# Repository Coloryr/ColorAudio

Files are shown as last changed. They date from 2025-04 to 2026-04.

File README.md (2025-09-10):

# ColorAudio

通用耳放，目前支持：
- 音乐播放
  - MP3音频解码，信息显示
  - FLAC音频解码，信息显示
- 蓝牙音频播放
  - SBC编码
  - AAC编码
  - aptx编码(freeaptx解码库)
- USB音频播放
  - UAC1 (最大96K 32bit，只能设置一种采样大小)
  - UAV2 (最大192K 32bit，支持多种采样大小)

主控RK3506，DAC：cs43198x2，运放：opa1622

linux6.1 RK的SDK

pcb目录是硬件原理图和PCB  
linux目录是RK SDK修补包  
src目录是软件程序源码

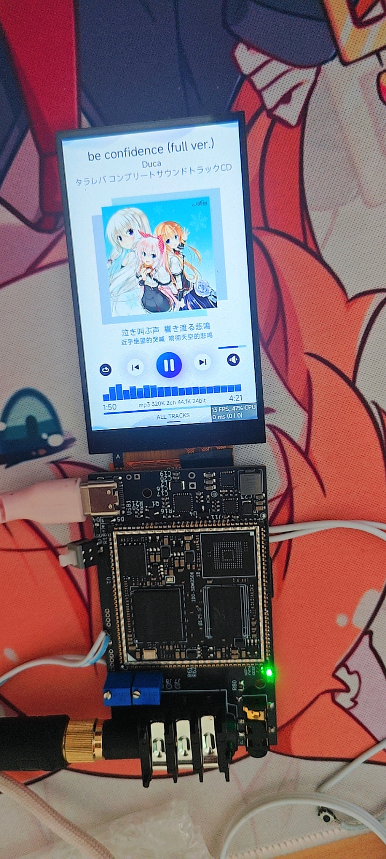
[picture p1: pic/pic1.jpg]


使用的其他开源代码库，直接使用代码编译  
| 名称  | 描述 | 链接 |
|---|---|---|
| Lvgl | 轻量界面框架 | [GitHub](https://github.com/lvgl/lvgl) |
| arduinoFFT | 快速傅里叶变换 | [GitHub](https://github.com/kosme/arduinoFFT) |
| nlohmann/json | json解析库 | [GitHub](https://github.com/nlohmann/json) |
| bluez-alsa | 蓝牙音频库 | [GitHub](https://github.com/arkq/bluez-alsa) |
| minimp4 | MP4文件解析 | [GitHub](https://github.com/lieff/minimp4) |
| ncmdump | ncm文件解析 | [GitHub](https://github.com/taurusxin/ncmdump) |

使用的开源库，使用链接方式  
| 名称  | 描述 | 链接 |
| libpng | png解码库 | [GitHub](https://github.com/pnggroup/libpng) |
| boost | C++库 | [boost](https://www.boost.org/) |
| flac | flac解码库 | [GitHub](https://github.com/xiph/flac) |
| libjpeg-turbo | jpeg解码库 | [GitHub](https://github.com/libjpeg-turbo/libjpeg-turbo) |
| libmad | MP3解码库 | [GitHub](https://github.com/markjeee/libmad) |
| openh264 | H264解码库 | [GitHub](https://github.com/cisco/openh264) |
| librime | 输入法 | [GitHub](https://github.com/rime/librime) |

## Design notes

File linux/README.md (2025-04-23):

sudo apt install flex bison bc libncurses-dev -y

# boot

export PATH=$PATH:~/Desktop/t113/arm-none-eabi/bin
git clone https://github.com/szemzoa/awboot
cd awboot
cd tools
gcc mksunxi.c -o mksunxi
cd ../
修改board.h的串口
make -j16

# linux
wget https://cdn.kernel.org/pub/linux/kernel/v6.x/linux-6.14.2.tar.xz
tar -xf linux-6.14.2.tar.xz
cd linux-6.14.2
export PATH=$PATH:~/Desktop/t113/arm-none-linux-gnueabihf/bin
make ARCH=arm CROSS_COMPILE=arm-none-linux-gnueabihf- sunxi_defconfig
make ARCH=arm CROSS_COMPILE=arm-none-linux-gnueabihf- menuconfig
make -j32 ARCH=arm CROSS_COMPILE=arm-none-linux-gnueabihf- zImage dtbs modules

# tina5
sudo apt install -y ack antlr3 asciidoc autoconf automake autopoint binutils bison build-essential \
bzip2 ccache cmake cpio curl device-tree-compiler fastjar flex gawk gettext gcc-multilib g++-multilib \
git gperf haveged help2man intltool libc6-dev-i386 libelf-dev libfuse-dev libglib2.0-dev libgmp3-dev \
libltdl-dev libmpc-dev libmpfr-dev libncurses5-dev libncursesw5-dev libpython3-dev libreadline-dev \
libssl-dev libtool lrzsz mkisofs msmtp ninja-build p7zip p7zip-full patch pkgconf python2.7 python3 \
python3-pyelftools python3-setuptools qemu-utils rsync scons squashfs-tools subversion swig texinfo \
uglifyjs upx-ucl unzip vim wget xmlto xxd zlib1g-dev

sudo -i
curl https://mirrors.bfsu.edu.cn/git/git-repo > /usr/bin/repo
chmod +x /usr/bin/repo
exit
echo export REPO_URL='https://mirrors.bfsu.edu.cn/git/git-repo' >> ~/.bashrc
source ~/.bashrc
git config --global credential.helper store 

mkdir tina-sdk
cd tina-sdk
repo init -u https://sdk.aw-ol.com/git_repo/D1_Tina_Open/manifest.git -b master -m tina-d1-h.xml
repo sync
repo start coloraudio --all
cd ../

git clone https://github.com/DongshanPI/100ASK_T113-PRO_TinaSDK5.git
cd 100ASK_T113-PRO_TinaSDK5
git submodule update --init 
cp ./* -rfvd ../tina-sdk
cd ../

git clone https://github.com/DongshanPI/100ASK_T113-Pro_TinaSDK.git
cd 100ASK_T113-Pro_TinaSDK 
git submodule update --init 
cp ./* -rfvd ../tina-sdk
cd ../

repo forall -vc "git status"
repo forall -vc "git reset --hard"

cd tina-sdk
source build/envsetup.sh
lunch

# buildroot
wget https://buildroot.org/downloads/buildroot-2025.02.tar.gz
tar -zxf buildroot-2025.02.tar.gz
cd buildroot-2025.02
make menuconfig

# xfel
https://github.com/xboot/xfel
xfel version
xfel spinand
xfel spinand erase 0 0x8000000
xfel spinand write 0 awboot-boot-spi.bin
xfel spinand write 0x40000 arch/arm/boot/dts/sun8i-t113s-coloraudio-t113-v1.dtb
xfel spinand write 0x80000 arch/arm/boot/zImage

xfel spinand erase 0x800000 0x7800000
xfel spinand write 0x800000 output/images/rootfs.ubi

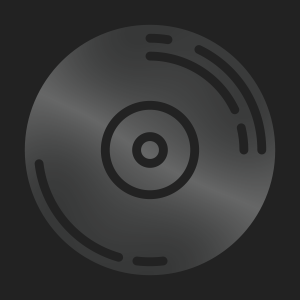
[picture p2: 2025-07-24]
ui/record.png

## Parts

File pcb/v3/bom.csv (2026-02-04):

Reference | Qty | Value | Footprint | 单价 | 总计
C1,C2,C3,C7,C8,C23,C25,C26,C27 | 9 | 22uF | Capacitor_SMD:C_0603_1608Metric_Pad1.08x0.95mm_HandSolder | 0.066 | 0.594
C4,C5,C10,C12,C13,C14,C18,C19,C20,C28,C42,C43,C51,C65,C74,C78 | 16 | 10uF | Capacitor_SMD:C_0402_1005Metric_Pad0.74x0.62mm_HandSolder | 0.0385 | 0.616
C6,C29,C32,C33,C34,C35,C37,C38,C41,C44,C45,C46,C50,C59,C60,C64,C80,C81 | 18 | 0.1uF | Capacitor_SMD:C_0402_1005Metric_Pad0.74x0.62mm_HandSolder | 0.0165 | 0.297
C9,C11,C15,C21,C22,C30,C31 | 7 | 1uF | Capacitor_SMD:C_0402_1005Metric_Pad0.74x0.62mm_HandSolder | 0.022 | 0.154
C16 | 1 | 47nF | Capacitor_SMD:C_0402_1005Metric_Pad0.74x0.62mm_HandSolder | 0.0165 | 0.0165
C17,C39 | 2 | 4.7uF | Capacitor_SMD:C_0402_1005Metric_Pad0.74x0.62mm_HandSolder | 0.033 | 0.066
C24 | 1 | 10nF | Capacitor_SMD:C_0402_1005Metric_Pad0.74x0.62mm_HandSolder | 0.0165 | 0.0165
C36,C79 | 2 | 10uF | Capacitor_SMD:C_0603_1608Metric_Pad1.08x0.95mm_HandSolder | 0.044 | 0.088
C40 | 1 | 100nF | Capacitor_SMD:C_0402_1005Metric_Pad0.74x0.62mm_HandSolder | 0.0165 | 0.0165
C47,C48,C49,C54,C55,C56,C57,C58,C61,C62,C63,C68,C69,C70,C71,C72 | 16 | 2.2uF | Capacitor_SMD:C_0402_1005Metric_Pad0.74x0.62mm_HandSolder | 0.0275 | 0.44
C52,C53,C66,C67 | 4 | 15uF | Capacitor_SMD:C_0402_1005Metric_Pad0.74x0.62mm_HandSolder | 0.2 | 0.8
C73,C77 | 2 | 1.0uF | Capacitor_SMD:C_0402_1005Metric_Pad0.74x0.62mm_HandSolder | 0.022 | 0.044
C75,C76 | 2 | 4.7nf | Capacitor_SMD:C_0805_2012Metric_Pad1.18x1.45mm_HandSolder | 0.055 | 0.11
CN1 | 1 | PJ-625G | coloryr:AUDIO-TH_PJ-625G | 3.02 | 3.02
D1,D4,D5,D16 | 4 | 1N5819 | Diode_SMD:D_SOD-323_HandSoldering | 0.033 | 0.132
D2,D3,D8,D9,D10,D11,D12,D13 | 8 | ESD9B5.0ST5G | Diode_SMD:D_SOD-523 | 0.044 | 0.352
D6,D7 | 2 | LED | Diode_SMD:D_0402_1005Metric_Pad0.77x0.64mm_HandSolder | 0.044 | 0.088
J1,J3,J5,J6,J7,J8,J11,J14,J15 | 9 | TestPoint | TestPoint:TestPoint_Pad_D1.0mm | 0 | 0
J2 | 1 | Conn_01x03 | Connector_PinHeader_1.27mm:PinHeader_1x03_P1.27mm_Vertical | 0 | 0
J4,J10 | 2 | Conn_01x02 | Connector_PinHeader_2.00mm:PinHeader_1x02_P2.00mm_Vertical | 0 | 0
J9 | 1 | Conn_01x02 | Connector_PinHeader_2.54mm:PinHeader_1x02_P2.54mm_Vertical | 0 | 0
J12 | 1 | Conn_01x04 | Connector_PinHeader_1.27mm:PinHeader_1x04_P1.27mm_Vertical | 0 | 0
J13 | 1 | Conn_01x05 | Connector_PinHeader_1.27mm:PinHeader_1x05_P1.27mm_Vertical | 0 | 0
L1,L2 | 2 | 2,2uH | Inductor_SMD:L_1008_2520Metric_Pad1.43x2.20mm_HandSolder | 0.3 | 0.6
L3 | 1 | 1.0uH | Inductor_SMD:L_Changjiang_FXL0530 | 0.39 | 0.39
L4 | 1 | 10uH | Inductor_SMD:L_TDK_NLV25_2.5x2.0mm | 0.3 | 0.3
P1 | 1 | LCD_MIPI | Connector_FFC-FPC:Hirose_FH12-24S-0.5SH_1x24-1MP_P0.50mm_Horizontal | 0.3 | 0.3
P2 | 1 | LCD_TOUCH | Connector_FFC-FPC:Hirose_FH12-6S-0.5SH_1x06-1MP_P0.50mm_Horizontal | 0.24 | 0.24
PJ1 | 1 | ~ | coloryr:AUDIO-IN-SMD_PJ-327A_C22355751 | 0.28 | 0.28
Q1 | 1 | NPN | coloryr:SOT-23 | 0.11 | 0.11
Q2 | 1 | PMOS | coloryr:SOT-23 | 1.21 | 1.21
Q3 | 1 | NMOS | coloryr:SOT-23 | 3.19 | 3.19
R1,R12,R59,R60,R63,R64,R81,R85,R90,R91 | 10 | 0 | Resistor_SMD:R_0402_1005Metric_Pad0.72x0.64mm_HandSolder | 0.0132 | 0.132
R2,R18,R19,R20,R22,R47,R75,R95 | 8 | 10K | Resistor_SMD:R_0402_1005Metric_Pad0.72x0.64mm_HandSolder | 0.0132 | 0.1056
R3,R4,R6,R51 | 4 | 100 | Resistor_SMD:R_0402_1005Metric_Pad0.72x0.64mm_HandSolder | 0.0132 | 0.0528
R5,R28,R29,R30,R31,R32,R33 | 7 | 4.7K | Resistor_SMD:R_0402_1005Metric_Pad0.72x0.64mm_HandSolder | 0.0132 | 0.0924
R7,R8 | 2 | 2.2R | Capacitor_SMD:C_0402_1005Metric_Pad0.74x0.62mm_HandSolder | 0.0132 | 0.0264
R9,R25 | 2 | 100K | Capacitor_SMD:C_0402_1005Metric_Pad0.74x0.62mm_HandSolder | 0.0132 | 0.0264
R10 | 1 | 750K | Capacitor_SMD:C_0402_1005Metric_Pad0.74x0.62mm_HandSolder | 0.0132 | 0.0132
R11 | 1 | 240K | Capacitor_SMD:C_0402_1005Metric_Pad0.74x0.62mm_HandSolder | 0.0132 | 0.0132
R13 | 1 | 220K | Capacitor_SMD:C_0402_1005Metric_Pad0.74x0.62mm_HandSolder | 0.0132 | 0.0132
R14 | 1 | 510K | Capacitor_SMD:C_0402_1005Metric_Pad0.74x0.62mm_HandSolder | 0.0132 | 0.0132
R15 | 1 | 260 | Capacitor_SMD:C_0402_1005Metric_Pad0.74x0.62mm_HandSolder | 0.0132 | 0.0132
R16,R17,R26,R27,R55,R57,R87 | 7 | 10K | Capacitor_SMD:C_0402_1005Metric_Pad0.74x0.62mm_HandSolder | 0.0132 | 0.0924
R21,R46 | 2 | 1K | Resistor_SMD:R_0402_1005Metric_Pad0.72x0.64mm_HandSolder | 0.0132 | 0.0264
R23 | 1 | 12K | Capacitor_SMD:C_0402_1005Metric_Pad0.74x0.62mm_HandSolder | 0.0132 | 0.0132
R24 | 1 | 390K | Capacitor_SMD:C_0402_1005Metric_Pad0.74x0.62mm_HandSolder | 0.0132 | 0.0132
R34,R35,R36,R37,R38,R39,R40,R41,R42,R43,R80,R88 | 12 | 4.7K | Capacitor_SMD:C_0402_1005Metric_Pad0.74x0.62mm_HandSolder | 0.0132 | 0.1584
R44,R93 | 2 | 330K | Resistor_SMD:R_0402_1005Metric_Pad0.72x0.64mm_HandSolder | 0.0132 | 0.0264
R45 | 1 | 10 | Resistor_SMD:R_0805_2012Metric | 0.0165 | 0.0165
R48 | 1 | 12K | Resistor_SMD:R_0402_1005Metric_Pad0.72x0.64mm_HandSolder | 0.0132 | 0.0132
R49 | 1 | 5.1K | Resistor_SMD:R_0402_1005Metric_Pad0.72x0.64mm_HandSolder | 0.0132 | 0.0132
R50 | 1 | 3K | Resistor_SMD:R_0402_1005Metric_Pad0.72x0.64mm_HandSolder | 0.0132 | 0.0132
R52 | 1 | 100K | Resistor_SMD:R_0402_1005Metric_Pad0.72x0.64mm_HandSolder | 0.0132 | 0.0132
R53 | 1 | 150K | Resistor_SMD:R_0402_1005Metric_Pad0.72x0.64mm_HandSolder | 0.0132 | 0.0132
R54,R56 | 2 | 3.3K | Capacitor_SMD:C_0402_1005Metric_Pad0.74x0.62mm_HandSolder | 0.0132 | 0.0264
R58 | 1 | 30K | Capacitor_SMD:C_0402_1005Metric_Pad0.74x0.62mm_HandSolder | 0.0132 | 0.0132
R61,R62,R65,R66 | 4 | 50 | Resistor_SMD:R_0805_2012Metric | 0.0165 | 0.066
R67,R69 | 2 | 510 | Resistor_SMD:R_0805_2012Metric | 0.0165 | 0.033
R68,R70 | 2 | 71.5 | Resistor_SMD:R_0805_2012Metric | 0.0165 | 0.033
R71,R72 | 2 | 82 | Resistor_SMD:R_0805_2012Metric | 0.0165 | 0.033
R73,R74,R76,R77,R78,R79 | 6 | 0 | Resistor_SMD:R_0805_2012Metric | 0.0165 | 0.099
R82,R83 | 2 | 5.1K | Capacitor_SMD:C_0402_1005Metric_Pad0.74x0.62mm_HandSolder | 0.0165 | 0.033
R84 | 1 | 22.6K | Capacitor_SMD:C_0402_1005Metric_Pad0.74x0.62mm_HandSolder | 0.0165 | 0.0165
R86 | 1 | 12.7K | Capacitor_SMD:C_0402_1005Metric_Pad0.74x0.62mm_HandSolder | 0.0165 | 0.0165
R89,R92,R94,R96,R97,R98 | 6 | 22 | Capacitor_SMD:C_0402_1005Metric_Pad0.74x0.62mm_HandSolder | 0.0165 | 0.099
RF1 | 1 | 6GHz | coloryr:IPEX-SMD_BWIPX-3-001E-1 | 0.38 | 0.38
RV1,RV2 | 2 | R_Potentiometer | Potentiometer_SMD:Potentiometer_Bourns_TC33X_Vertical | 1.9 | 3.8
TF1 | 1 | Micro_SD_Card_Det1 | coloryr:TF-SMD_TF-PUSH | 0.24 | 0.24
U1 | 1 | SOM3562_18 | coloryr:rk3506 | 65 | 65
U2 | 1 | TLV6213x | Package_DFN_QFN:VQFN-16-1EP_3x3mm_P0.5mm_EP1.68x1.68mm_ThermalVias | 1.81 | 1.81
U3 | 1 | RT9013 | Package_TO_SOT_SMD:SOT-23-5 | 0.48 | 0.48
U4 | 1 | BQ25895RTW | Package_DFN_QFN:Texas_RTW_WQFN-24-1EP_4x4mm_P0.5mm_EP2.7x2.7mm_ThermalVias | 4.7 | 4.7
U5 | 1 | LM27762 | Package_SON:WSON-12-1EP_3x2mm_P0.5mm_EP1x2.65_ThermalVias | 3.78 | 3.78
U6 | 1 | LP5907MFX-3.3 | Package_TO_SOT_SMD:SOT-23-5 | 0.42 | 0.42
U7 | 1 | TPS61230DRC | Package_SON:Texas_S-PVSON-N10_ThermalVias | 3 | 3
U8 | 1 | M8800DU6 | coloryr:BL_M8800DU6_40L | 15 | 15
U9 | 1 | SY6280 | Package_TO_SOT_SMD:SOT-23-5 | 0.31 | 0.31
U10 | 1 | STI9287 | Package_TO_SOT_SMD:SOT-23-6_Handsoldering | 0.24 | 0.24
U11 | 1 | TXS0102DCU | Package_SON:X2SON-8_1.4x1mm_P0.35mm | 0.69 | 0.69
U12 | 1 | SN74AVC4T245PW | Package_DFN_QFN:UQFN-16_1.8x2.6mm_P0.4mm | 0.99 | 0.99
U13 | 1 | TS3A227E | Package_DFN_QFN:Texas_RVA_VQFN-16-1EP_3.5x3.5mm_P0.5mm_EP2.14x2.14mm | 5.93 | 5.93
U14,U15 | 2 | CS43198 | Package_DFN_QFN:QFN-40-1EP_5x5mm_P0.4mm_EP3.6x3.6mm_ThermalVias | 19 | 38
U16 | 1 | OPA1622 | Package_SON:Texas_S-PVSON-N10 | 5.68 | 5.68
USB1 | 1 | USB_C_Plug_USB2.0 | Connector_USB:USB_C_Receptacle_GCT_USB4105-xx-A_16P_TopMnt_Horizontal | 0.17 | 0.17
Y1 | 1 | 24.576M | Oscillator:Oscillator_SMD_ECS_2520MV-xxx-xx-4Pin_2.5x2.0mm | 1.8 | 1.8
LCD1 | 1 | D310T9362V1 |  | 65 | 65
BAT | 1 | 8000mah |  | 20 | 20
 |  |  |  |  | 252.2732

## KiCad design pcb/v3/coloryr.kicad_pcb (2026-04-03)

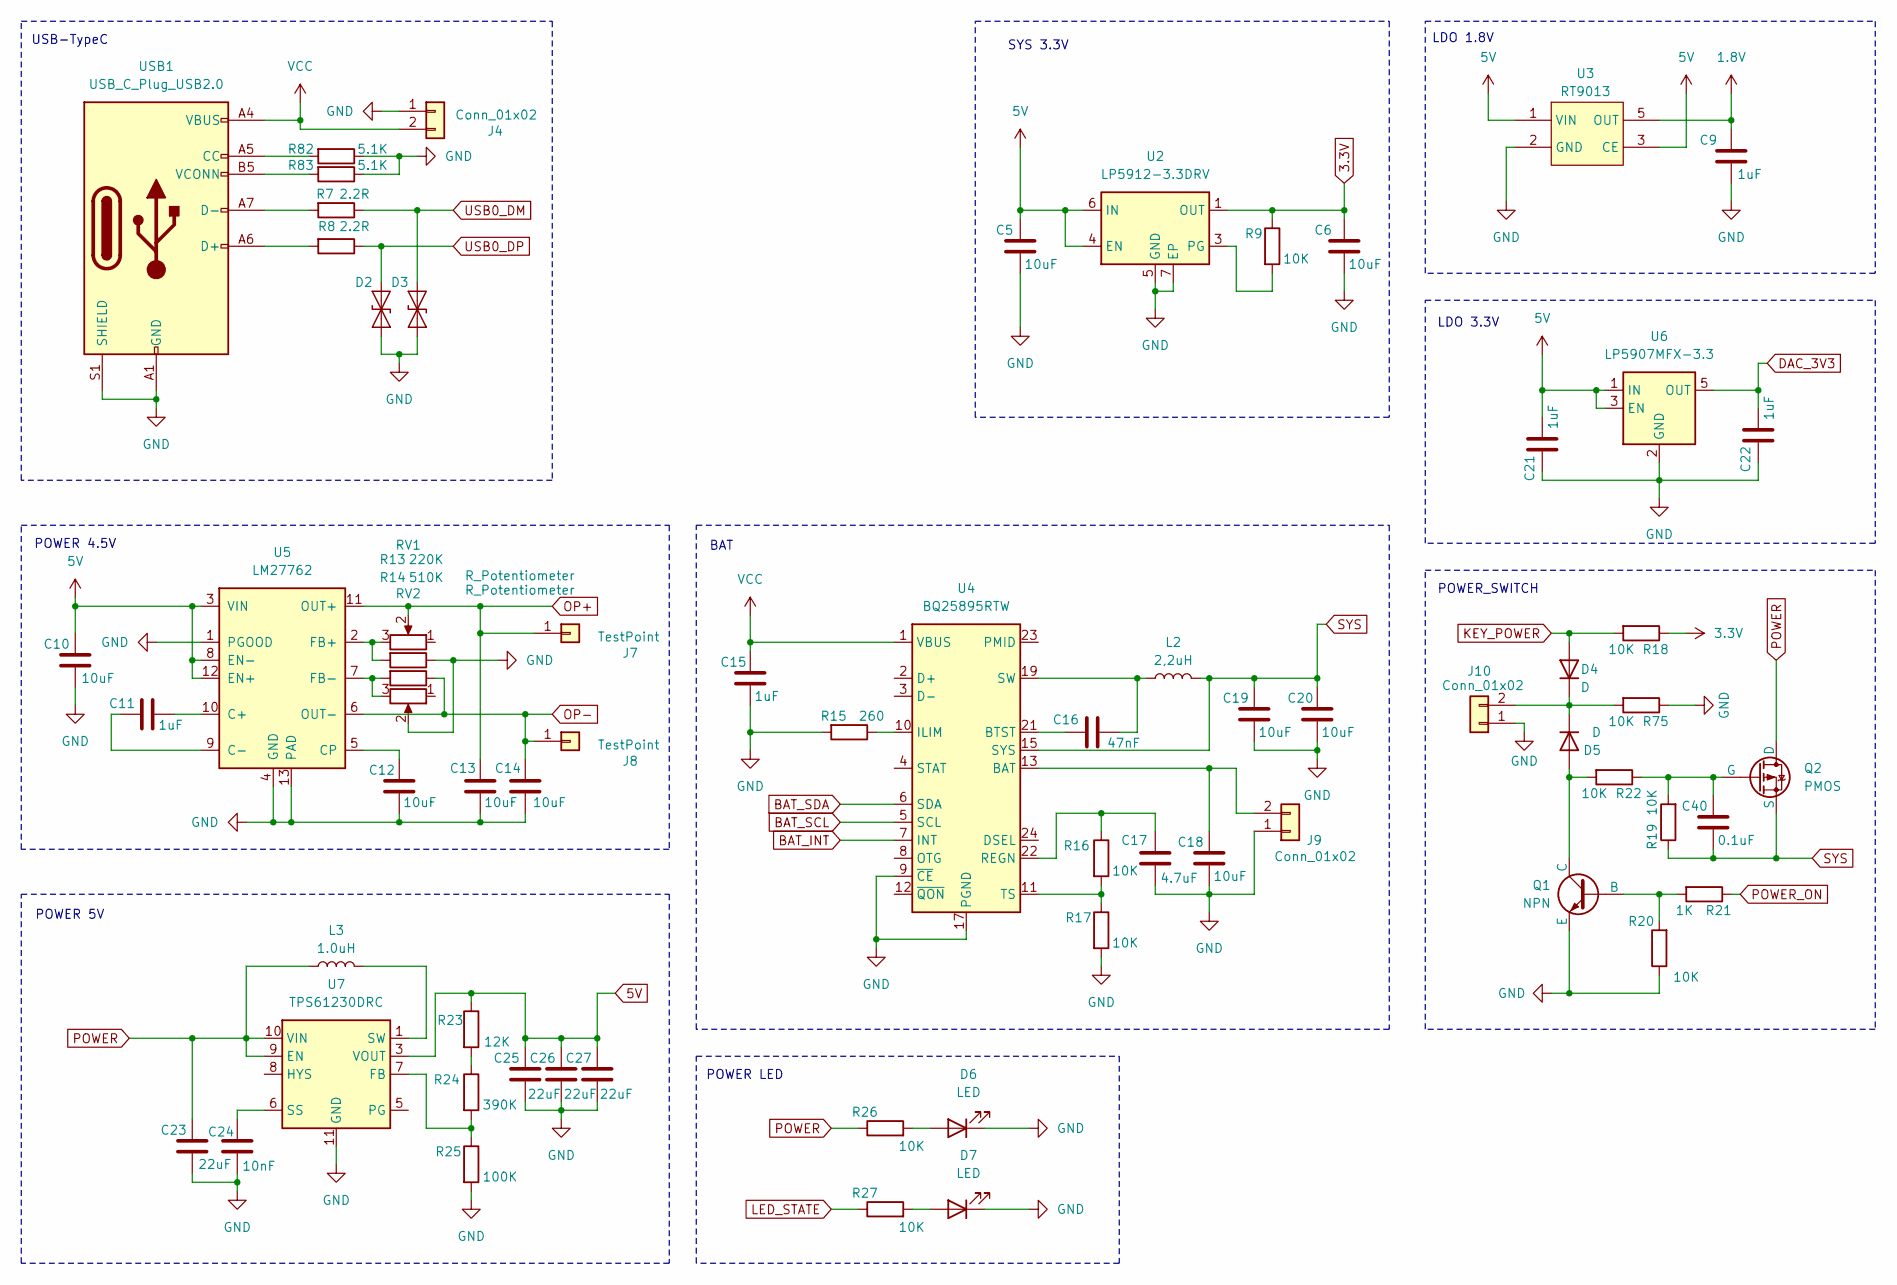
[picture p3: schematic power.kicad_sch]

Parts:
C5, C6, C10, C12, C13, C14, C18, C19, C20: 10uF; C_0402_1005Metric_Pad0.74x0.62mm_HandSolder
C9, C11, C15, C21, C22: 1uF; C_0402_1005Metric_Pad0.74x0.62mm_HandSolder
C16: 47nF; C_0402_1005Metric_Pad0.74x0.62mm_HandSolder
C17: 4.7uF; C_0402_1005Metric_Pad0.74x0.62mm_HandSolder
C23, C25, C26, C27: 22uF; C_0603_1608Metric_Pad1.08x0.95mm_HandSolder
C24: 10nF; C_0402_1005Metric_Pad0.74x0.62mm_HandSolder
C40: 0.1uF; C_0402_1005Metric_Pad0.74x0.62mm_HandSolder
D2, D3: ESD9B5.0ST5G; D_SOD-523
D4, D5: D; D_SOD-323_HandSoldering
D6, D7: LED; D_0402_1005Metric_Pad0.77x0.64mm_HandSolder
J4, J10: Conn_01x02; PinHeader_1x02_P2.00mm_Vertical
J7, J8: TestPoint; TestPoint_Pad_D1.0mm
J9: Conn_01x02; PinHeader_1x02_P2.54mm_Vertical
L2: 2,2uH; L_1008_2520Metric_Pad1.43x2.20mm_HandSolder
L3: 1.0uH; L_Changjiang_FXL0530
Q1: NPN; SOT-23
Q2: PMOS; SOT-23
R7, R8: 2.2R; C_0402_1005Metric_Pad0.74x0.62mm_HandSolder
R9, R16, R17, R26, R27: 10K; C_0402_1005Metric_Pad0.74x0.62mm_HandSolder
R13: 220K; C_0402_1005Metric_Pad0.74x0.62mm_HandSolder
R14: 510K; C_0402_1005Metric_Pad0.74x0.62mm_HandSolder
R15: 260; C_0402_1005Metric_Pad0.74x0.62mm_HandSolder
R18, R19, R20, R22, R75: 10K; R_0402_1005Metric_Pad0.72x0.64mm_HandSolder
R21: 1K; R_0402_1005Metric_Pad0.72x0.64mm_HandSolder
R23: 12K; C_0402_1005Metric_Pad0.74x0.62mm_HandSolder
R24: 390K; C_0402_1005Metric_Pad0.74x0.62mm_HandSolder
R25: 100K; C_0402_1005Metric_Pad0.74x0.62mm_HandSolder
R82, R83: 5.1K; C_0402_1005Metric_Pad0.74x0.62mm_HandSolder
RV1, RV2: R_Potentiometer; Potentiometer_Bourns_TC33X_Vertical
U2: LP5912-3.3DRV; WSON-6-1EP_2x2mm_P0.65mm_EP1x1.6mm_ThermalVias
U3: RT9013; SOT-23-5
U4: BQ25895RTW; Texas_RTW_WQFN-24-1EP_4x4mm_P0.5mm_EP2.7x2.7mm_ThermalVias
U5: LM27762; WSON-12-1EP_3x2mm_P0.5mm_EP1x2.65_ThermalVias
U6: LP5907MFX-3.3; SOT-23-5
U7: TPS61230DRC; Texas_S-PVSON-N10_ThermalVias
USB1: USB_C_Plug_USB2.0; USB_C_Receptacle_GCT_USB4105-xx-A_16P_TopMnt_Horizontal

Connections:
1.8V: C9.1, U3.5 (OUT); also elsewhere on the board
3.3V: C6.1, R9.1, R18.1, U2.1 (OUT); also elsewhere on the board
5V: C5.1, C10.1, C21.1, C25.1, C26.1, C27.1, R23.1, U2.4 (EN), U2.6 (IN), U3.1 (VIN), U3.3 (CE), U5.3 (VIN), U5.8 (EN-), U5.12 (EN+), U6.1 (IN), U6.3 (EN), U7.3 (VOUT), U7.4 (VOUT); also elsewhere on the board
BAT_INT: U4.7 (INT); also elsewhere on the board
BAT_SCL: U4.5 (SCL); also elsewhere on the board
BAT_SDA: U4.6 (SDA); also elsewhere on the board
DAC_3V3: C22.1, U6.5 (OUT); also elsewhere on the board
GND: C5.2, C6.2, C9.2, C10.2, C12.1, C13.1, C14.1, C15.2, C17.1, C18.2, C19.2, C20.2, C21.2, C22.2, C23.2, C24.1, C25.2, C26.2, C27.2, D2.1 (A1), D3.1 (A1), D6.1 (K), D7.1 (K), J4.1, J9.1, J10.1, Q1.3 (E), R13.1, R15.2, R17.2, R20.1, R25.2, R75.1, R82.1, R83.1, RV2.2, U2.5 (GND), U2.7 (EP), U3.2 (GND), U4.9 (~CE), U4.17 (PGND), U4.18 (PGND), U4.25 (PGND), U5.1 (PGOOD), U5.4 (GND), U5.13 (PAD), U6.2 (GND), U7.11 (GND), USB1.A1 (GND), USB1.A12 (GND), USB1.B1 (GND), USB1.B12 (GND), USB1.S1 (SHIELD); also elsewhere on the board
KEY_POWER: D4.2 (A), R18.2; also elsewhere on the board
LED_STATE: R27.1; also elsewhere on the board
unnamed: C16.2, L2.1, U4.19 (SW), U4.20 (SW)
unnamed: D4.1 (K), D5.1 (K), J10.2, R75.2
unnamed: D5.2 (A), Q1.1 (C), R22.2
unnamed: D6.2 (A), R26.2
unnamed: D7.2 (A), R27.2
unnamed: C18.1, J9.2, U4.13 (BAT), U4.14 (BAT)
unnamed: L3.2, U7.1 (SW), U7.2 (SW)
unnamed: Q1.2 (B), R20.2, R21.2
unnamed: C40.1, Q2.2 (G), R19.2, R22.1
unnamed: R7.2, USB1.A7 (D-), USB1.B7 (D-)
unnamed: R8.2, USB1.A6 (D+), USB1.B6 (D+)
unnamed: R23.2, R24.1
unnamed: R9.2, U2.3 (PG)
unnamed: C16.1, U4.21 (BTST)
unnamed: R15.1, U4.10 (ILIM)
unnamed: C17.2, R16.1, U4.22 (REGN)
unnamed: R16.2, R17.1, U4.11 (TS)
unnamed: C11.2, U5.10 (C+)
unnamed: C11.1, U5.9 (C-)
unnamed: C12.2, U5.5 (CP)
unnamed: R13.2, RV1.3, U5.2 (FB+)
unnamed: R14.2, RV2.3, U5.7 (FB-)
unnamed: R24.2, R25.1, U7.7 (FB)
unnamed: C24.2, U7.6 (SS)
unnamed: R82.2, USB1.A5 (CC)
unnamed: R83.2, USB1.B5 (VCONN)
OP+: C13.2, J7.1, RV1.2, U5.11 (OUT+); also elsewhere on the board
OP-: C14.2, J8.1, R14.1, U5.6 (OUT-); also elsewhere on the board
POWER: C23.1, L3.1, Q2.1 (D), R26.1, U7.9 (EN), U7.10 (VIN)
POWER_ON: R21.1; also elsewhere on the board
SYS: C19.1, C20.1, C40.2, L2.2, Q2.3 (S), R19.1, U4.15 (SYS), U4.16 (SYS)
USB0_DM: D3.2 (A2), R7.1; also elsewhere on the board
USB0_DP: D2.2 (A2), R8.1; also elsewhere on the board
VCC: C15.1, J4.2, U4.1 (VBUS), USB1.A4 (VBUS), USB1.A9 (VBUS), USB1.B4 (VBUS), USB1.B9 (VBUS); also elsewhere on the board

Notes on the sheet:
POWER LED
BAT
LDO 3.3V
POWER_SWITCH
LDO 1.8V
SYS 3.3V
POWER 4.5V
USB-TypeC
POWER 5V

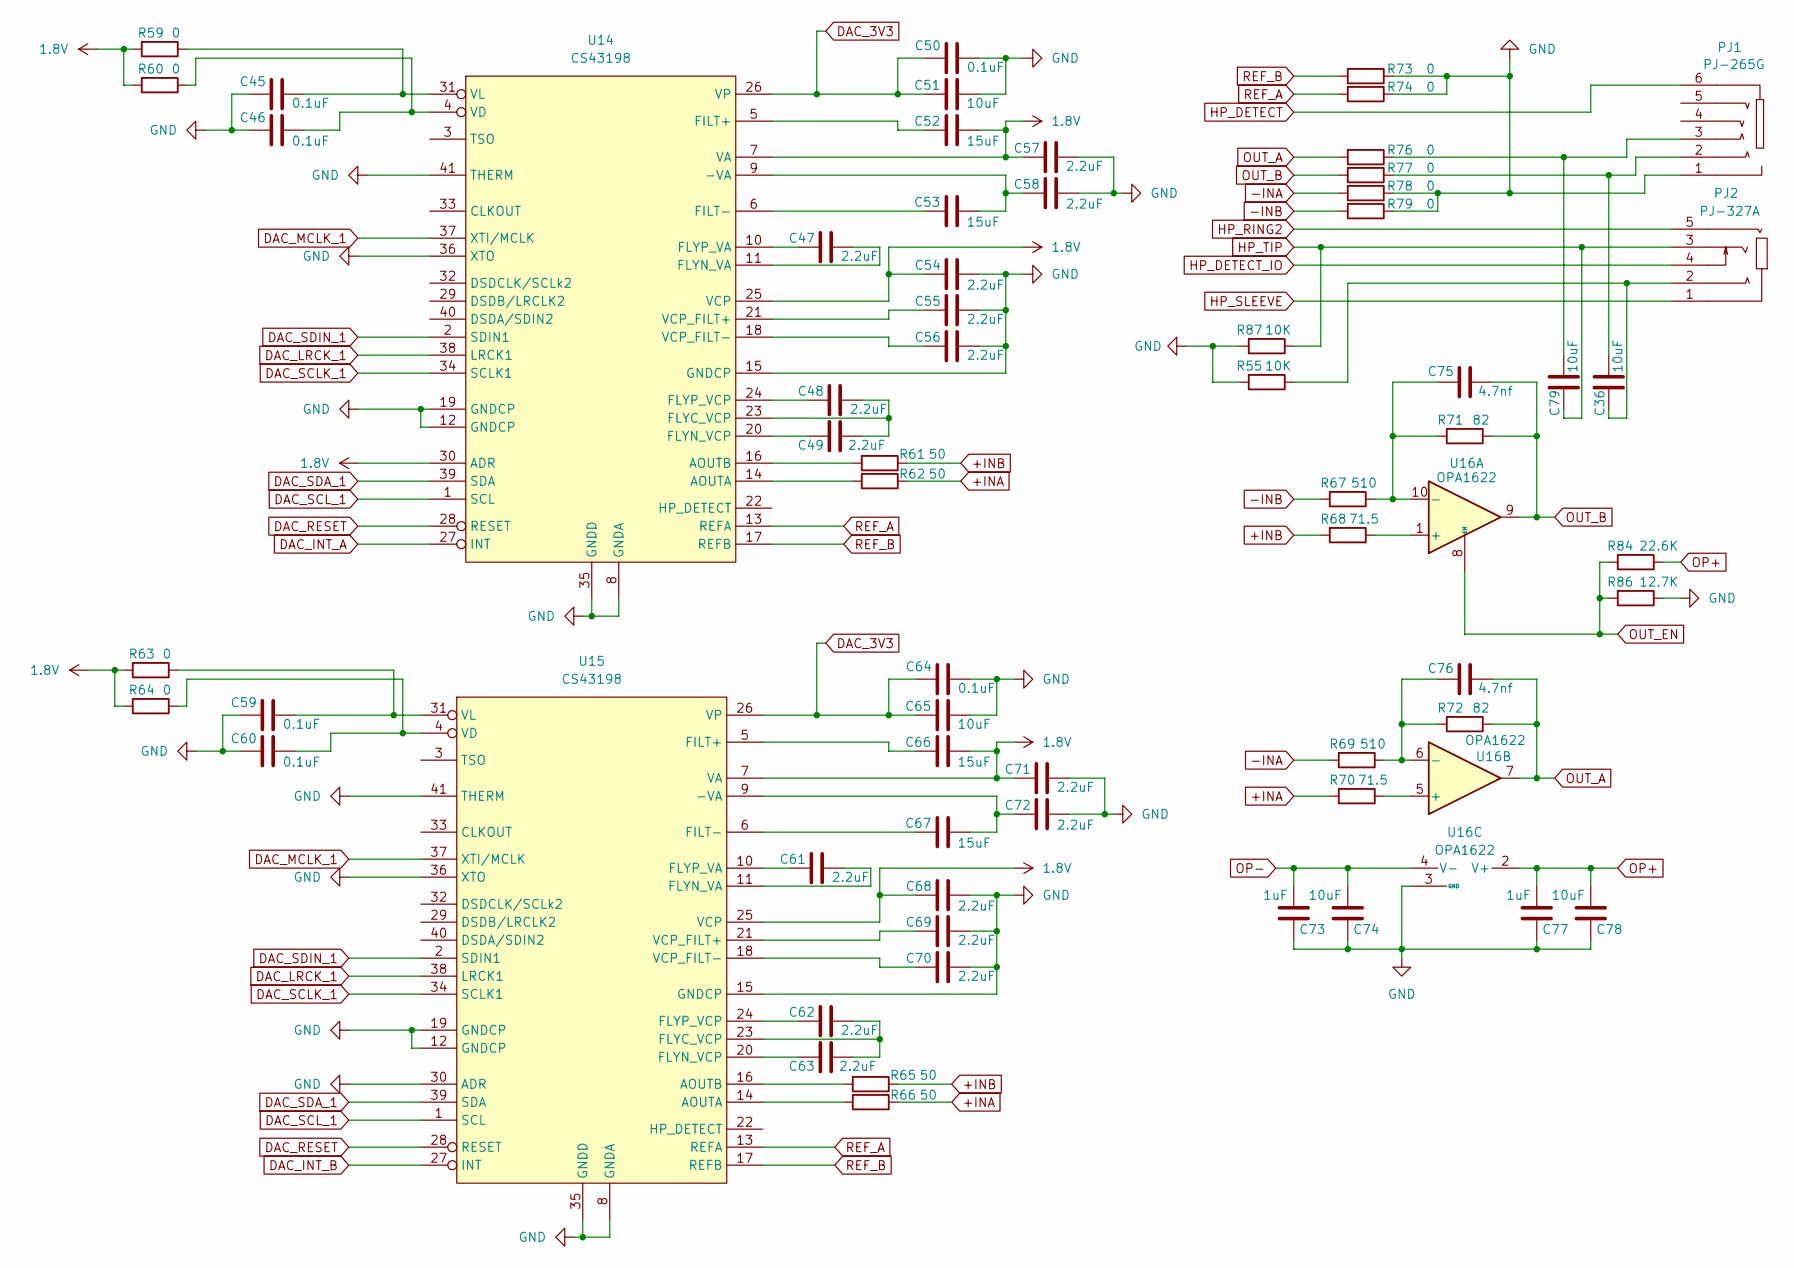
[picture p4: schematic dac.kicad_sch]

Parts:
C36, C79: 10uF; C_0603_1608Metric_Pad1.08x0.95mm_HandSolder
C45, C46, C50, C59, C60, C64: 0.1uF; C_0402_1005Metric_Pad0.74x0.62mm_HandSolder
C47, C48, C49, C54, C55, C56, C57, C58, C61, C62, C63, C68, C69, C70, C71, C72: 2.2uF; C_0402_1005Metric_Pad0.74x0.62mm_HandSolder
C51, C65, C74, C78: 10uF; C_0402_1005Metric_Pad0.74x0.62mm_HandSolder
C52, C53, C66, C67: 15uF; C_0402_1005Metric_Pad0.74x0.62mm_HandSolder
C73, C77: 1uF; C_0402_1005Metric_Pad0.74x0.62mm_HandSolder
C75, C76: 4.7nf; C_0805_2012Metric_Pad1.18x1.45mm_HandSolder
PJ1: PJ-265G; PinHeader_1x06_P2.54mm_Vertical
PJ2: PJ-327A; PinHeader_1x05_P2.54mm_Vertical; Manufacturer Part PJ-327A; LCSC Part Name 3.5mm耳机座
R55, R87: 10K; C_0402_1005Metric_Pad0.74x0.62mm_HandSolder
R59, R60, R63, R64: 0; R_0402_1005Metric_Pad0.72x0.64mm_HandSolder
R61, R62, R65, R66: 50; R_0805_2012Metric
R67, R69: 510; R_0805_2012Metric
R68, R70: 71.5; R_0805_2012Metric
R71, R72: 82; R_0805_2012Metric
R73, R74, R76, R77, R78, R79: 0; R_0805_2012Metric
R84: 22.6K; C_0402_1005Metric_Pad0.74x0.62mm_HandSolder
R86: 12.7K; C_0402_1005Metric_Pad0.74x0.62mm_HandSolder
U14, U15: CS43198; QFN-40-1EP_5x5mm_P0.4mm_EP3.6x3.6mm_ThermalVias
U16: OPA1622; Texas_S-PVSON-N10

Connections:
1.8V: C52.2, C54.2, C57.2, C66.2, C68.2, C71.2, R59.2, R60.2, R63.2, R64.2, U14.7 (VA), U14.25 (VCP), U14.30 (ADR), U15.7 (VA), U15.25 (VCP); also elsewhere on the board
+INA: R62.1, R66.1, R70.2
+INB: R61.1, R65.1, R68.2
-INA: R69.2, R78.2
-INB: R67.2, R79.2
DAC_3V3: C50.2, C51.1, C64.2, C65.1, U14.26 (VP), U15.26 (VP); also elsewhere on the board
DAC_INT_A: U14.27 (INT); also elsewhere on the board
DAC_INT_B: U15.27 (INT); also elsewhere on the board
DAC_LRCK_1: U14.38 (LRCK1), U15.38 (LRCK1); also elsewhere on the board
DAC_MCLK_1: U14.37 (XTI/MCLK), U15.37 (XTI/MCLK); also elsewhere on the board
DAC_RESET: U14.28 (RESET), U15.28 (RESET); also elsewhere on the board
DAC_SCLK_1: U14.34 (SCLK1), U15.34 (SCLK1); also elsewhere on the board
DAC_SCL_1: U14.1 (SCL), U15.1 (SCL); also elsewhere on the board
DAC_SDA_1: U14.39 (SDA), U15.39 (SDA); also elsewhere on the board
DAC_SDIN_1: U14.2 (SDIN1), U15.2 (SDIN1); also elsewhere on the board
GND: C45.2, C46.2, C50.1, C51.2, C54.1, C55.1, C56.1, C57.1, C58.1, C59.2, C60.2, C64.1, C65.2, C68.1, C69.1, C70.1, C71.1, C72.1, C73.1, C74.1, C77.1, C78.1, PJ1.1, R55.2, R73.1, R74.1, R78.1, R79.1, R86.1, R87.2, U14.8 (GNDA), U14.12 (GNDCP), U14.15 (GNDCP), U14.19 (GNDCP), U14.35 (GNDD), U14.36 (XTO), U14.41 (THERM), U15.8 (GNDA), U15.12 (GNDCP), U15.15 (GNDCP), U15.19 (GNDCP), U15.30 (ADR), U15.35 (GNDD), U15.36 (XTO), U15.41 (THERM), U16.3 (GND); also elsewhere on the board
HP_DETECT: PJ1.6; also elsewhere on the board
HP_DETECT_IO: PJ2.4; also elsewhere on the board
HP_RING2: PJ2.5; also elsewhere on the board
HP_SLEEVE: PJ2.1; also elsewhere on the board
HP_TIP: C79.1, PJ2.3, R87.1; also elsewhere on the board
unnamed: C36.1, PJ2.2, R55.1
unnamed: C36.2, PJ1.2, R77.1
unnamed: C79.2, PJ1.3, R76.1
unnamed: C53.2, C58.2, U14.9 (-VA)
unnamed: R62.2, U14.14 (AOUTA)
unnamed: R61.2, U14.16 (AOUTB)
unnamed: C52.1, U14.5 (FILT+)
unnamed: C53.1, U14.6 (FILT-)
unnamed: C48.1, C49.1, U14.23 (FLYC_VCP)
unnamed: C47.1, U14.11 (FLYN_VA)
unnamed: C49.2, U14.20 (FLYN_VCP)
unnamed: C47.2, U14.10 (FLYP_VA)
unnamed: C48.2, U14.24 (FLYP_VCP)
unnamed: C55.2, U14.21 (VCP_FILT+)
unnamed: C56.2, U14.18 (VCP_FILT-)
unnamed: C46.1, R60.1, U14.4 (VD)
unnamed: C45.1, R59.1, U14.31 (VL)
unnamed: C67.2, C72.2, U15.9 (-VA)
unnamed: R66.2, U15.14 (AOUTA)
unnamed: R65.2, U15.16 (AOUTB)
unnamed: C66.1, U15.5 (FILT+)
unnamed: C67.1, U15.6 (FILT-)
unnamed: C62.1, C63.1, U15.23 (FLYC_VCP)
unnamed: C61.1, U15.11 (FLYN_VA)
unnamed: C63.2, U15.20 (FLYN_VCP)
unnamed: C61.2, U15.10 (FLYP_VA)
unnamed: C62.2, U15.24 (FLYP_VCP)
unnamed: C69.2, U15.21 (VCP_FILT+)
unnamed: C70.2, U15.18 (VCP_FILT-)
unnamed: C60.1, R64.1, U15.4 (VD)
unnamed: C59.1, R63.1, U15.31 (VL)
unnamed: R68.1, U16.1 (+)
unnamed: C75.2, R67.1, R71.2, U16.10 (-)
unnamed: R70.1, U16.5 (+)
unnamed: C76.2, R69.1, R72.2, U16.6 (-)
OP+: C77.2, C78.2, R84.1, U16.2 (V+); also elsewhere on the board
OP-: C73.2, C74.2, U16.4 (V-), U16.11 (V-); also elsewhere on the board
OUT_A: C76.1, R72.1, R76.2, U16.7
OUT_B: C75.1, R71.1, R77.2, U16.9
OUT_EN: R84.2, R86.2, U16.8 (EN); also elsewhere on the board
REF_A: R74.2, U14.13 (REFA), U15.13 (REFA)
REF_B: R73.2, U14.17 (REFB), U15.17 (REFB)

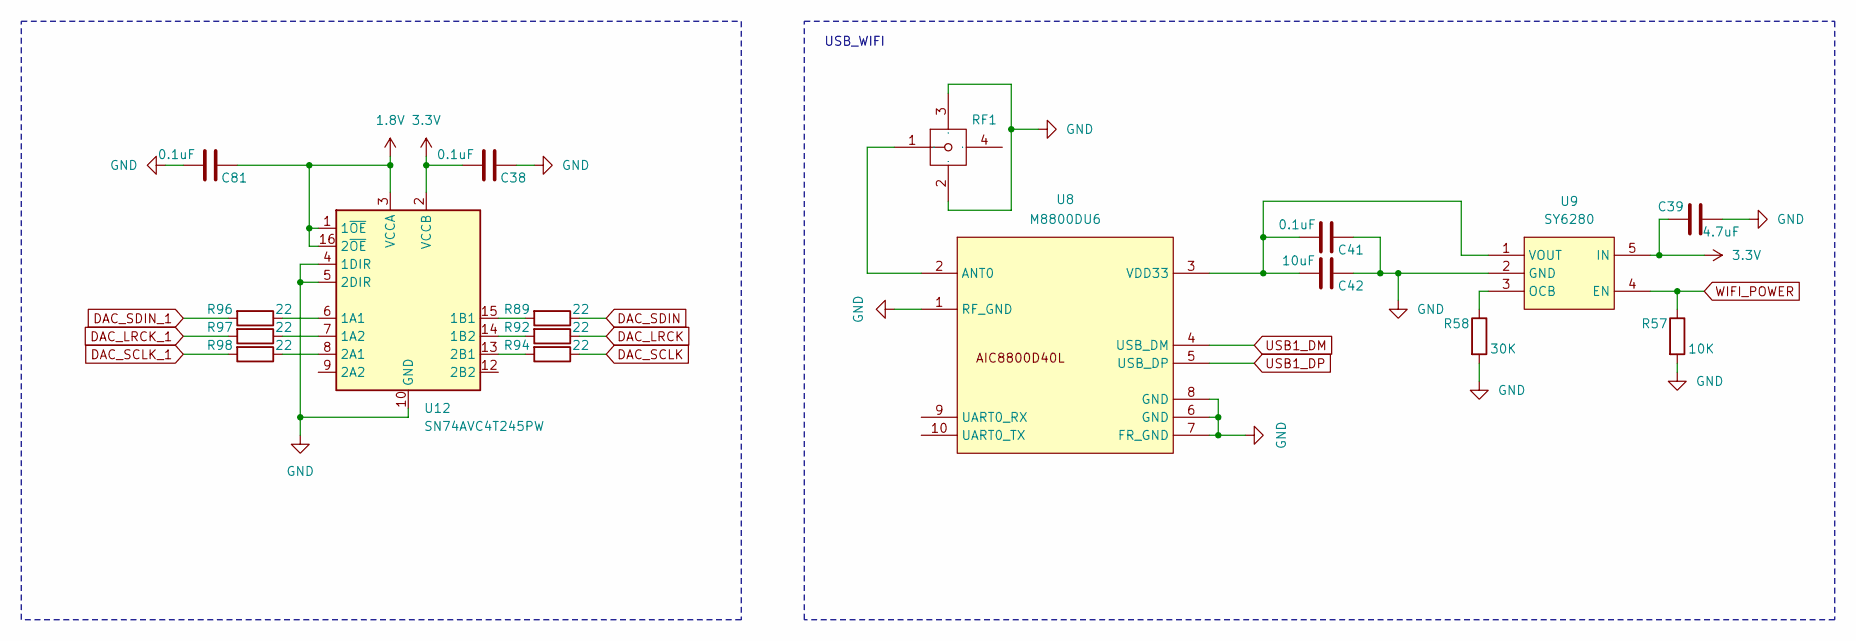
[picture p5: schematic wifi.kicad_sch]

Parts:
C38, C41, C81: 0.1uF; C_0402_1005Metric_Pad0.74x0.62mm_HandSolder
C39: 4.7uF; C_0402_1005Metric_Pad0.74x0.62mm_HandSolder
C42: 10uF; C_0402_1005Metric_Pad0.74x0.62mm_HandSolder
R57: 10K; C_0402_1005Metric_Pad0.74x0.62mm_HandSolder
R58: 30K; C_0402_1005Metric_Pad0.74x0.62mm_HandSolder
R89, R92, R94, R96, R97, R98: 22; C_0402_1005Metric_Pad0.74x0.62mm_HandSolder
RF1: 6GHz; IPEX-SMD_BWIPX-3-001E-1; Manufacturer Part BWIPX-3-001E; LCSC Part Name IPEX 内针
U8: M8800DU6; BL_M8800DU6_40L
U9: SY6280; SOT-23-5
U12: SN74AVC4T245PW; UQFN-16_1.8x2.6mm_P0.4mm

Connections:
1.8V: C81.2, U12.1 (1~OE), U12.3 (VCCA), U12.16 (2~OE); also elsewhere on the board
3.3V: C38.1, C39.1, U9.5 (IN), U12.2 (VCCB); also elsewhere on the board
DAC_LRCK: R92.1; also elsewhere on the board
DAC_LRCK_1: R97.2; also elsewhere on the board
DAC_SCLK: R94.1; also elsewhere on the board
DAC_SCLK_1: R98.2; also elsewhere on the board
DAC_SDIN: R89.1; also elsewhere on the board
DAC_SDIN_1: R96.2; also elsewhere on the board
GND: C38.2, C39.2, C41.1, C42.1, C81.1, R57.2, R58.2, RF1.2, RF1.3, U8.1 (RF_GND), U8.6 (GND), U8.7 (FR_GND), U8.8 (GND), U9.2 (GND), U12.4 (1DIR), U12.5 (2DIR), U12.10 (GND), U12.11 (GND); also elsewhere on the board
unnamed: RF1.1, U8.2 (ANT0)
unnamed: C41.2, C42.2, U8.3 (VDD33), U9.1 (VOUT)
unnamed: R58.1, U9.3 (OCB)
unnamed: R96.1, U12.6 (1A1)
unnamed: R97.1, U12.7 (1A2)
unnamed: R89.2, U12.15 (1B1)
unnamed: R92.2, U12.14 (1B2)
unnamed: R98.1, U12.8 (2A1)
unnamed: R94.2, U12.13 (2B1)
USB1_DM: U8.4 (USB_DM); also elsewhere on the board
USB1_DP: U8.5 (USB_DP); also elsewhere on the board
WIFI_POWER: R57.1, U9.4 (EN); also elsewhere on the board

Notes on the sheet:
USB_WIFI

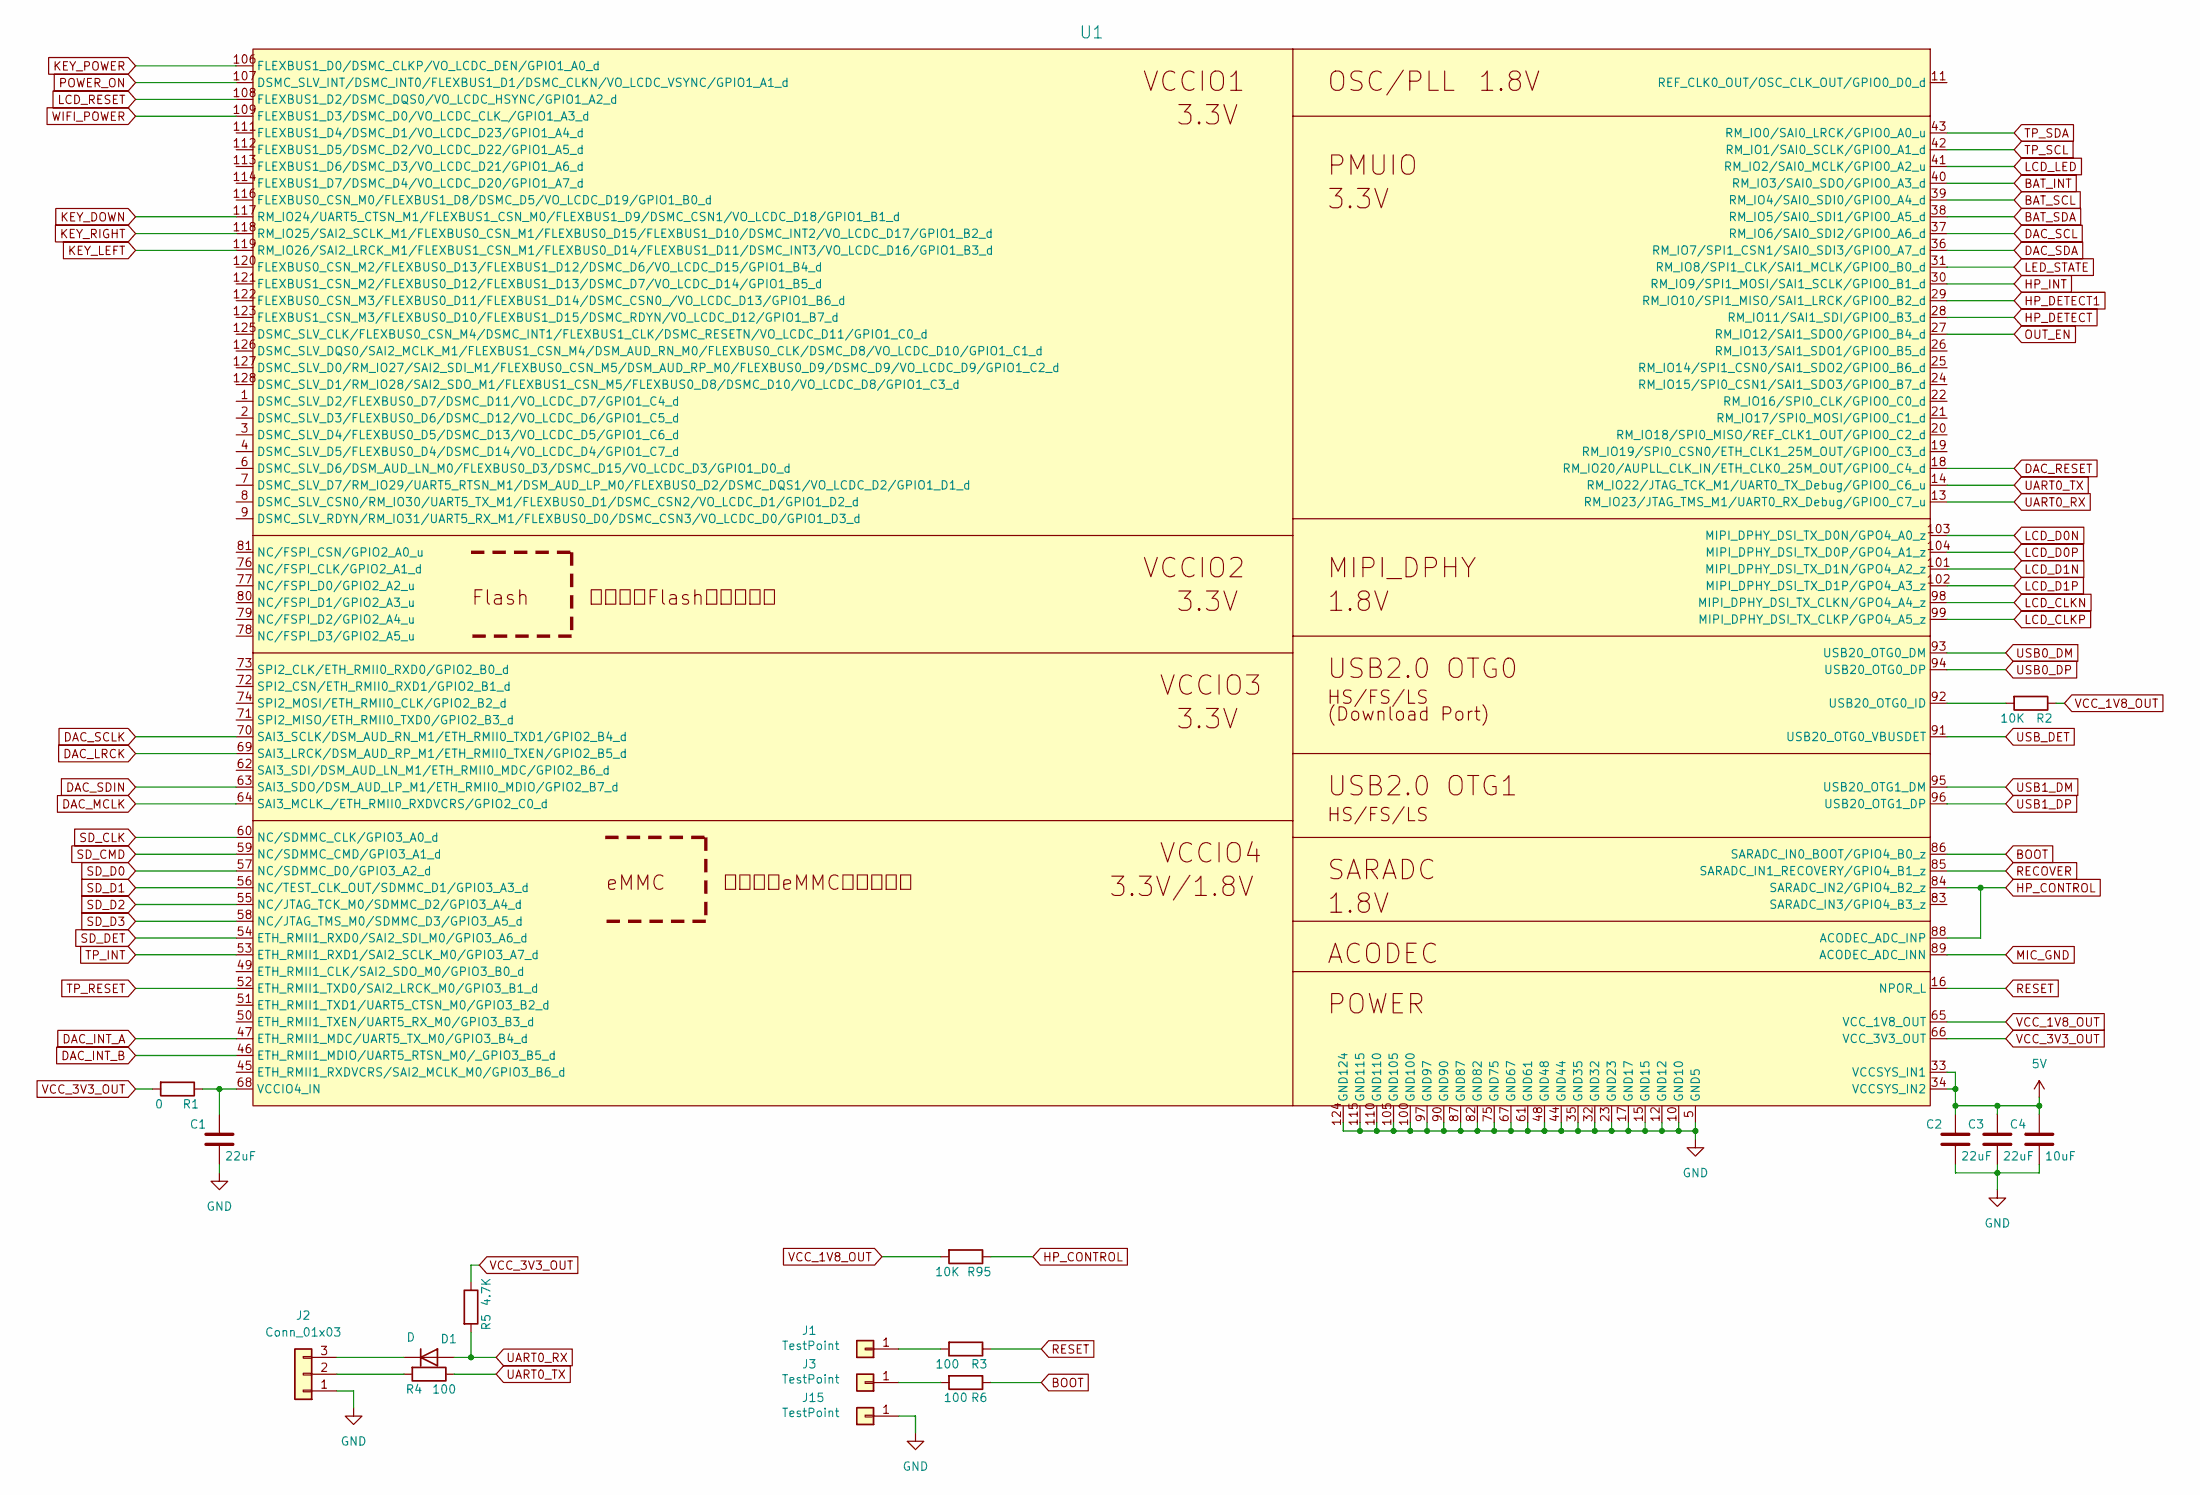
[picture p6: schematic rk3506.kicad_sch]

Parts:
C1, C2, C3: 22uF; C_0603_1608Metric_Pad1.08x0.95mm_HandSolder
C4: 10uF; C_0402_1005Metric_Pad0.74x0.62mm_HandSolder
D1: D; D_SOD-323_HandSoldering
J1, J3, J15: TestPoint; TestPoint_Pad_D1.0mm
J2: Conn_01x03; PinHeader_1x03_P1.27mm_Vertical
R1: 0; R_0402_1005Metric_Pad0.72x0.64mm_HandSolder
R2, R95: 10K; R_0402_1005Metric_Pad0.72x0.64mm_HandSolder
R3, R4, R6: 100; R_0402_1005Metric_Pad0.72x0.64mm_HandSolder
R5: 4.7K; R_0402_1005Metric_Pad0.72x0.64mm_HandSolder
U1: SOM3562_18; rk3506

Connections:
5V: C2.1, C3.1, C4.1, U1.33 (VCCSYS_IN1), U1.34 (VCCSYS_IN2); also elsewhere on the board
BAT_INT: U1.40 (RM_IO3/SAI0_SDO/GPIO0_A3_d); also elsewhere on the board
BAT_SCL: U1.39 (RM_IO4/SAI0_SDI0/GPIO0_A4_d); also elsewhere on the board
BAT_SDA: U1.38 (RM_IO5/SAI0_SDI1/GPIO0_A5_d); also elsewhere on the board
BOOT: R6.1, U1.86 (SARADC_IN0_BOOT/GPIO4_B0_z)
DAC_INT_A: U1.47 (ETH_RMII1_MDC/UART5_TX_M0/GPIO3_B4_d); also elsewhere on the board
DAC_INT_B: U1.46 (ETH_RMII1_MDIO/UART5_RTSN_M0/_GPIO3_B5_d); also elsewhere on the board
DAC_LRCK: U1.69 (SAI3_LRCK/DSM_AUD_RP_M1/ETH_RMII0_TXEN/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); also elsewhere on the board
DAC_MCLK: U1.64 (SAI3_MCLK_/ETH_RMII0_RXDVCRS/GPIO2_C0_d); also elsewhere on the board
DAC_RESET: U1.18 (RM_IO20/AUPLL_CLK_IN/ETH_CLK0_25M_OUT/G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); also elsewhere on the board
DAC_SCL: U1.37 (RM_IO6/SAI0_SDI2/GPIO0_A6_d); also elsewhere on the board
DAC_SCLK: U1.70 (SAI3_SCLK/DSM_AUD_RN_M1/ETH_RMII0_TXD1/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); also elsewhere on the board
DAC_SDA: U1.36 (RM_IO7/SPI1_CSN1/SAI0_SDI3/GPIO0_A7_d); also elsewhere on the board
DAC_SDIN: U1.63 (SAI3_SDO/DSM_AUD_LP_M1/ETH_RMII0_MDIO/G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); also elsewhere on the board
GND: C1.2, C2.2, C3.2, C4.2, J2.1, J15.1, U1.5 (GND5), U1.10 (GND10), U1.12 (GND12), U1.15 (GND15), U1.17 (GND17), U1.23 (GND23), U1.32 (GND32), U1.35 (GND35), U1.44 (GND44), U1.48 (GND48), U1.61 (GND61), U1.67 (GND67), U1.75 (GND75), U1.82 (GND82), U1.87 (GND87), U1.90 (GND90), U1.97 (GND97), U1.100 (GND100), U1.105 (GND105), U1.110 (GND110), U1.115 (GND115), U1.124 (GND124); also elsewhere on the board
HP_CONTROL: R95.1, U1.84 (SARADC_IN2/GPIO4_B2_z), U1.88 (ACODEC_ADC_INP); also elsewhere on the board
HP_DETECT: U1.28 (RM_IO11/SAI1_SDI/GPIO0_B3_d); also elsewhere on the board
HP_DETECT1: U1.29 (RM_IO10/SPI1_MISO/SAI1_LRCK/GPIO0_B2_d); also elsewhere on the board
HP_INT: U1.30 (RM_IO9/SPI1_MOSI/SAI1_SCLK/GPIO0_B1_d); also elsewhere on the board
KEY_DOWN: U1.117 (RM_IO24/UART5_CTSN_M1/FLEXBUS1_CSN_M0/F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); also elsewhere on the board
KEY_LEFT: U1.119 (RM_IO26/SAI2_LRCK_M1/FLEXBUS1_CSN_M1/FL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); also elsewhere on the board
KEY_POWER: U1.106 (FLEXBUS1_D0/DSMC_CLKP/VO_LCDC_DEN/GPIO1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); also elsewhere on the board
KEY_RIGHT: U1.118 (RM_IO25/SAI2_SCLK_M1/FLEXBUS0_CSN_M1/FL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); also elsewhere on the board
LCD_CLKN: U1.98 (MIPI_DPHY_DSI_TX_CLKN/GPO4_A4_z); also elsewhere on the board
LCD_CLKP: U1.99 (MIPI_DPHY_DSI_TX_CLKP/GPO4_A5_z); also elsewhere on the board
LCD_D0N: U1.103 (MIPI_DPHY_DSI_TX_D0N/GPO4_A0_z); also elsewhere on the board
LCD_D0P: U1.104 (MIPI_DPHY_DSI_TX_D0P/GPO4_A1_z); also elsewhere on the board
LCD_D1N: U1.101 (MIPI_DPHY_DSI_TX_D1N/GPO4_A2_z); also elsewhere on the board
LCD_D1P: U1.102 (MIPI_DPHY_DSI_TX_D1P/GPO4_A3_z); also elsewhere on the board
LCD_LED: U1.41 (RM_IO2/SAI0_MCLK/GPIO0_A2_u); also elsewhere on the board
LCD_RESET: U1.108 (FLEXBUS1_D2/DSMC_DQS0/VO_LCDC_HSYNC/GPI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); also elsewhere on the board
LED_STATE: U1.31 (RM_IO8/SPI1_CLK/SAI1_MCLK/GPIO0_B0_d); also elsewhere on the board
MIC_GND: U1.89 (ACODEC_ADC_INN); also elsewhere on the board
unnamed: D1.1 (K), J2.3
unnamed: J1.1, R3.2
unnamed: J2.2, R4.2
unnamed: J3.1, R6.2
unnamed: R2.2, U1.92 (USB20_OTG0_ID)
unnamed: C1.1, R1.1, U1.68 (VCCIO4_IN)
OUT_EN: U1.27 (RM_IO12/SAI1_SDO0/GPIO0_B4_d); also elsewhere on the board
POWER_ON: U1.107 (DSMC_SLV_INT/DSMC_INT0/FLEXBUS1_D1/DSMC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); also elsewhere on the board
RECOVER: U1.85 (SARADC_IN1_RECOVERY/GPIO4_B1_z); also elsewhere on the board
RESET: R3.1, U1.16 (NPOR_L)
SD_CLK: U1.60 (NC/SDMMC_CLK/GPIO3_A0_d); also elsewhere on the board
SD_CMD: U1.59 (NC/SDMMC_CMD/GPIO3_A1_d); also elsewhere on the board
SD_D0: U1.57 (NC/SDMMC_D0/GPIO3_A2_d); also elsewhere on the board
SD_D1: U1.56 (NC/TEST_CLK_OUT/SDMMC_D1/GPIO3_A3_d); also elsewhere on the board
SD_D2: U1.55 (NC/JTAG_TCK_M0/SDMMC_D2/GPIO3_A4_d); also elsewhere on the board
SD_D3: U1.58 (NC/JTAG_TMS_M0/SDMMC_D3/GPIO3_A5_d); also elsewhere on the board
SD_DET: U1.54 (ETH_RMII1_RXD0/SAI2_SDI_M0/GPIO3_A6_d); also elsewhere on the board
TP_INT: U1.53 (ETH_RMII1_RXD1/SAI2_SCLK_M0/GPIO3_A7_d); also elsewhere on the board
TP_RESET: U1.52 (ETH_RMII1_TXD0/SAI2_LRCK_M0/GPIO3_B1_d); also elsewhere on the board
TP_SCL: U1.42 (RM_IO1/SAI0_SCLK/GPIO0_A1_d); also elsewhere on the board
TP_SDA: U1.43 (RM_IO0/SAI0_LRCK/GPIO0_A0_u); also elsewhere on the board
UART0_RX: D1.2 (A), R5.2, U1.13 (RM_IO23/JTAG_TMS_M1/UART0_RX_Debug/GPIO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)
UART0_TX: R4.1, U1.14 (RM_IO22/JTAG_TCK_M1/UART0_TX_Debug/GPIO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)
USB0_DM: U1.93 (USB20_OTG0_DM); also elsewhere on the board
USB0_DP: U1.94 (USB20_OTG0_DP); also elsewhere on the board
USB1_DM: U1.95 (USB20_OTG1_DM); also elsewhere on the board
USB1_DP: U1.96 (USB20_OTG1_DP); also elsewhere on the board
USB_DET: U1.91 (USB20_OTG0_VBUSDET); also elsewhere on the board
VCC_1V8_OUT: R2.1, R95.2, U1.65 (VCC_1V8_OUT); also elsewhere on the board
VCC_3V3_OUT: R1.2, R5.1, U1.66 (VCC_3V3_OUT)
WIFI_POWER: U1.109 (FLEXBUS1_D3/DSMC_D0/VO_LCDC_CLK_/GPIO1_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); also elsewhere on the board

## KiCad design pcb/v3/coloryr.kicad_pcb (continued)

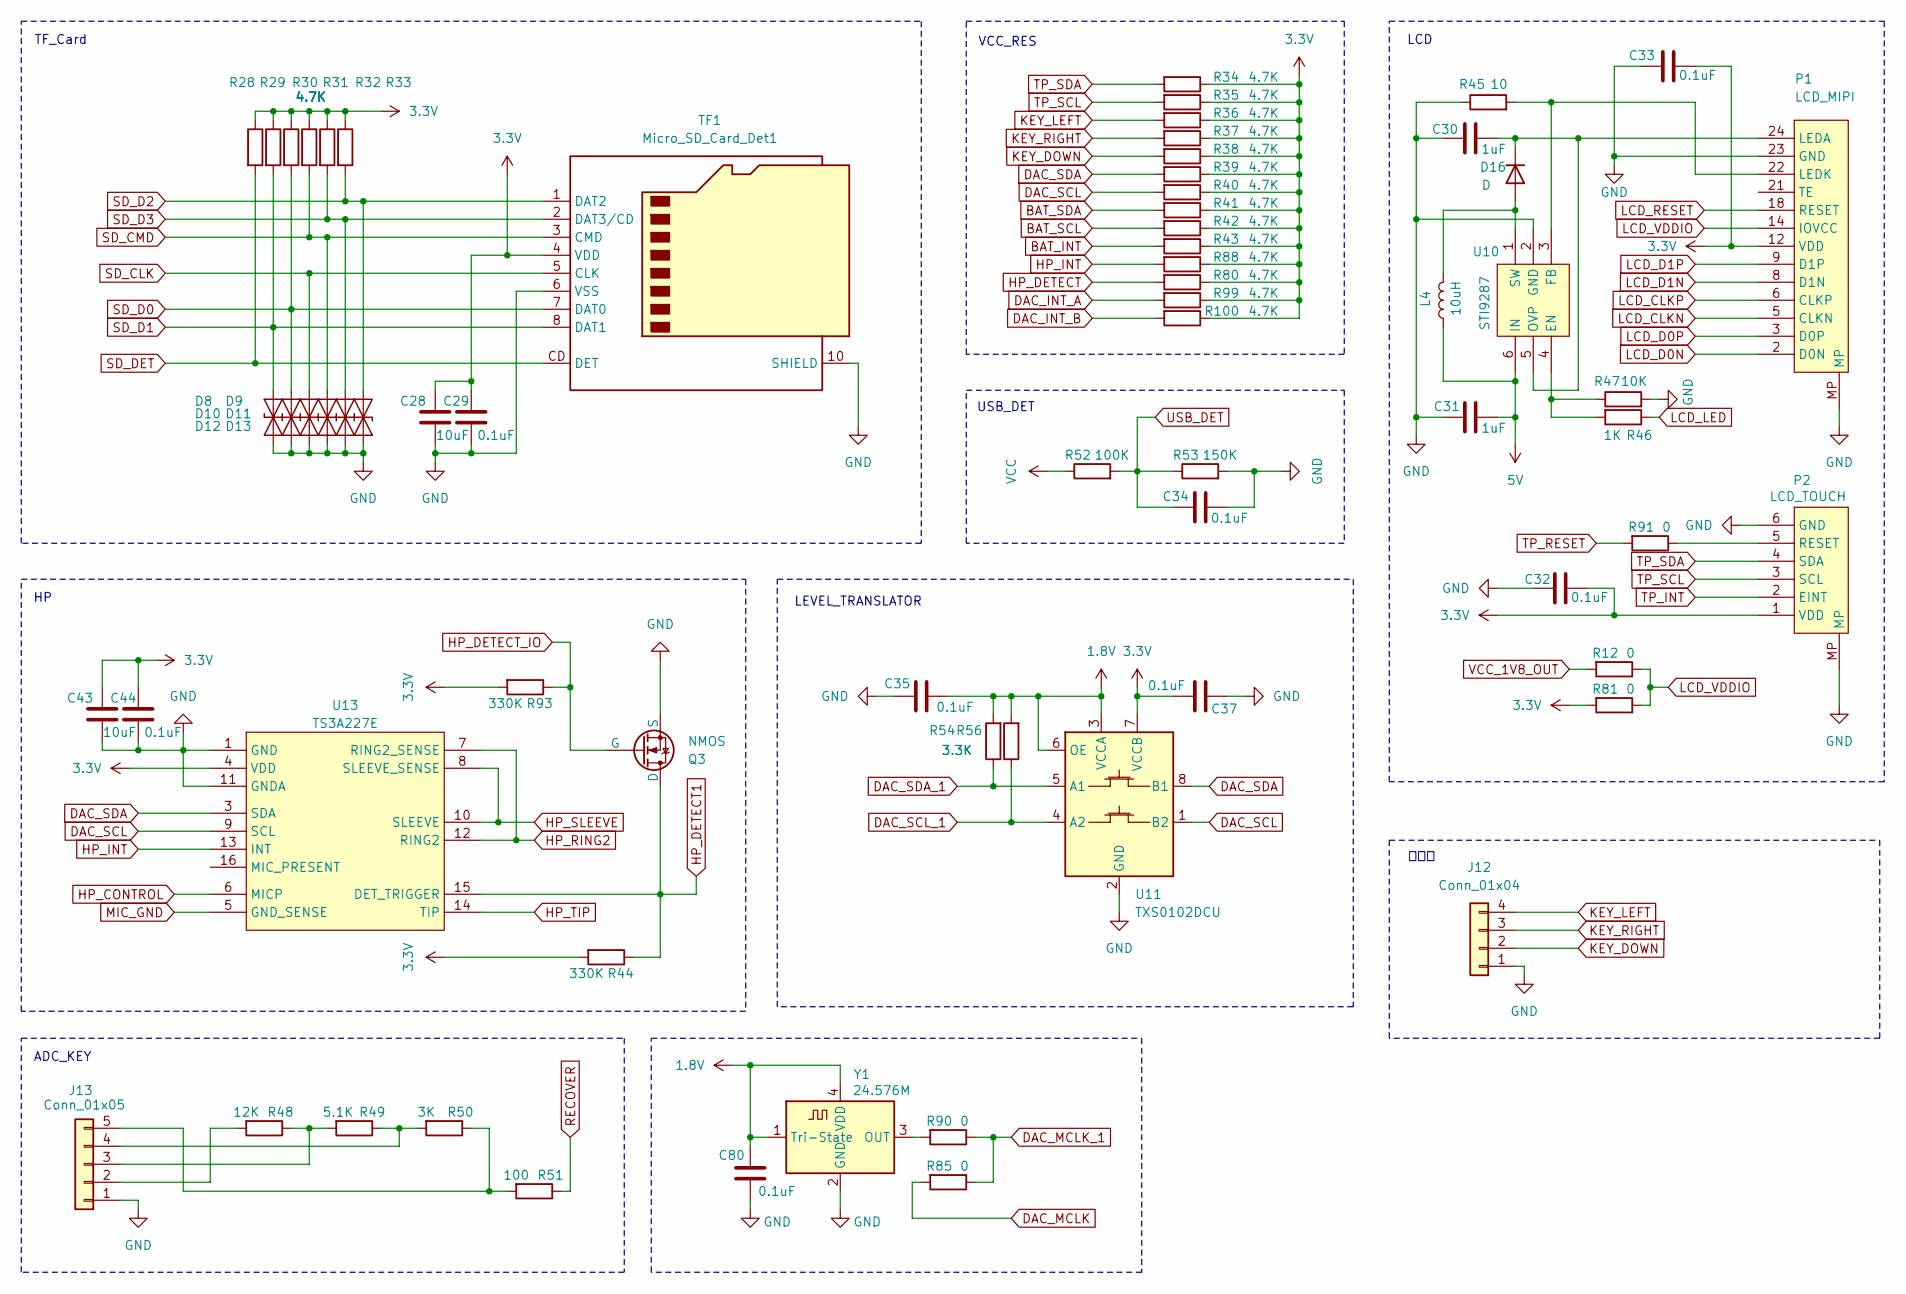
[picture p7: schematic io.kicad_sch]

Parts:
C28, C43: 10uF; C_0402_1005Metric_Pad0.74x0.62mm_HandSolder
C29, C32, C33, C34, C35, C37, C44, C80: 0.1uF; C_0402_1005Metric_Pad0.74x0.62mm_HandSolder
C30, C31: 1uF; C_0402_1005Metric_Pad0.74x0.62mm_HandSolder
D8, D9, D10, D11, D12, D13: ESD9B5.0ST5G; D_SOD-523
D16: D; D_SOD-323_HandSoldering
J12: Conn_01x04; PinHeader_1x04_P1.27mm_Vertical
J13: Conn_01x05; PinHeader_1x05_P1.27mm_Vertical
L4: 10uH; L_TDK_NLV25_2.5x2.0mm
P1: LCD_MIPI; Hirose_FH12-24S-0.5SH_1x24-1MP_P0.50mm_Horizontal
P2: LCD_TOUCH; Hirose_FH12-6S-0.5SH_1x06-1MP_P0.50mm_Horizontal
Q3: NMOS; SOT-23
R12, R81, R85, R90, R91: 0; R_0402_1005Metric_Pad0.72x0.64mm_HandSolder
R28, R29, R30, R31, R32, R33: 4.7K; R_0402_1005Metric_Pad0.72x0.64mm_HandSolder
R34, R35, R36, R37, R38, R39, R40, R41, R42, R43, R80, R88, R99, R100: 4.7K; C_0402_1005Metric_Pad0.74x0.62mm_HandSolder
R44, R93: 330K; R_0402_1005Metric_Pad0.72x0.64mm_HandSolder
R45: 10; R_0805_2012Metric
R46: 1K; R_0402_1005Metric_Pad0.72x0.64mm_HandSolder
R47: 10K; R_0402_1005Metric_Pad0.72x0.64mm_HandSolder
R48: 12K; R_0402_1005Metric_Pad0.72x0.64mm_HandSolder
R49: 5.1K; R_0402_1005Metric_Pad0.72x0.64mm_HandSolder
R50: 3K; R_0402_1005Metric_Pad0.72x0.64mm_HandSolder
R51: 100; R_0402_1005Metric_Pad0.72x0.64mm_HandSolder
R52: 100K; R_0402_1005Metric_Pad0.72x0.64mm_HandSolder
R53: 150K; R_0402_1005Metric_Pad0.72x0.64mm_HandSolder
R54, R56: 3.3K; C_0402_1005Metric_Pad0.74x0.62mm_HandSolder
TF1: Micro_SD_Card_Det1; TF-SMD_TF-PUSH
U10: STI9287; SOT-23-6_Handsoldering
U11: TXS0102DCU; VSSOP-8_2.3x2mm_P0.5mm
U13: TS3A227E; Texas_RVA_VQFN-16-1EP_3.5x3.5mm_P0.5mm_EP2.14x2.14mm
Y1: 24.576M; Oscillator_SMD_ECS_2520MV-xxx-xx-4Pin_2.5x2.0mm

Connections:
1.8V: C35.1, C80.1, R54.2, R56.2, U11.3 (VCCA), U11.6 (OE), Y1.1 (Tri-State), Y1.4 (VDD); also elsewhere on the board
3.3V: C28.1, C29.1, C32.2, C33.2, C37.1, C43.1, C44.1, P1.11 (VDD), P1.12 (VDD), P2.1 (VDD), R28.1, R29.1, R30.1, R31.1, R32.1, R33.1, R34.1, R35.1, R36.1, R37.1, R38.1, R39.1, R40.1, R41.1, R42.1, R43.1, R44.2, R80.1, R81.2, R88.1, R93.2, R99.1, R100.1, TF1.4 (VDD), U11.7 (VCCB), U13.4 (VDD); also elsewhere on the board
5V: C31.2, L4.1, U10.6 (IN); also elsewhere on the board
BAT_INT: R43.2; also elsewhere on the board
BAT_SCL: R42.2; also elsewhere on the board
BAT_SDA: R41.2; also elsewhere on the board
DAC_INT_A: R99.2; also elsewhere on the board
DAC_INT_B: R100.2; also elsewhere on the board
DAC_MCLK: R85.2; also elsewhere on the board
DAC_MCLK_1: R85.1, R90.1; also elsewhere on the board
DAC_SCL: R40.2, U11.1 (B2), U13.9 (SCL); also elsewhere on the board
DAC_SCL_1: R56.1, U11.4 (A2); also elsewhere on the board
DAC_SDA: R39.2, U11.8 (B1), U13.3 (SDA); also elsewhere on the board
DAC_SDA_1: R54.1, U11.5 (A1); also elsewhere on the board
GND: C28.2, C29.2, C30.2, C31.1, C32.1, C33.1, C34.2, C35.2, C37.2, C43.2, C44.2, C80.2, D8.1 (A1), D9.1 (A1), D10.1 (A1), D11.1 (A1), D12.1 (A1), D13.1 (A1), J12.1, J13.1, P1.1 (GND), P1.4 (GND), P1.7 (GND), P1.10 (GND), P1.13 (GND), P1.15 (GND), P1.17 (GND), P1.19 (GND), P1.23 (GND), P1.MP, P2.6 (GND), P2.MP, Q3.3 (S), R45.1, R47.2, R53.2, TF1.6 (VSS), TF1.10 (SHIELD), TF1.11 (SHIELD), TF1.12 (SHIELD), TF1.13 (SHIELD), U10.2 (GND), U11.2 (GND), U13.1 (GND), U13.2 (GND), U13.11 (GNDA), U13.17 (GND), Y1.2 (GND); also elsewhere on the board
HP_CONTROL: U13.6 (MICP); also elsewhere on the board
HP_DETECT: R80.2; also elsewhere on the board
HP_DETECT1: Q3.1 (D), R44.1, U13.15 (DET_TRIGGER); also elsewhere on the board
HP_DETECT_IO: Q3.2 (G), R93.1; also elsewhere on the board
HP_INT: R88.2, U13.13 (INT); also elsewhere on the board
HP_RING2: U13.7 (RING2_SENSE), U13.12 (RING2); also elsewhere on the board
HP_SLEEVE: U13.8 (SLEEVE_SENSE), U13.10 (SLEEVE); also elsewhere on the board
HP_TIP: U13.14 (TIP); also elsewhere on the board
KEY_DOWN: J12.2, R38.2; also elsewhere on the board
KEY_LEFT: J12.4, R36.2; also elsewhere on the board
KEY_RIGHT: J12.3, R37.2; also elsewhere on the board
LCD_CLKN: P1.5 (CLKN); also elsewhere on the board
LCD_CLKP: P1.6 (CLKP); also elsewhere on the board
LCD_D0N: P1.2 (D0N); also elsewhere on the board
LCD_D0P: P1.3 (D0P); also elsewhere on the board
LCD_D1N: P1.8 (D1N); also elsewhere on the board
LCD_D1P: P1.9 (D1P); also elsewhere on the board
LCD_LED: R46.1; also elsewhere on the board
LCD_RESET: P1.18 (RESET); also elsewhere on the board
LCD_VDDIO: P1.14 (IOVCC), R12.1, R81.1
MIC_GND: U13.5 (GND_SENSE); also elsewhere on the board
unnamed: D16.2 (A), L4.2, U10.1 (SW)
unnamed: C30.1, D16.1 (K), P1.24 (LEDA), U10.5 (OVP)
unnamed: J13.2, R48.2
unnamed: J13.3, R48.1, R49.2
unnamed: J13.4, R49.1, R50.2
unnamed: J13.5, R50.1, R51.2
unnamed: P1.22 (LEDK), R45.2, U10.3 (FB)
unnamed: P2.5 (RESET), R91.1
unnamed: R46.2, R47.1, U10.4 (EN)
unnamed: R90.2, Y1.3 (OUT)
RECOVER: R51.1; also elsewhere on the board
SD_CLK: D10.2 (A2), TF1.5 (CLK); also elsewhere on the board
SD_CMD: D11.2 (A2), R31.2, TF1.3 (CMD); also elsewhere on the board
SD_D0: D9.2 (A2), R30.2, TF1.7 (DAT0); also elsewhere on the board
SD_D1: D8.2 (A2), R29.2, TF1.8 (DAT1); also elsewhere on the board
SD_D2: D13.2 (A2), R33.2, TF1.1 (DAT2); also elsewhere on the board
SD_D3: D12.2 (A2), R32.2, TF1.2 (DAT3/CD); also elsewhere on the board
SD_DET: R28.2, TF1.CD (DET); also elsewhere on the board
TP_INT: P2.2 (EINT); also elsewhere on the board
TP_RESET: R91.2; also elsewhere on the board
TP_SCL: P2.3 (SCL), R35.2; also elsewhere on the board
TP_SDA: P2.4 (SDA), R34.2; also elsewhere on the board
USB_DET: C34.1, R52.2, R53.1; also elsewhere on the board
VCC: R52.1; also elsewhere on the board
VCC_1V8_OUT: R12.2; also elsewhere on the board

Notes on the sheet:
ADC_KEY
编码轮
VCC_RES
USB_DET
LCD
LEVEL_TRANSLATOR
TF_Card

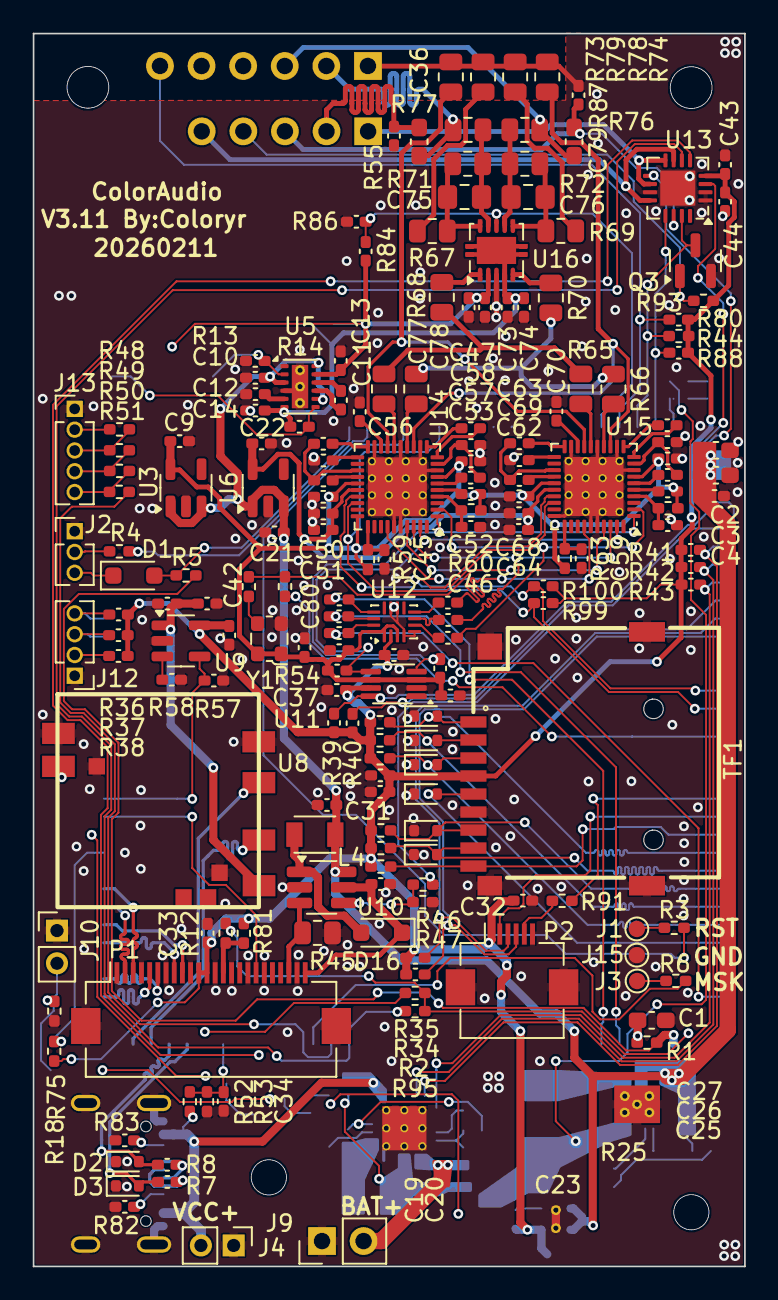
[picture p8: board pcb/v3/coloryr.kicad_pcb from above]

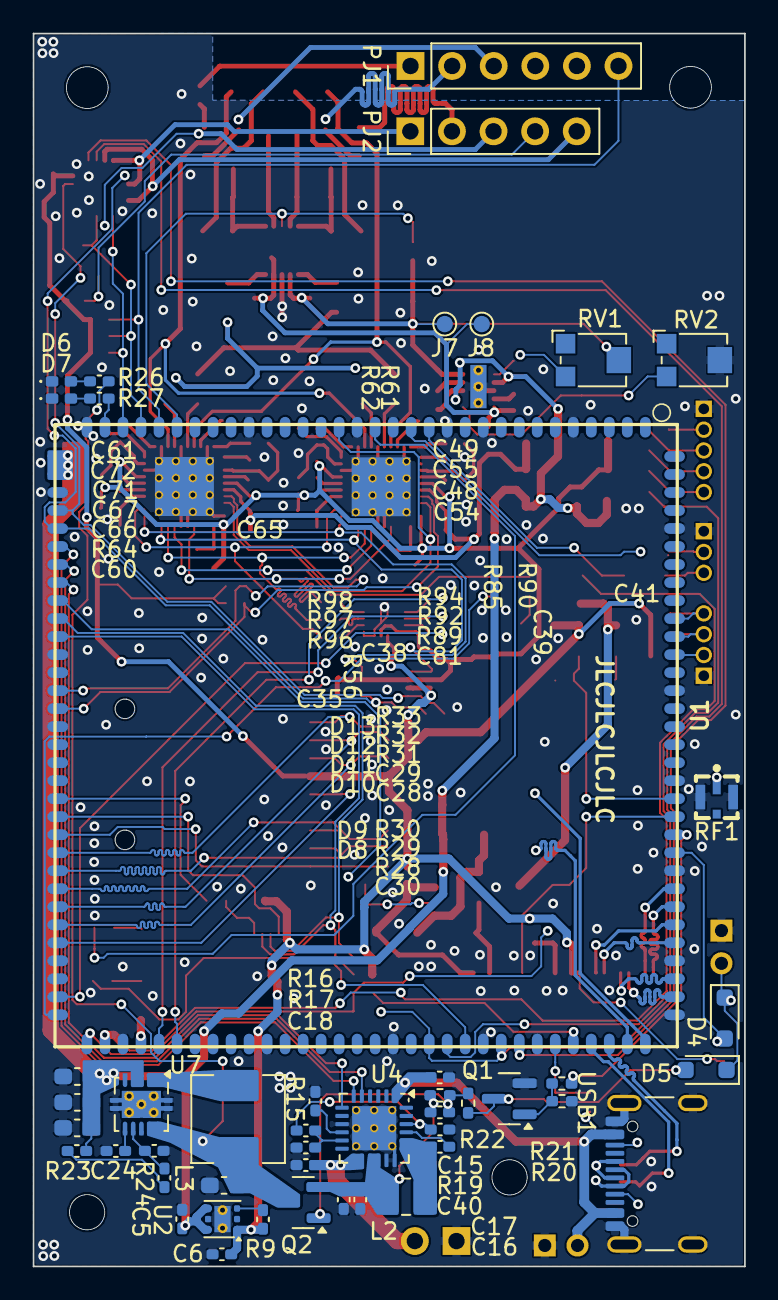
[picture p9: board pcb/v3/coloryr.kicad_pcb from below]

Board: 2 copper layers, 43.4 x 75.3 mm, 234 parts (47 on the bottom side), 171 nets.

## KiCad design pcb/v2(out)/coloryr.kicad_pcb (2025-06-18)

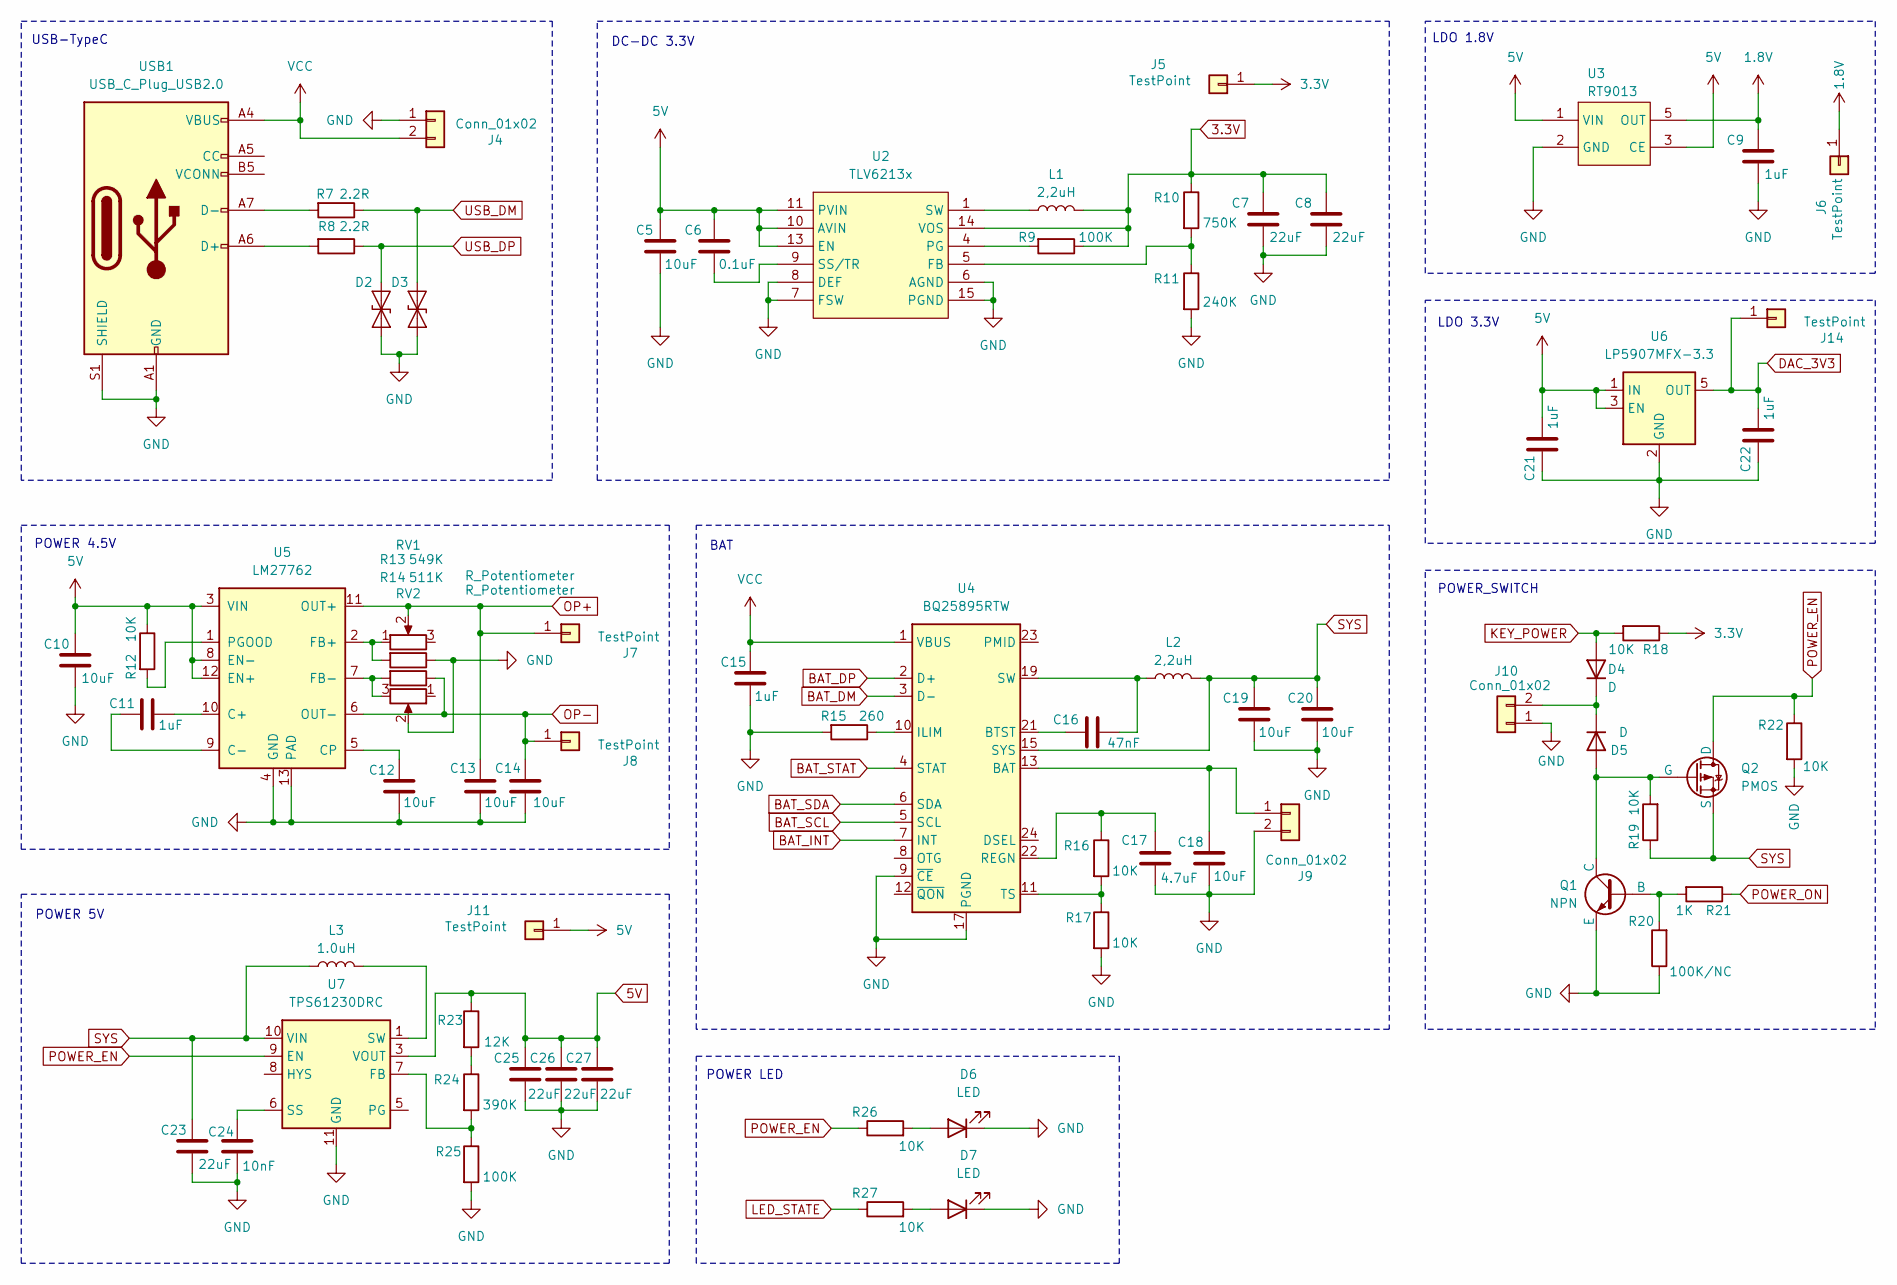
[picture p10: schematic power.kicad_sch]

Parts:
C5, C10, C12, C13, C14, C18, C19, C20: 10uF; C_0402_1005Metric_Pad0.74x0.62mm_HandSolder
C6: 0.1uF; C_0402_1005Metric_Pad0.74x0.62mm_HandSolder
C7, C8, C25, C26, C27: 22uF; C_0603_1608Metric_Pad1.08x0.95mm_HandSolder
C9, C11, C15, C21, C22: 1uF; C_0402_1005Metric_Pad0.74x0.62mm_HandSolder
C16: 47nF; C_0402_1005Metric_Pad0.74x0.62mm_HandSolder
C17: 4.7uF; C_0402_1005Metric_Pad0.74x0.62mm_HandSolder
C23: 22uF; C_0402_1005Metric_Pad0.74x0.62mm_HandSolder
C24: 10nF; C_0402_1005Metric_Pad0.74x0.62mm_HandSolder
D2, D3: ESD9B5.0ST5G; D_SOD-523
D4, D5: D; D_SOD-323_HandSoldering
D6, D7: LED; D_0402_1005Metric_Pad0.77x0.64mm_HandSolder
J4, J9: Conn_01x02; PinHeader_1x02_P2.54mm_Vertical
J5, J6, J7, J8, J11, J14: TestPoint; TestPoint_Pad_D2.0mm
J10: Conn_01x02; PinHeader_1x02_P2.00mm_Vertical
L1, L2: 2,2uH; L_1008_2520Metric_Pad1.43x2.20mm_HandSolder
L3: 1.0uH; L_Changjiang_FXL0530
Q1: NPN; SOT-23
Q2: PMOS; SOT-23
R7, R8: 2.2R; C_0402_1005Metric_Pad0.74x0.62mm_HandSolder
R9, R25: 100K; C_0402_1005Metric_Pad0.74x0.62mm_HandSolder
R10: 750K; C_0402_1005Metric_Pad0.74x0.62mm_HandSolder
R11: 240K; C_0402_1005Metric_Pad0.74x0.62mm_HandSolder
R12, R16, R17, R26, R27: 10K; C_0402_1005Metric_Pad0.74x0.62mm_HandSolder
R13: 549K; C_0402_1005Metric_Pad0.74x0.62mm_HandSolder
R14: 511K; C_0402_1005Metric_Pad0.74x0.62mm_HandSolder
R15: 260; C_0402_1005Metric_Pad0.74x0.62mm_HandSolder
R18, R19, R22: 10K; R_0402_1005Metric_Pad0.72x0.64mm_HandSolder
R20: 100K/NC; R_0402_1005Metric_Pad0.72x0.64mm_HandSolder
R21: 1K; R_0402_1005Metric_Pad0.72x0.64mm_HandSolder
R23: 12K; C_0402_1005Metric_Pad0.74x0.62mm_HandSolder
R24: 390K; C_0402_1005Metric_Pad0.74x0.62mm_HandSolder
RV1, RV2: R_Potentiometer; Potentiometer_Bourns_3296W_Vertical
U2: TLV6213x; VQFN-16-1EP_3x3mm_P0.5mm_EP1.68x1.68mm_ThermalVias
U3: SOT-23-5_HandSoldering
U4: BQ25895RTW; Texas_RTW_WQFN-24-1EP_4x4mm_P0.5mm_EP2.7x2.7mm_ThermalVias
U5: LM27762; WSON-12-1EP_3x2mm_P0.5mm_EP1x2.65_ThermalVias
U6: LP5907MFX-3.3; SOT-23-5
U7: TPS61230DRC; Texas_S-PVSON-N10_ThermalVias
USB1: USB_C_Plug_USB2.0; USB_C_Receptacle_GCT_USB4085

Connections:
1.8V: C9.1, J6.1, U3.5 (OUT); also elsewhere on the board
3.3V: C7.1, C8.1, J5.1, L1.2, R9.1, R10.1, R18.1, U2.14 (VOS); also elsewhere on the board
5V: C5.1, C6.1, C10.1, C21.1, C25.1, C26.1, C27.1, J11.1, R12.1, R23.1, U2.10 (AVIN), U2.11 (PVIN), U2.12 (PVIN), U2.13 (EN), U3.1 (VIN), U3.3 (CE), U5.3 (VIN), U5.8 (EN-), U5.12 (EN+), U6.1 (IN), U6.3 (EN), U7.3 (VOUT), U7.4 (VOUT); also elsewhere on the board
BAT_DM: U4.3 (D-); also elsewhere on the board
BAT_DP: U4.2 (D+); also elsewhere on the board
BAT_INT: U4.7 (INT); also elsewhere on the board
BAT_SCL: U4.5 (SCL); also elsewhere on the board
BAT_SDA: U4.6 (SDA); also elsewhere on the board
BAT_STAT: U4.4 (STAT); also elsewhere on the board
DAC_3V3: C22.1, J14.1, U6.5 (OUT); also elsewhere on the board
GND: C5.2, C7.2, C8.2, C9.2, C10.2, C12.1, C13.1, C14.1, C15.2, C17.1, C18.2, C19.2, C20.2, C21.2, C22.2, C23.2, C24.1, C25.2, C26.2, C27.2, D2.1 (A1), D3.1 (A1), D6.1 (K), D7.1 (K), J4.1, J9.2, J10.1, Q1.3 (E), R11.2, R13.1, R15.2, R17.2, R20.1, R22.2, R25.2, RV2.2, U2.6 (AGND), U2.7 (FSW), U2.8 (DEF), U2.15 (PGND), U2.16 (PGND), U2.17 (TAP), U3.2 (GND), U4.9 (~CE), U4.17 (PGND), U4.18 (PGND), U4.25 (PGND), U5.4 (GND), U5.13 (PAD), U6.2 (GND), U7.11 (GND), USB1.A1 (GND), USB1.A12 (GND), USB1.B1 (GND), USB1.B12 (GND), USB1.S1 (SHIELD); also elsewhere on the board
KEY_POWER: D4.2 (A), R18.2; also elsewhere on the board
LED_STATE: R27.1; also elsewhere on the board
unnamed: C16.2, L2.1, U4.19 (SW), U4.20 (SW)
unnamed: D4.1 (K), D5.1 (K), J10.2
unnamed: D5.2 (A), Q1.1 (C), Q2.2 (G), R19.2
unnamed: D6.2 (A), R26.2
unnamed: D7.2 (A), R27.2
unnamed: C18.1, J9.1, U4.13 (BAT), U4.14 (BAT)
unnamed: L1.1, U2.1 (SW), U2.2 (SW), U2.3 (SW)
unnamed: L3.2, U7.1 (SW), U7.2 (SW)
unnamed: Q1.2 (B), R20.2, R21.2
unnamed: R7.2, USB1.A7 (D-), USB1.B7 (D-)
unnamed: R8.2, USB1.A6 (D+), USB1.B6 (D+)
unnamed: R23.2, R24.1
unnamed: R10.2, R11.1, U2.5 (FB)
unnamed: R9.2, U2.4 (PG)
unnamed: C6.2, U2.9 (SS/TR)
unnamed: C16.1, U4.21 (BTST)
unnamed: R15.1, U4.10 (ILIM)
unnamed: C17.2, R16.1, U4.22 (REGN)
unnamed: R16.2, R17.1, U4.11 (TS)
unnamed: C11.2, U5.10 (C+)
unnamed: C11.1, U5.9 (C-)
unnamed: C12.2, U5.5 (CP)
unnamed: R13.2, RV1.1, U5.2 (FB+)
unnamed: R14.2, RV2.3, U5.7 (FB-)
unnamed: R12.2, U5.1 (PGOOD)
unnamed: R24.2, R25.1, U7.7 (FB)
unnamed: C24.2, U7.6 (SS)
OP+: C13.2, J7.1, RV1.2, U5.11 (OUT+); also elsewhere on the board
OP-: C14.2, J8.1, R14.1, U5.6 (OUT-); also elsewhere on the board
POWER_EN: Q2.1 (D), R22.1, R26.1, U7.9 (EN)
POWER_ON: R21.1; also elsewhere on the board
SYS: C19.1, C20.1, C23.1, L2.2, L3.1, Q2.3 (S), R19.1, U4.15 (SYS), U4.16 (SYS), U7.10 (VIN)
USB_DM: D3.2 (A2), R7.1; also elsewhere on the board
USB_DP: D2.2 (A2), R8.1; also elsewhere on the board
VCC: C15.1, J4.2, U4.1 (VBUS), USB1.A4 (VBUS), USB1.A9 (VBUS), USB1.B4 (VBUS), USB1.B9 (VBUS); also elsewhere on the board

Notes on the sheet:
POWER LED
BAT
LDO 3.3V
POWER_SWITCH
LDO 1.8V
DC-DC 3.3V
POWER 4.5V
USB-TypeC
POWER 5V

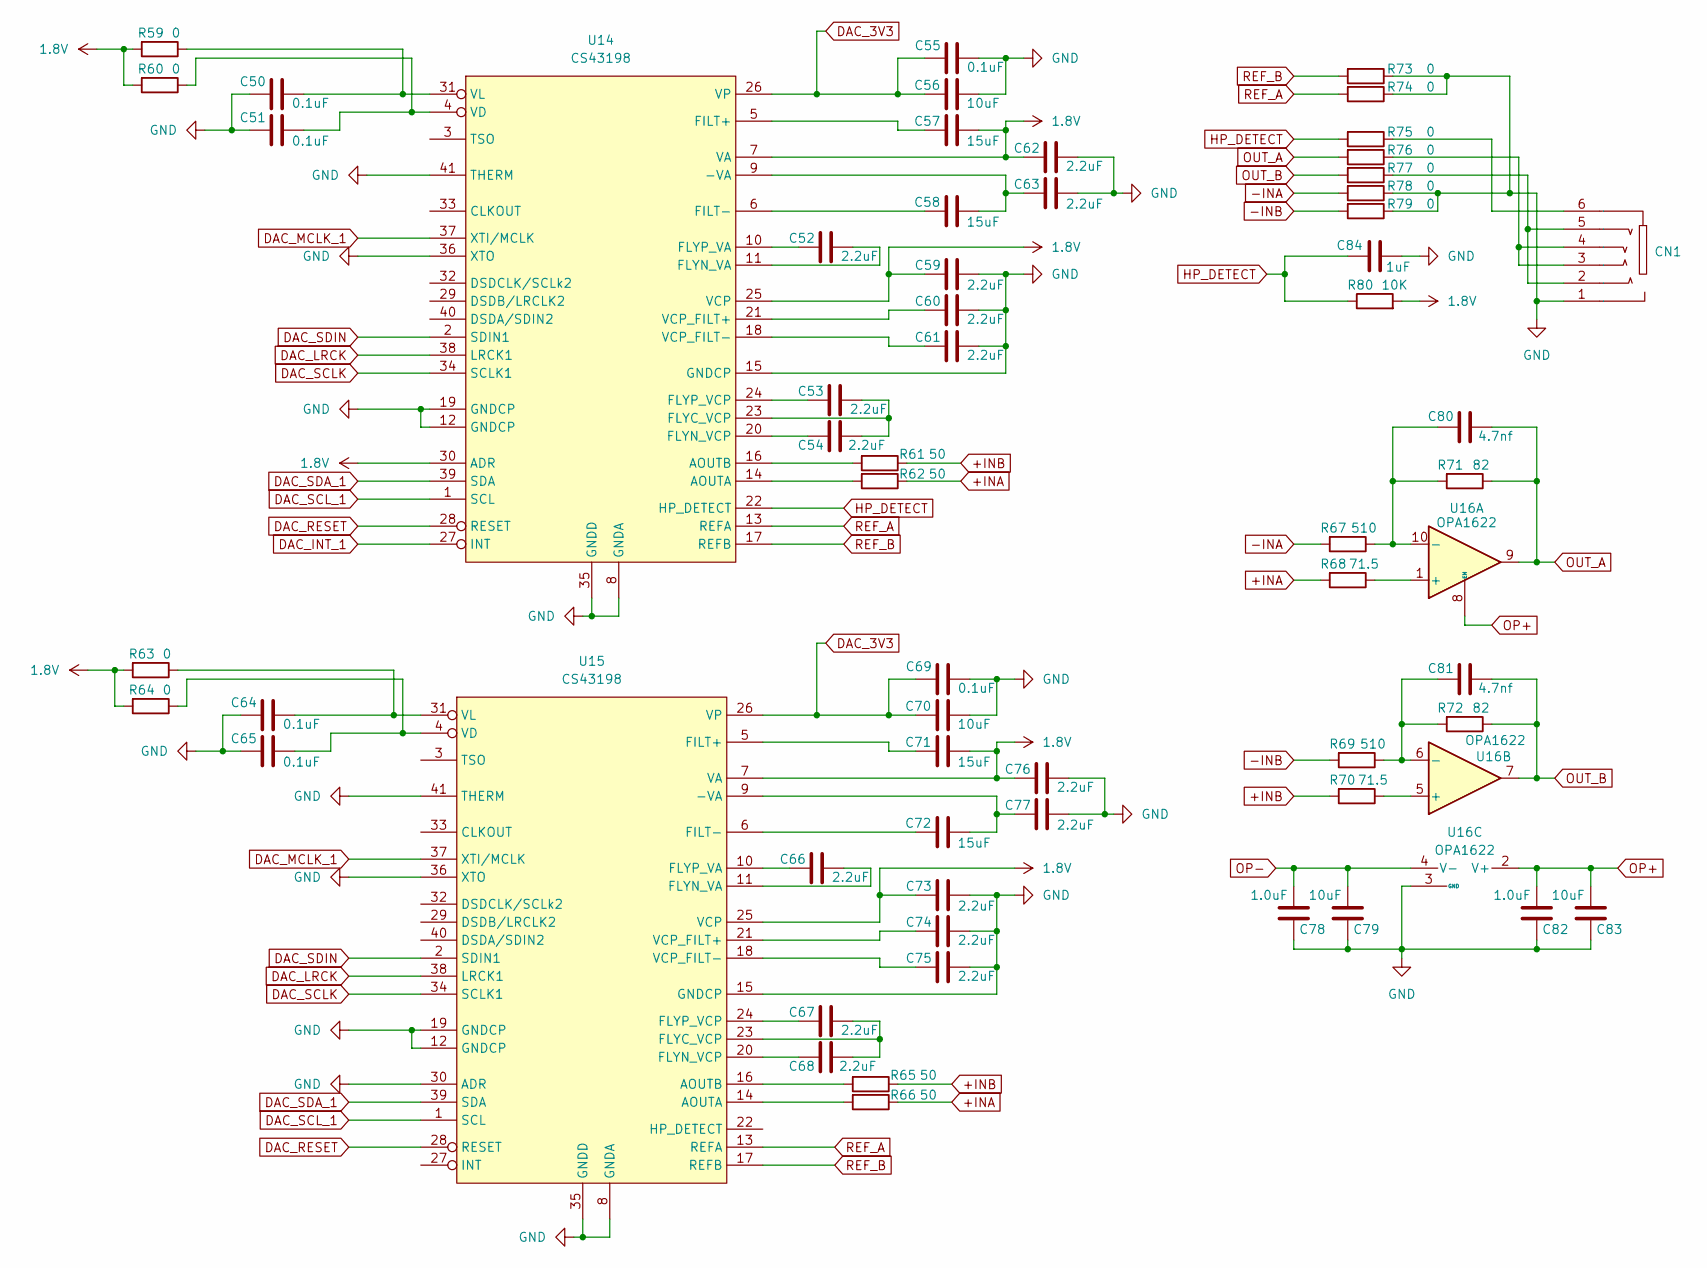
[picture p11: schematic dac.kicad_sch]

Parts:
C50, C51, C55, C64, C65, C69: 0.1uF; C_0402_1005Metric_Pad0.74x0.62mm_HandSolder
C52, C53, C54, C59, C60, C61, C62, C63, C66, C67, C68, C73, C74, C75, C76, C77: 2.2uF; C_0402_1005Metric_Pad0.74x0.62mm_HandSolder
C56, C70, C79, C83: 10uF; C_0402_1005Metric_Pad0.74x0.62mm_HandSolder
C57, C58, C71, C72: 15uF; C_0402_1005Metric_Pad0.74x0.62mm_HandSolder
C78, C82: 1.0uF; C_0402_1005Metric_Pad0.74x0.62mm_HandSolder
C80, C81: 4.7nf; C_0805_2012Metric_Pad1.18x1.45mm_HandSolder
C84: 1uF; C_0402_1005Metric_Pad0.74x0.62mm_HandSolder
CN1: AUDIO-TH_PJ-625G
R59, R60, R63, R64: 0; R_0402_1005Metric_Pad0.72x0.64mm_HandSolder
R61, R62, R65, R66: 50; R_0805_2012Metric_Pad1.20x1.40mm_HandSolder
R67, R69: 510; R_0805_2012Metric_Pad1.20x1.40mm_HandSolder
R68, R70: 71.5; R_0805_2012Metric_Pad1.20x1.40mm_HandSolder
R71, R72: 82; R_0805_2012Metric_Pad1.20x1.40mm_HandSolder
R73, R74, R75, R76, R77, R78, R79: 0; R_1206_3216Metric_Pad1.30x1.75mm_HandSolder
R80: 10K; R_0402_1005Metric_Pad0.72x0.64mm_HandSolder
U14, U15: CS43198; QFN-40-1EP_5x5mm_P0.4mm_EP3.6x3.6mm_ThermalVias
U16: OPA1622; Texas_S-PVSON-N10

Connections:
1.8V: C57.2, C59.2, C62.2, C71.2, C73.2, C76.2, R59.2, R60.2, R63.2, R64.2, R80.2, U14.7 (VA), U14.25 (VCP), U14.30 (ADR), U15.7 (VA), U15.25 (VCP); also elsewhere on the board
+INA: R62.1, R66.1, R68.2
+INB: R61.1, R65.1, R70.2
-INA: R67.2, R78.2
-INB: R69.2, R79.2
DAC_3V3: C55.2, C56.1, C69.2, C70.1, U14.26 (VP), U15.26 (VP); also elsewhere on the board
DAC_INT_1: U14.27 (INT); also elsewhere on the board
DAC_LRCK: U14.38 (LRCK1), U15.38 (LRCK1); also elsewhere on the board
DAC_MCLK_1: U14.37 (XTI/MCLK), U15.37 (XTI/MCLK); also elsewhere on the board
DAC_RESET: U14.28 (RESET), U15.28 (RESET); also elsewhere on the board
DAC_SCLK: U14.34 (SCLK1), U15.34 (SCLK1); also elsewhere on the board
DAC_SCL_1: U14.1 (SCL), U15.1 (SCL); also elsewhere on the board
DAC_SDA_1: U14.39 (SDA), U15.39 (SDA); also elsewhere on the board
DAC_SDIN: U14.2 (SDIN1), U15.2 (SDIN1); also elsewhere on the board
GND: C50.2, C51.2, C55.1, C56.2, C59.1, C60.1, C61.1, C62.1, C63.1, C64.2, C65.2, C69.1, C70.2, C73.1, C74.1, C75.1, C76.1, C77.1, C78.1, C79.1, C82.1, C83.1, C84.2, CN1.1, R73.1, R74.1, R78.1, R79.1, U14.8 (GNDA), U14.12 (GNDCP), U14.15 (GNDCP), U14.19 (GNDCP), U14.35 (GNDD), U14.36 (XTO), U14.41 (THERM), U15.8 (GNDA), U15.12 (GNDCP), U15.15 (GNDCP), U15.19 (GNDCP), U15.30 (ADR), U15.35 (GNDD), U15.36 (XTO), U15.41 (THERM), U16.3 (GND); also elsewhere on the board
HP_DETECT: C84.1, R75.2, R80.1, U14.22 (HP_DETECT)
unnamed: CN1.3, CN1.4 (3), R76.1
unnamed: CN1.2, CN1.5, R77.1
unnamed: CN1.6, R75.1
unnamed: C58.2, C63.2, U14.9 (-VA)
unnamed: R62.2, U14.14 (AOUTA)
unnamed: R61.2, U14.16 (AOUTB)
unnamed: C57.1, U14.5 (FILT+)
unnamed: C58.1, U14.6 (FILT-)
unnamed: C53.1, C54.1, U14.23 (FLYC_VCP)
unnamed: C52.1, U14.11 (FLYN_VA)
unnamed: C54.2, U14.20 (FLYN_VCP)
unnamed: C52.2, U14.10 (FLYP_VA)
unnamed: C53.2, U14.24 (FLYP_VCP)
unnamed: C60.2, U14.21 (VCP_FILT+)
unnamed: C61.2, U14.18 (VCP_FILT-)
unnamed: C51.1, R60.1, U14.4 (VD)
unnamed: C50.1, R59.1, U14.31 (VL)
unnamed: C72.2, C77.2, U15.9 (-VA)
unnamed: R66.2, U15.14 (AOUTA)
unnamed: R65.2, U15.16 (AOUTB)
unnamed: C71.1, U15.5 (FILT+)
unnamed: C72.1, U15.6 (FILT-)
unnamed: C67.1, C68.1, U15.23 (FLYC_VCP)
unnamed: C66.1, U15.11 (FLYN_VA)
unnamed: C68.2, U15.20 (FLYN_VCP)
unnamed: C66.2, U15.10 (FLYP_VA)
unnamed: C67.2, U15.24 (FLYP_VCP)
unnamed: C74.2, U15.21 (VCP_FILT+)
unnamed: C75.2, U15.18 (VCP_FILT-)
unnamed: C65.1, R64.1, U15.4 (VD)
unnamed: C64.1, R63.1, U15.31 (VL)
unnamed: R68.1, U16.1 (+)
unnamed: C80.2, R67.1, R71.2, U16.10 (-)
unnamed: R70.1, U16.5 (+)
unnamed: C81.2, R69.1, R72.2, U16.6 (-)
OP+: C82.2, C83.2, U16.2 (V+), U16.8 (EN); also elsewhere on the board
OP-: C78.2, C79.2, U16.4 (V-), U16.11 (V-); also elsewhere on the board
OUT_A: C80.1, R71.1, R76.2, U16.9
OUT_B: C81.1, R72.1, R77.2, U16.7
REF_A: R74.2, U14.13 (REFA), U15.13 (REFA)
REF_B: R73.2, U14.17 (REFB), U15.17 (REFB)

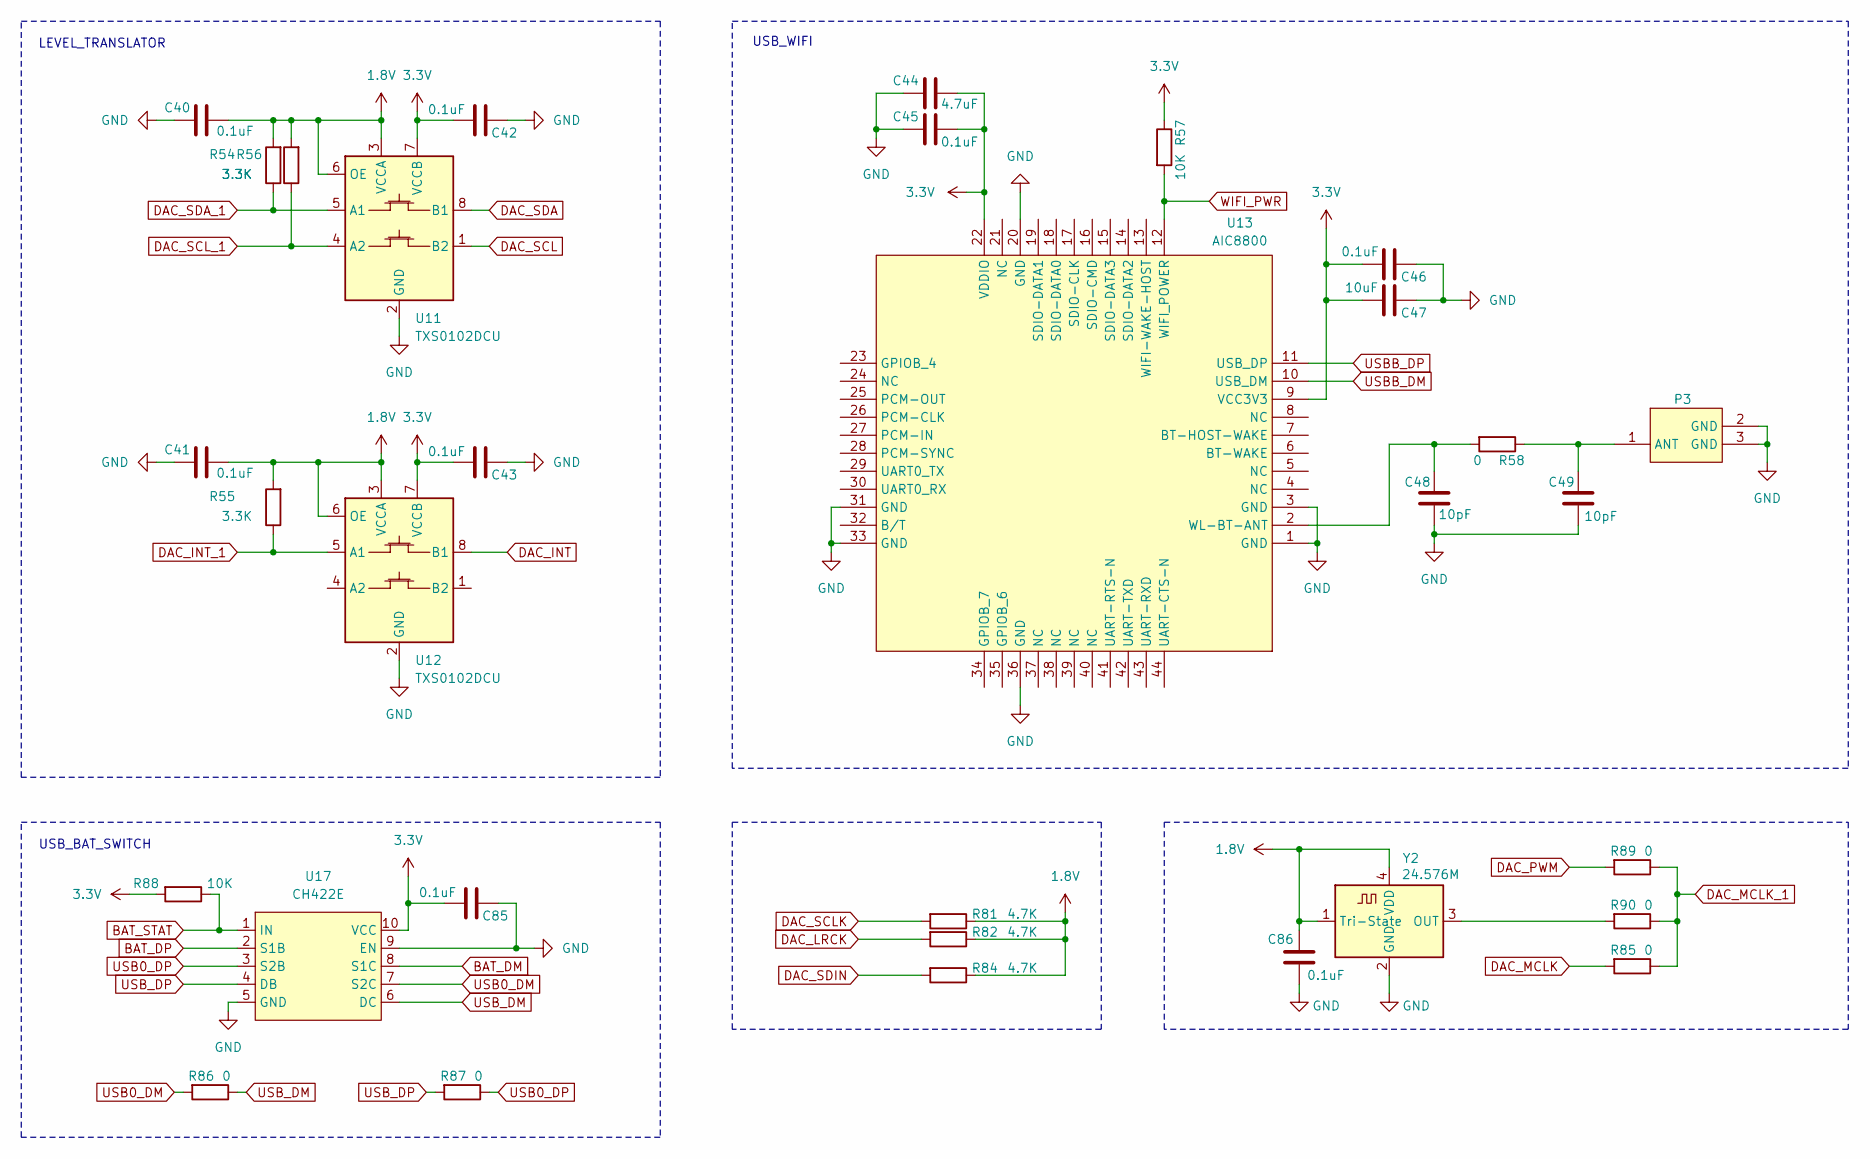
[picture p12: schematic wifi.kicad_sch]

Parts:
C40, C41, C42, C43, C45, C46, C85, C86: 0.1uF; C_0402_1005Metric_Pad0.74x0.62mm_HandSolder
C44: 4.7uF; C_0402_1005Metric_Pad0.74x0.62mm_HandSolder
C47: 10uF; C_0402_1005Metric_Pad0.74x0.62mm_HandSolder
C48, C49: 10pF; C_0402_1005Metric_Pad0.74x0.62mm_HandSolder
P3: IPEX-SMD_BWIPX-1-001E
R54, R55, R56: 3.3K; C_0402_1005Metric_Pad0.74x0.62mm_HandSolder
R57: 10K; R_0402_1005Metric_Pad0.72x0.64mm_HandSolder
R58, R85, R86, R87, R89, R90: 0; R_0402_1005Metric_Pad0.72x0.64mm_HandSolder
R81, R82, R84: 4.7K; C_0402_1005Metric_Pad0.74x0.62mm_HandSolder
R88: 10K; C_0402_1005Metric_Pad0.74x0.62mm_HandSolder
U11, U12: TXS0102DCU; VSSOP-8_2.3x2mm_P0.5mm
U13: AIC8800; AIC8800模组
U17: CH422E; MSOP-10_3x3mm_P0.5mm
Y2: 24.576M; Oscillator_SMD_ECS_2520MV-xxx-xx-4Pin_2.5x2.0mm

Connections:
1.8V: C40.1, C41.1, C86.1, R54.2, R55.2, R56.2, R81.1, R82.1, R84.1, U11.3 (VCCA), U11.6 (OE), U12.3 (VCCA), U12.6 (OE), Y2.1 (Tri-State), Y2.4 (VDD); also elsewhere on the board
3.3V: C42.1, C43.1, C44.2, C45.2, C46.2, C47.2, C85.1, R57.1, R88.2, U11.7 (VCCB), U12.7 (VCCB), U13.9 (VCC3V3), U13.22 (VDDIO), U17.10 (VCC); also elsewhere on the board
BAT_DM: U17.8 (S1C); also elsewhere on the board
BAT_DP: U17.2 (S1B); also elsewhere on the board
BAT_STAT: R88.1, U17.1 (IN); also elsewhere on the board
DAC_INT: U12.8 (B1); also elsewhere on the board
DAC_INT_1: R55.1, U12.5 (A1); also elsewhere on the board
DAC_LRCK: R82.2; also elsewhere on the board
DAC_MCLK: R85.2; also elsewhere on the board
DAC_MCLK_1: R85.1, R89.1, R90.1; also elsewhere on the board
DAC_PWM: R89.2; also elsewhere on the board
DAC_SCL: U11.1 (B2); also elsewhere on the board
DAC_SCLK: R81.2; also elsewhere on the board
DAC_SCL_1: R56.1, U11.4 (A2); also elsewhere on the board
DAC_SDA: U11.8 (B1); also elsewhere on the board
DAC_SDA_1: R54.1, U11.5 (A1); also elsewhere on the board
DAC_SDIN: R84.2; also elsewhere on the board
GND: C40.2, C41.2, C42.2, C43.2, C44.1, C45.1, C46.1, C47.1, C48.2, C49.2, C85.2, C86.2, P3.2 (GND), P3.3 (GND), U11.2 (GND), U12.2 (GND), U13.1 (GND), U13.3 (GND), U13.20 (GND), U13.31 (GND), U13.33 (GND), U13.36 (GND), U17.5 (GND), U17.9 (EN), Y2.2 (GND); also elsewhere on the board
unnamed: C49.1, P3.1 (ANT), R58.1
unnamed: C48.1, R58.2, U13.2 (WL-BT-ANT)
unnamed: R90.2, Y2.3 (OUT)
USB0_DM: R86.2, U17.7 (S2C); also elsewhere on the board
USB0_DP: R87.1, U17.3 (S2B); also elsewhere on the board
USBB_DM: U13.10 (USB_DM); also elsewhere on the board
USBB_DP: U13.11 (USB_DP); also elsewhere on the board
USB_DM: R86.1, U17.6 (DC); also elsewhere on the board
USB_DP: R87.2, U17.4 (DB); also elsewhere on the board
WIFI_PWR: R57.2, U13.12 (WIFI_POWER); also elsewhere on the board

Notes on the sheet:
LEVEL_TRANSLATOR
USB_BAT_SWITCH
USB_WIFI

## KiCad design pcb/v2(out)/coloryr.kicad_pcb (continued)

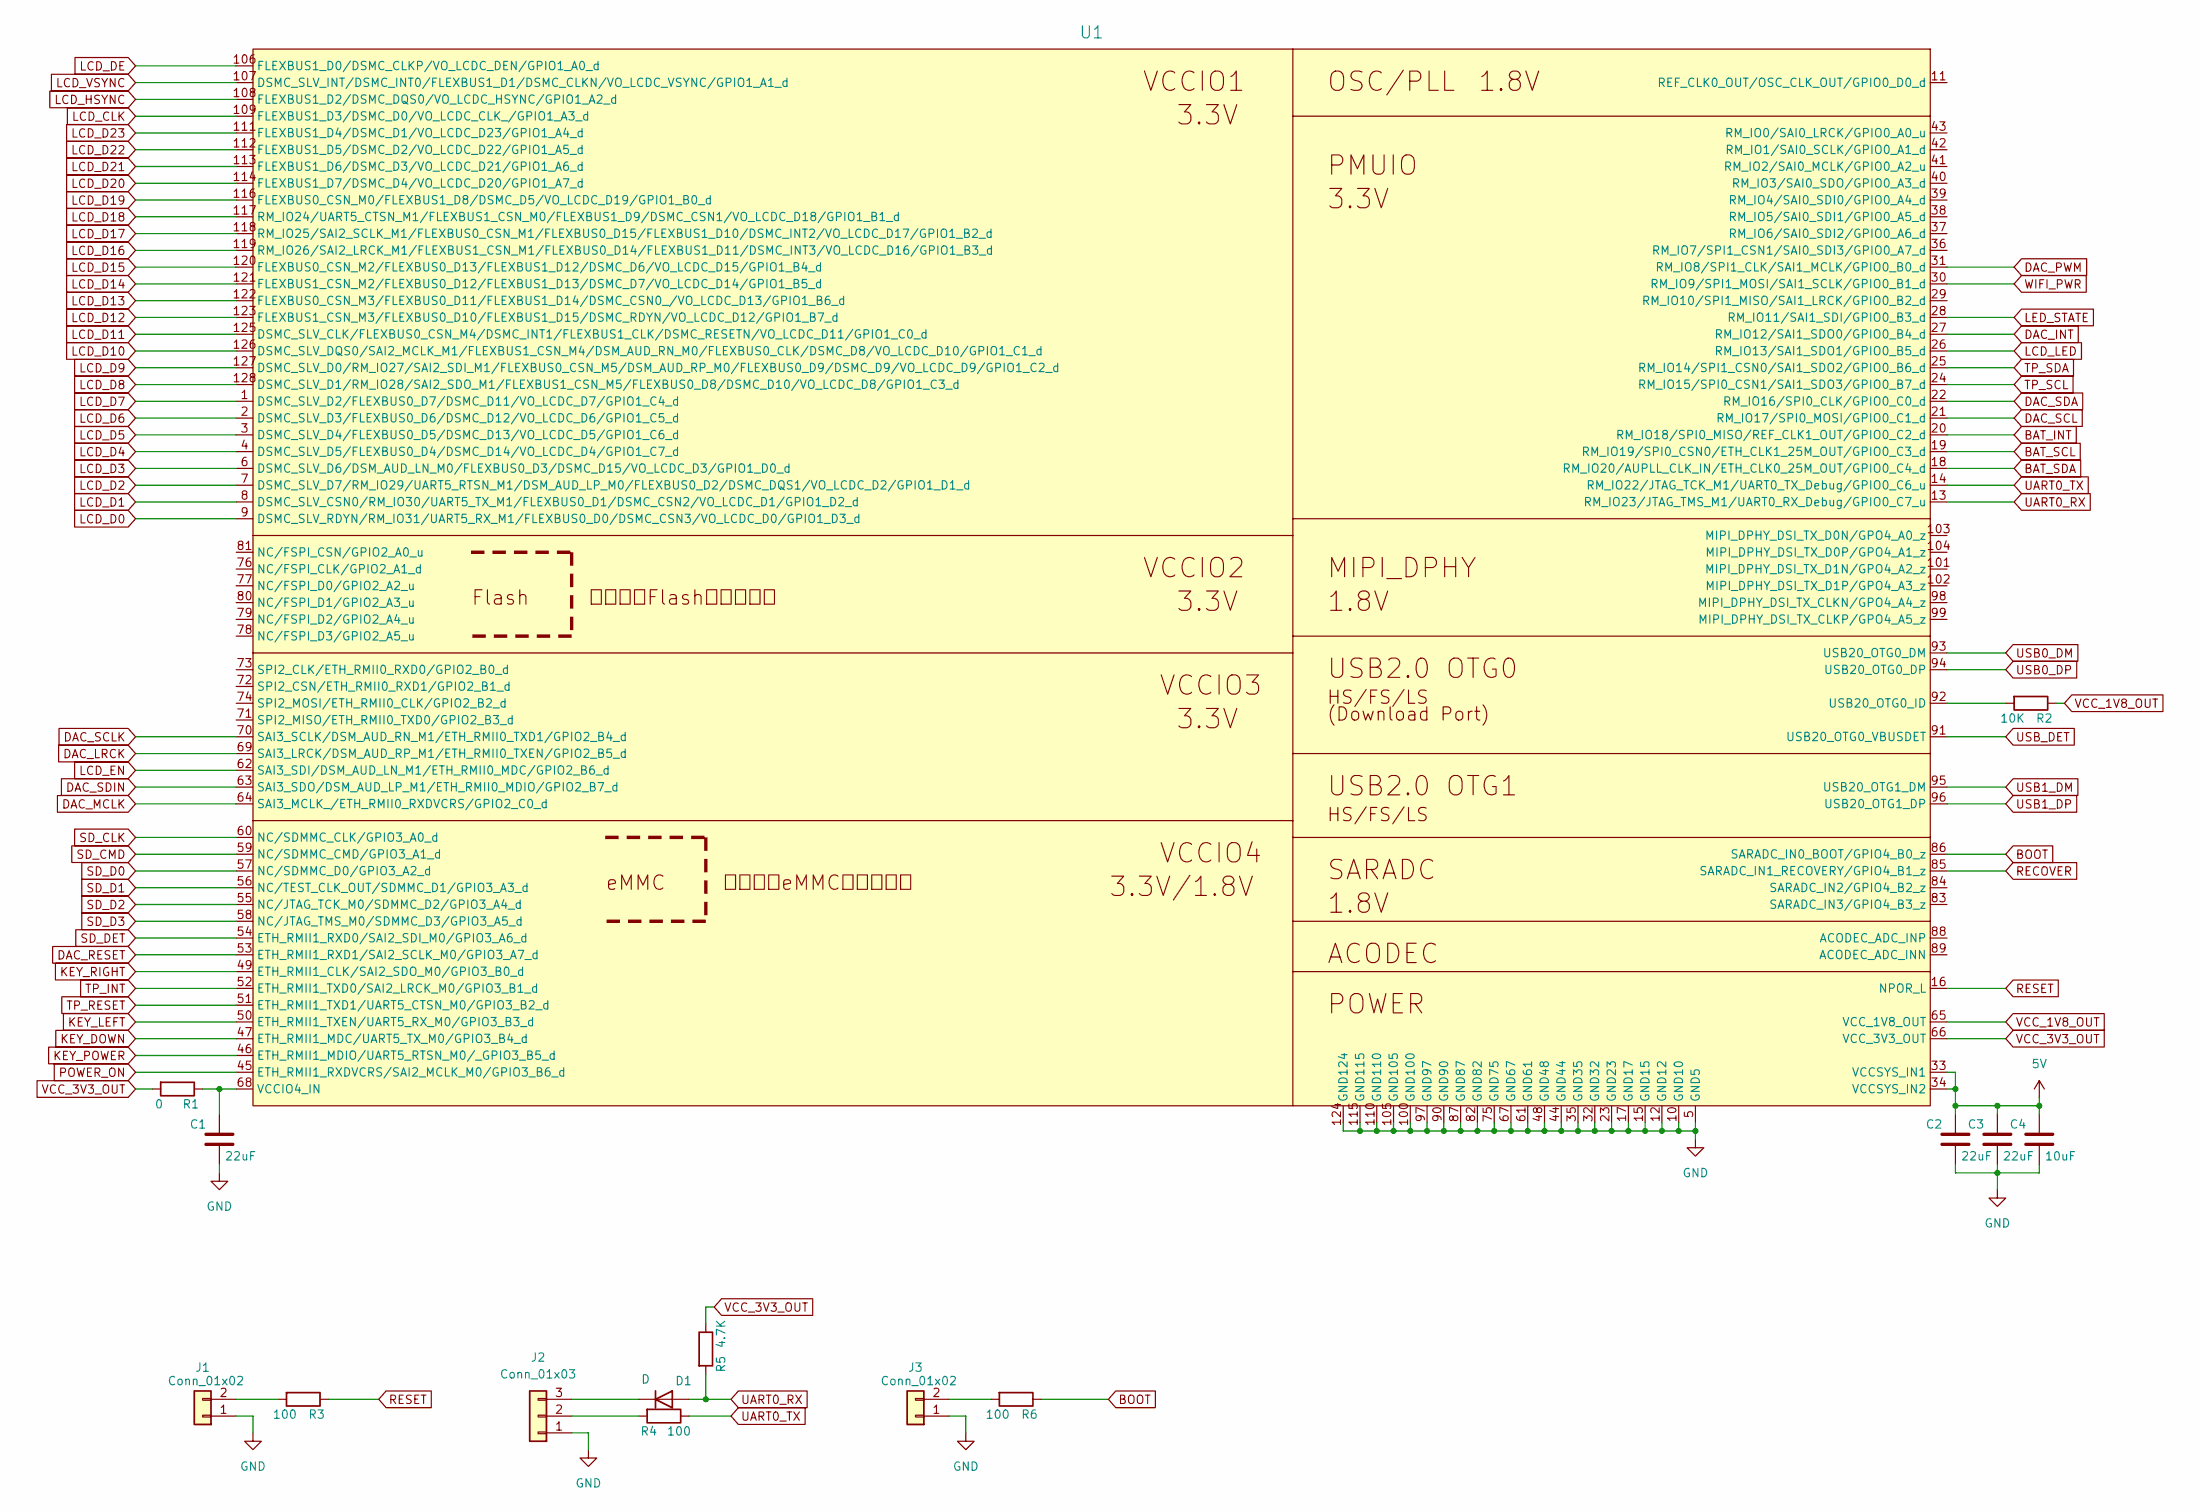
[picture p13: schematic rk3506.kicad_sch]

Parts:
C1, C2, C3: 22uF; C_0603_1608Metric_Pad1.08x0.95mm_HandSolder
C4: 10uF; C_0402_1005Metric_Pad0.74x0.62mm_HandSolder
D1: D; D_SOD-323_HandSoldering
J1, J3: Conn_01x02; PinHeader_1x02_P2.00mm_Vertical
J2: Conn_01x03; PinHeader_1x03_P2.00mm_Vertical
R1: 0; R_0402_1005Metric_Pad0.72x0.64mm_HandSolder
R2: 10K; R_0402_1005Metric_Pad0.72x0.64mm_HandSolder
R3, R4, R6: 100; R_0402_1005Metric_Pad0.72x0.64mm_HandSolder
R5: 4.7K; R_0402_1005Metric_Pad0.72x0.64mm_HandSolder
U1: SOM3562_18; rk3506

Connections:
5V: C2.1, C3.1, C4.1, U1.33 (VCCSYS_IN1), U1.34 (VCCSYS_IN2); also elsewhere on the board
BAT_INT: U1.20 (RM_IO18/SPI0_MISO/REF_CLK1_OUT/GPIO0_C2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); also elsewhere on the board
BAT_SCL: U1.19 (RM_IO19/SPI0_CSN0/ETH_CLK1_25M_OUT/GPIO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); also elsewhere on the board
BAT_SDA: U1.18 (RM_IO20/AUPLL_CLK_IN/ETH_CLK0_25M_OUT/G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); also elsewhere on the board
BOOT: R6.1, U1.86 (SARADC_IN0_BOOT/GPIO4_B0_z)
DAC_INT: U1.27 (RM_IO12/SAI1_SDO0/GPIO0_B4_d); also elsewhere on the board
DAC_LRCK: U1.69 (SAI3_LRCK/DSM_AUD_RP_M1/ETH_RMII0_TXEN/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); also elsewhere on the board
DAC_MCLK: U1.64 (SAI3_MCLK_/ETH_RMII0_RXDVCRS/GPIO2_C0_d); also elsewhere on the board
DAC_PWM: U1.31 (RM_IO8/SPI1_CLK/SAI1_MCLK/GPIO0_B0_d); also elsewhere on the board
DAC_RESET: U1.53 (ETH_RMII1_RXD1/SAI2_SCLK_M0/GPIO3_A7_d); also elsewhere on the board
DAC_SCL: U1.21 (RM_IO17/SPI0_MOSI/GPIO0_C1_d); also elsewhere on the board
DAC_SCLK: U1.70 (SAI3_SCLK/DSM_AUD_RN_M1/ETH_RMII0_TXD1/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); also elsewhere on the board
DAC_SDA: U1.22 (RM_IO16/SPI0_CLK/GPIO0_C0_d); also elsewhere on the board
DAC_SDIN: U1.63 (SAI3_SDO/DSM_AUD_LP_M1/ETH_RMII0_MDIO/G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); also elsewhere on the board
GND: C1.2, C2.2, C3.2, C4.2, J1.1, J2.1, J3.1, U1.5 (GND5), U1.10 (GND10), U1.12 (GND12), U1.15 (GND15), U1.17 (GND17), U1.23 (GND23), U1.32 (GND32), U1.35 (GND35), U1.44 (GND44), U1.48 (GND48), U1.61 (GND61), U1.67 (GND67), U1.75 (GND75), U1.82 (GND82), U1.87 (GND87), U1.90 (GND90), U1.97 (GND97), U1.100 (GND100), U1.105 (GND105), U1.110 (GND110), U1.115 (GND115), U1.124 (GND124); also elsewhere on the board
KEY_DOWN: U1.47 (ETH_RMII1_MDC/UART5_TX_M0/GPIO3_B4_d); also elsewhere on the board
KEY_LEFT: U1.50 (ETH_RMII1_TXEN/UART5_RX_M0/GPIO3_B3_d); also elsewhere on the board
KEY_POWER: U1.46 (ETH_RMII1_MDIO/UART5_RTSN_M0/_GPIO3_B5_d); also elsewhere on the board
KEY_RIGHT: U1.49 (ETH_RMII1_CLK/SAI2_SDO_M0/GPIO3_B0_d); also elsewhere on the board
LCD_CLK: U1.109 (FLEXBUS1_D3/DSMC_D0/VO_LCDC_CLK_/GPIO1_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); also elsewhere on the board
LCD_D0: U1.9 (DSMC_SLV_RDYN/RM_IO31/UART5_RX_M1/FLEXB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); also elsewhere on the board
LCD_D1: U1.8 (DSMC_SLV_CSN0/RM_IO30/UART5_TX_M1/FLEXB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); also elsewhere on the board
LCD_D2: U1.7 (DSMC_SLV_D7/RM_IO29/UART5_RTSN_M1/DSM_A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); also elsewhere on the board
LCD_D3: U1.6 (DSMC_SLV_D6/DSM_AUD_LN_M0/FLEXBUS0_D3/D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); also elsewhere on the board
LCD_D4: U1.4 (DSMC_SLV_D5/FLEXBUS0_D4/DSMC_D14/VO_LCD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); also elsewhere on the board
LCD_D5: U1.3 (DSMC_SLV_D4/FLEXBUS0_D5/DSMC_D13/VO_LCD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); also elsewhere on the board
LCD_D6: U1.2 (DSMC_SLV_D3/FLEXBUS0_D6/DSMC_D12/VO_LCD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); also elsewhere on the board
LCD_D7: U1.1 (DSMC_SLV_D2/FLEXBUS0_D7/DSMC_D11/VO_LCD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); also elsewhere on the board
LCD_D8: U1.128 (DSMC_SLV_D1/RM_IO28/SAI2_SDO_M1/FLEXBUS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); also elsewhere on the board
LCD_D9: U1.127 (DSMC_SLV_D0/RM_IO27/SAI2_SDI_M1/FLEXBUS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); also elsewhere on the board
LCD_D10: U1.126 (DSMC_SLV_DQS0/SAI2_MCLK_M1/FLEXBUS1_CSN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); also elsewhere on the board
LCD_D11: U1.125 (DSMC_SLV_CLK/FLEXBUS0_CSN_M4/DSMC_INT1/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); also elsewhere on the board
LCD_D12: U1.123 (FLEXBUS1_CSN_M3/FLEXBUS0_D10/FLEXBUS1_D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); also elsewhere on the board
LCD_D13: U1.122 (FLEXBUS0_CSN_M3/FLEXBUS0_D11/FLEXBUS1_D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); also elsewhere on the board
LCD_D14: U1.121 (FLEXBUS1_CSN_M2/FLEXBUS0_D12/FLEXBUS1_D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); also elsewhere on the board
LCD_D15: U1.120 (FLEXBUS0_CSN_M2/FLEXBUS0_D13/FLEXBUS1_D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); also elsewhere on the board
LCD_D16: U1.119 (RM_IO26/SAI2_LRCK_M1/FLEXBUS1_CSN_M1/FL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); also elsewhere on the board
LCD_D17: U1.118 (RM_IO25/SAI2_SCLK_M1/FLEXBUS0_CSN_M1/FL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); also elsewhere on the board
LCD_D18: U1.117 (RM_IO24/UART5_CTSN_M1/FLEXBUS1_CSN_M0/F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); also elsewhere on the board
LCD_D19: U1.116 (FLEXBUS0_CSN_M0/FLEXBUS1_D8/DSMC_D5/VO_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); also elsewhere on the board
LCD_D20: U1.114 (FLEXBUS1_D7/DSMC_D4/VO_LCDC_D20/GPIO1_A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); also elsewhere on the board
LCD_D21: U1.113 (FLEXBUS1_D6/DSMC_D3/VO_LCDC_D21/GPIO1_A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); also elsewhere on the board
LCD_D22: U1.112 (FLEXBUS1_D5/DSMC_D2/VO_LCDC_D22/GPIO1_A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); also elsewhere on the board
LCD_D23: U1.111 (FLEXBUS1_D4/DSMC_D1/VO_LCDC_D23/GPIO1_A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); also elsewhere on the board
LCD_DE: U1.106 (FLEXBUS1_D0/DSMC_CLKP/VO_LCDC_DEN/GPIO1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); also elsewhere on the board
LCD_EN: U1.62 (SAI3_SDI/DSM_AUD_LN_M1/ETH_RMII0_MDC/GP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); also elsewhere on the board
LCD_HSYNC: U1.108 (FLEXBUS1_D2/DSMC_DQS0/VO_LCDC_HSYNC/GPI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); also elsewhere on the board
LCD_LED: U1.26 (RM_IO13/SAI1_SDO1/GPIO0_B5_d); also elsewhere on the board
LCD_VSYNC: U1.107 (DSMC_SLV_INT/DSMC_INT0/FLEXBUS1_D1/DSMC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); also elsewhere on the board
LED_STATE: U1.28 (RM_IO11/SAI1_SDI/GPIO0_B3_d); also elsewhere on the board
unnamed: D1.1 (K), J2.3
unnamed: J1.2, R3.2
unnamed: J2.2, R4.2
unnamed: J3.2, R6.2
unnamed: R2.2, U1.92 (USB20_OTG0_ID)
unnamed: C1.1, R1.1, U1.68 (VCCIO4_IN)
POWER_ON: U1.45 (ETH_RMII1_RXDVCRS/SAI2_MCLK_M0/GPIO3_B6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); also elsewhere on the board
RECOVER: U1.85 (SARADC_IN1_RECOVERY/GPIO4_B1_z); also elsewhere on the board
RESET: R3.1, U1.16 (NPOR_L)
SD_CLK: U1.60 (NC/SDMMC_CLK/GPIO3_A0_d); also elsewhere on the board
SD_CMD: U1.59 (NC/SDMMC_CMD/GPIO3_A1_d); also elsewhere on the board
SD_D0: U1.57 (NC/SDMMC_D0/GPIO3_A2_d); also elsewhere on the board
SD_D1: U1.56 (NC/TEST_CLK_OUT/SDMMC_D1/GPIO3_A3_d); also elsewhere on the board
SD_D2: U1.55 (NC/JTAG_TCK_M0/SDMMC_D2/GPIO3_A4_d); also elsewhere on the board
SD_D3: U1.58 (NC/JTAG_TMS_M0/SDMMC_D3/GPIO3_A5_d); also elsewhere on the board
SD_DET: U1.54 (ETH_RMII1_RXD0/SAI2_SDI_M0/GPIO3_A6_d); also elsewhere on the board
TP_INT: U1.52 (ETH_RMII1_TXD0/SAI2_LRCK_M0/GPIO3_B1_d); also elsewhere on the board
TP_RESET: U1.51 (ETH_RMII1_TXD1/UART5_CTSN_M0/GPIO3_B2_d); also elsewhere on the board
TP_SCL: U1.24 (RM_IO15/SPI0_CSN1/SAI1_SDO3/GPIO0_B7_d); also elsewhere on the board
TP_SDA: U1.25 (RM_IO14/SPI1_CSN0/SAI1_SDO2/GPIO0_B6_d); also elsewhere on the board
UART0_RX: D1.2 (A), R5.2, U1.13 (RM_IO23/JTAG_TMS_M1/UART0_RX_Debug/GPIO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)
UART0_TX: R4.1, U1.14 (RM_IO22/JTAG_TCK_M1/UART0_TX_Debug/GPIO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)
USB0_DM: U1.93 (USB20_OTG0_DM); also elsewhere on the board
USB0_DP: U1.94 (USB20_OTG0_DP); also elsewhere on the board
USB1_DM: U1.95 (USB20_OTG1_DM); also elsewhere on the board
USB1_DP: U1.96 (USB20_OTG1_DP); also elsewhere on the board
USB_DET: U1.91 (USB20_OTG0_VBUSDET); also elsewhere on the board
VCC_1V8_OUT: R2.1, U1.65 (VCC_1V8_OUT)
VCC_3V3_OUT: R1.2, R5.1, U1.66 (VCC_3V3_OUT)
WIFI_PWR: U1.30 (RM_IO9/SPI1_MOSI/SAI1_SCLK/GPIO0_B1_d); also elsewhere on the board

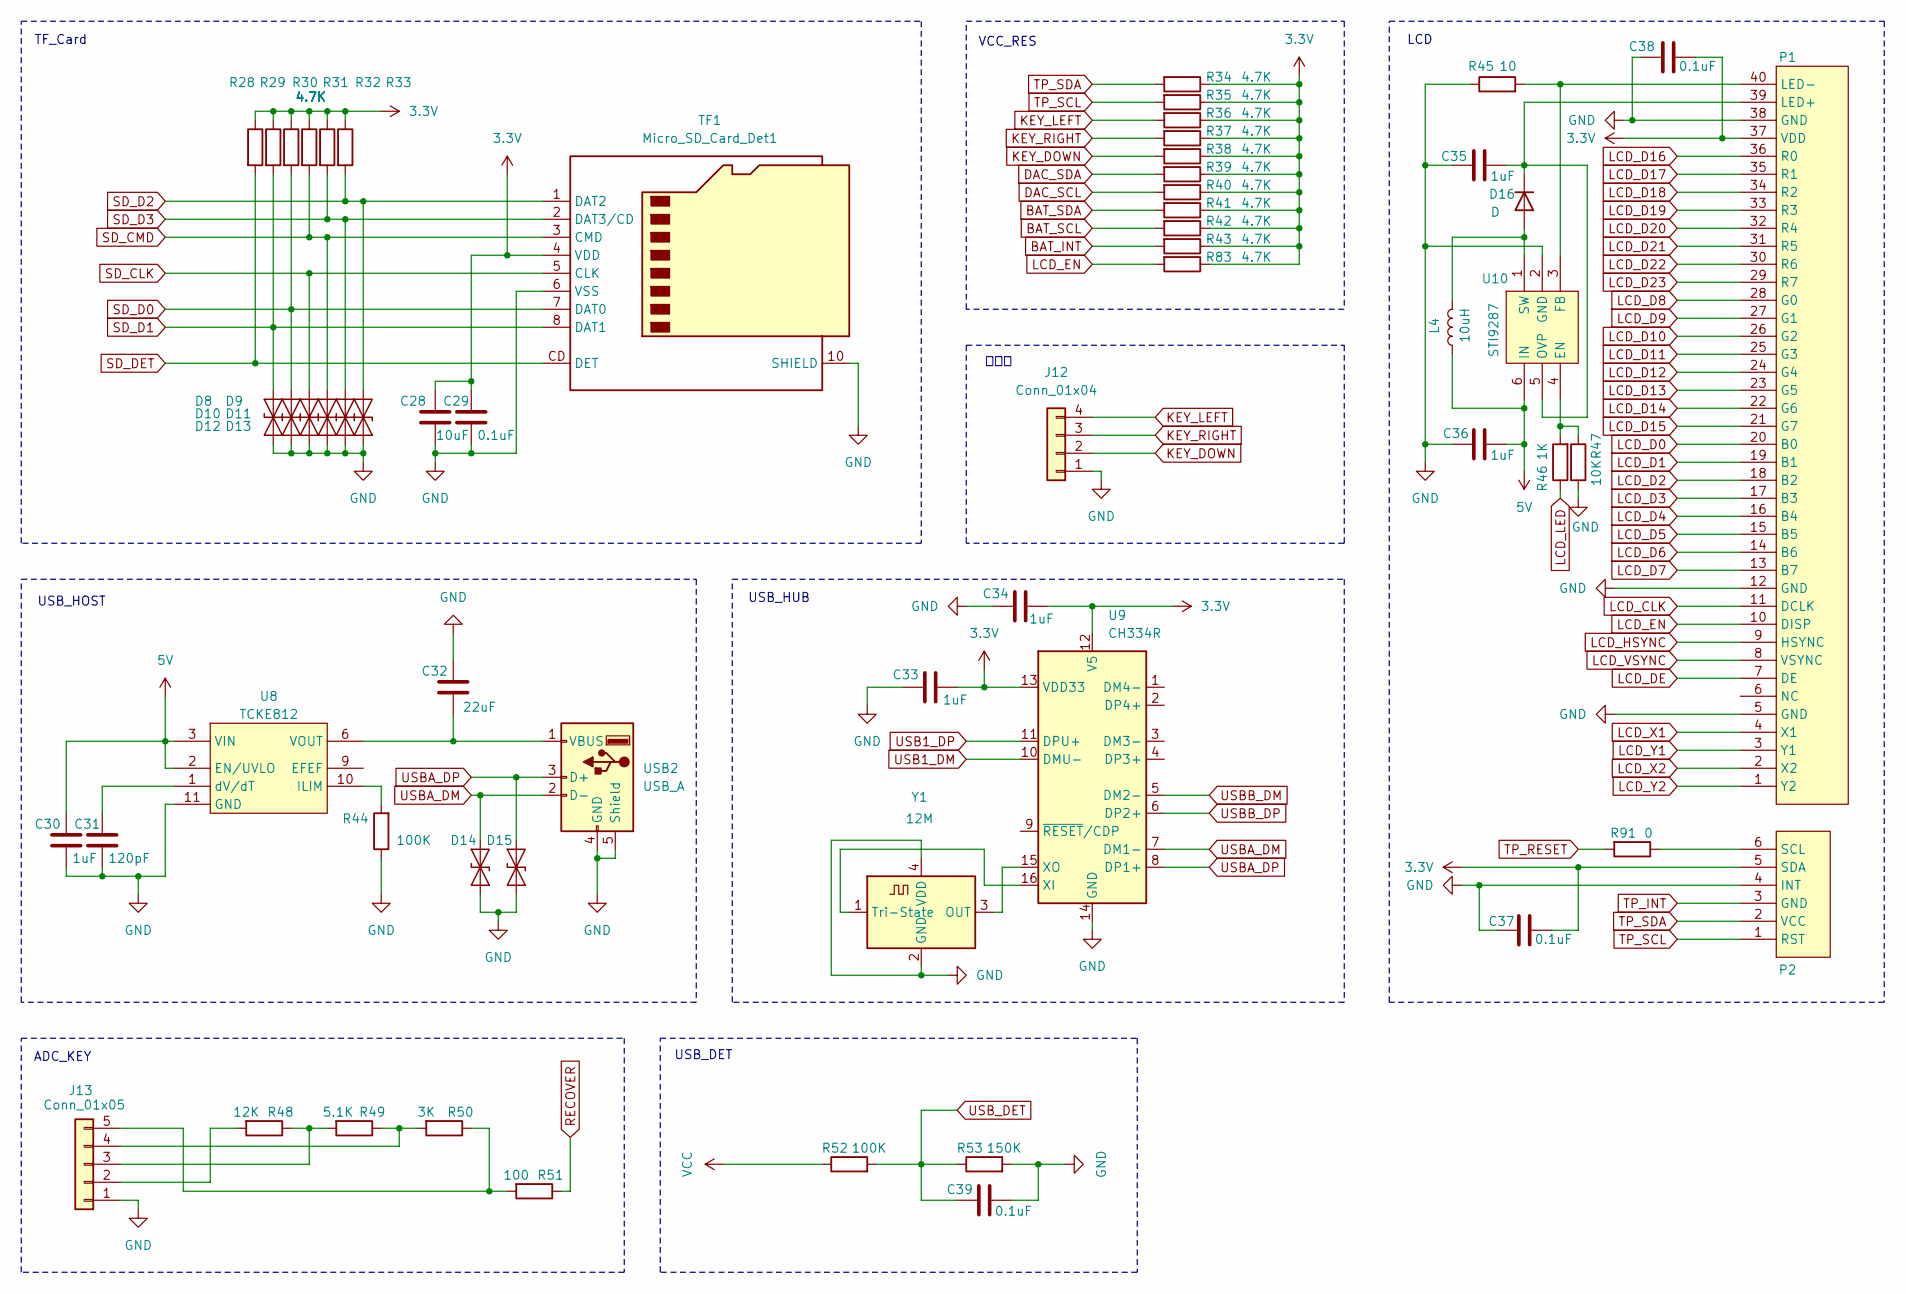
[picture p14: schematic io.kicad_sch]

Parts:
C28: 10uF; C_0402_1005Metric_Pad0.74x0.62mm_HandSolder
C29, C37, C38, C39: 0.1uF; C_0402_1005Metric_Pad0.74x0.62mm_HandSolder
C30, C33, C34, C35, C36: 1uF; C_0402_1005Metric_Pad0.74x0.62mm_HandSolder
C31: 120pF; C_0402_1005Metric_Pad0.74x0.62mm_HandSolder
C32: 22uF; C_0603_1608Metric_Pad1.08x0.95mm_HandSolder
D8, D9, D10, D11, D12, D13, D14, D15: ESD9B5.0ST5G; D_SOD-523
D16: D; D_SOD-323_HandSoldering
J12: Conn_01x04; PinHeader_1x04_P2.00mm_Vertical
J13: Conn_01x05; PinHeader_1x05_P2.00mm_Vertical
L4: 10uH; L_TDK_NLV25_2.5x2.0mm
P1: Hirose_FH12-40S-0.5SH_1x40-1MP_P0.50mm_Horizontal
P2: Hirose_FH12-6S-0.5SH_1x06-1MP_P0.50mm_Horizontal
R28, R29, R30, R31, R32, R33: 4.7K; R_0402_1005Metric_Pad0.72x0.64mm_HandSolder
R34, R35, R36, R37, R38, R39, R40, R41, R42, R43, R83: 4.7K; C_0402_1005Metric_Pad0.74x0.62mm_HandSolder
R44: 100K; C_0402_1005Metric_Pad0.74x0.62mm_HandSolder
R45: 10; R_2512_6332Metric_Pad1.40x3.35mm_HandSolder
R46: 1K; R_0402_1005Metric_Pad0.72x0.64mm_HandSolder
R47: 10K; R_0402_1005Metric_Pad0.72x0.64mm_HandSolder
R48: 12K; R_0402_1005Metric_Pad0.72x0.64mm_HandSolder
R49: 5.1K; R_0402_1005Metric_Pad0.72x0.64mm_HandSolder
R50: 3K; R_0402_1005Metric_Pad0.72x0.64mm_HandSolder
R51: 100; R_0402_1005Metric_Pad0.72x0.64mm_HandSolder
R52: 100K; R_0402_1005Metric_Pad0.72x0.64mm_HandSolder
R53: 150K; R_0402_1005Metric_Pad0.72x0.64mm_HandSolder
R91: 0; R_0402_1005Metric_Pad0.72x0.64mm_HandSolder
TF1: Micro_SD_Card_Det1; TF-SMD_TF-PUSH
U8: TCKE812
U9: CH334R; QSOP-16_3.9x4.9mm_P0.635mm
U10: STI9287; SOT-23-6_Handsoldering
USB2: USB_A; USB-A-TH_AF-ZJWG
Y1: 12M; Oscillator_SMD_ECS_2520MV-xxx-xx-4Pin_2.5x2.0mm

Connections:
3.3V: C28.1, C29.1, C33.2, C34.2, C37.2, C38.2, P1.37 (VDD), P2.5 (SDA), R28.1, R29.1, R30.1, R31.1, R32.1, R33.1, R34.1, R35.1, R36.1, R37.1, R38.1, R39.1, R40.1, R41.1, R42.1, R43.1, R83.1, TF1.4 (VDD), U9.12 (V5), U9.13 (VDD33); also elsewhere on the board
5V: C30.1, C36.2, L4.1, U8.2 (EN/UVLO), U8.3 (VIN), U8.4 (VIN), U8.5 (VIN), U10.6 (IN); also elsewhere on the board
BAT_INT: R43.2; also elsewhere on the board
BAT_SCL: R42.2; also elsewhere on the board
BAT_SDA: R41.2; also elsewhere on the board
DAC_SCL: R40.2; also elsewhere on the board
DAC_SDA: R39.2; also elsewhere on the board
GND: C28.2, C29.2, C30.2, C31.2, C32.1, C33.1, C34.1, C35.2, C36.1, C37.1, C38.1, C39.2, D8.1 (A1), D9.1 (A1), D10.1 (A1), D11.1 (A1), D12.1 (A1), D13.1 (A1), D14.1 (A1), D15.1 (A1), J12.1, J13.1, P1.5 (GND), P1.12 (GND), P1.38 (GND), P2.4 (INT), R44.1, R45.1, R47.2, R53.2, TF1.6 (VSS), TF1.10 (SHIELD), TF1.11 (SHIELD), TF1.12 (SHIELD), TF1.13 (SHIELD), U8.11 (GND), U9.14 (GND), U10.2 (GND), USB2.4 (GND), USB2.5 (Shield), Y1.2 (GND), Y1.4 (VDD); also elsewhere on the board
KEY_DOWN: J12.2, R38.2; also elsewhere on the board
KEY_LEFT: J12.4, R36.2; also elsewhere on the board
KEY_RIGHT: J12.3, R37.2; also elsewhere on the board
LCD_CLK: P1.11 (DCLK); also elsewhere on the board
LCD_D0: P1.20 (B0); also elsewhere on the board
LCD_D1: P1.19 (B1); also elsewhere on the board
LCD_D2: P1.18 (B2); also elsewhere on the board
LCD_D3: P1.17 (B3); also elsewhere on the board
LCD_D4: P1.16 (B4); also elsewhere on the board
LCD_D5: P1.15 (B5); also elsewhere on the board
LCD_D6: P1.14 (B6); also elsewhere on the board
LCD_D7: P1.13 (B7); also elsewhere on the board
LCD_D8: P1.28 (G0); also elsewhere on the board
LCD_D9: P1.27 (G1); also elsewhere on the board
LCD_D10: P1.26 (G2); also elsewhere on the board
LCD_D11: P1.25 (G3); also elsewhere on the board
LCD_D12: P1.24 (G4); also elsewhere on the board
LCD_D13: P1.23 (G5); also elsewhere on the board
LCD_D14: P1.22 (G6); also elsewhere on the board
LCD_D15: P1.21 (G7); also elsewhere on the board
LCD_D16: P1.36 (R0); also elsewhere on the board
LCD_D17: P1.35 (R1); also elsewhere on the board
LCD_D18: P1.34 (R2); also elsewhere on the board
LCD_D19: P1.33 (R3); also elsewhere on the board
LCD_D20: P1.32 (R4); also elsewhere on the board
LCD_D21: P1.31 (R5); also elsewhere on the board
LCD_D22: P1.30 (R6); also elsewhere on the board
LCD_D23: P1.29 (R7); also elsewhere on the board
LCD_DE: P1.7 (DE); also elsewhere on the board
LCD_EN: P1.10 (DISP), R83.2; also elsewhere on the board
LCD_HSYNC: P1.9 (HSYNC); also elsewhere on the board
LCD_LED: R46.1; also elsewhere on the board
LCD_VSYNC: P1.8 (VSYNC); also elsewhere on the board
LCD_X1: P1.4 (X1)
LCD_X2: P1.2 (X2)
LCD_Y1: P1.3 (Y1)
LCD_Y2: P1.1 (Y2)
unnamed: D16.2 (A), L4.2, U10.1 (SW)
unnamed: C35.1, D16.1 (K), P1.39 (LED+), U10.5 (OVP)
unnamed: J13.2, R48.2
unnamed: J13.3, R48.1, R49.2
unnamed: J13.4, R49.1, R50.2
unnamed: J13.5, R50.1, R51.2
unnamed: P1.40 (LED-), R45.2, U10.3 (FB)
unnamed: P2.6 (SCL), R91.1
unnamed: R44.2, U8.10 (ILIM)
unnamed: C31.1, U8.1 (dV/dT)
unnamed: U9.16 (XI), Y1.1 (Tri-State)
unnamed: U9.15 (XO), Y1.3 (OUT)
unnamed: R46.2, R47.1, U10.4 (EN)
unnamed: C32.2, U8.6 (VOUT), U8.7 (VOUT), U8.8 (VOUT), USB2.1 (VBUS)
RECOVER: R51.1; also elsewhere on the board
SD_CLK: D10.2 (A2), TF1.5 (CLK); also elsewhere on the board
SD_CMD: D11.2 (A2), R31.2, TF1.3 (CMD); also elsewhere on the board
SD_D0: D9.2 (A2), R30.2, TF1.7 (DAT0); also elsewhere on the board
SD_D1: D8.2 (A2), R29.2, TF1.8 (DAT1); also elsewhere on the board
SD_D2: D13.2 (A2), R33.2, TF1.1 (DAT2); also elsewhere on the board
SD_D3: D12.2 (A2), R32.2, TF1.2 (DAT3/CD); also elsewhere on the board
SD_DET: R28.2, TF1.CD (DET); also elsewhere on the board
TP_INT: P2.3 (GND); also elsewhere on the board
TP_RESET: R91.2; also elsewhere on the board
TP_SCL: P2.1 (RST), R35.2; also elsewhere on the board
TP_SDA: P2.2 (VCC), R34.2; also elsewhere on the board
USB1_DM: U9.10 (DMU-); also elsewhere on the board
USB1_DP: U9.11 (DPU+); also elsewhere on the board
USBA_DM: D14.2 (A2), U9.7 (DM1-), USB2.2 (D-)
USBA_DP: D15.2 (A2), U9.8 (DP1+), USB2.3 (D+)
USBB_DM: U9.5 (DM2-); also elsewhere on the board
USBB_DP: U9.6 (DP2+); also elsewhere on the board
USB_DET: C39.1, R52.2, R53.1; also elsewhere on the board
VCC: R52.1; also elsewhere on the board

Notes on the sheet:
ADC_KEY
VCC_RES
USB_HOST
编码轮
USB_DET
USB_HUB
LCD
TF_Card


Board: 2 copper layers, 118.0 x 67.0 mm, 241 parts (0 on the bottom side), 189 nets.

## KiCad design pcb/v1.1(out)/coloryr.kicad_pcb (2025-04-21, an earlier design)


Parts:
C4, C6, C7, C8: 10uF; C_0402_1005Metric_Pad0.74x0.62mm_HandSolder
C5, C14, C15, C17: 1uF; C_0402_1005Metric_Pad0.74x0.62mm_HandSolder
C9, C10, C11, C12, C13: 22uF; C_0603_1608Metric_Pad1.08x0.95mm_HandSolder
C16: 100uF; CP_EIA-3528-21_Kemet-B_Pad1.50x2.35mm_HandSolder
D1, D2: ESD9B5.0ST5G; D_SOD-523
J6, J7, J9: Conn_01x02; PinHeader_1x02_P2.54mm_Vertical
J8: Conn_01x03; PinHeader_1x03_P2.00mm_Vertical
L1: 2.2uH; L_1008_2520Metric_Pad1.43x2.20mm_HandSolder
Q1, Q2: NPN; SOT-23
Q3: PMOS; SOT-23_Handsoldering
R5, R6: 22R; C_0402_1005Metric_Pad0.74x0.62mm_HandSolder
R7: 1.37M; C_0402_1005Metric_Pad0.74x0.62mm_HandSolder
R8: 549K; C_0402_1005Metric_Pad0.74x0.62mm_HandSolder
R9: 511K; C_0402_1005Metric_Pad0.74x0.62mm_HandSolder
R10: 1.24M; C_0402_1005Metric_Pad0.74x0.62mm_HandSolder
R11, R12, R19, R20: 10K; C_0402_1005Metric_Pad0.74x0.62mm_HandSolder
R13, R14, R15: 2K; C_0402_1005Metric_Pad0.74x0.62mm_HandSolder
R16, R17, R18: 100K; C_0402_1005Metric_Pad0.74x0.62mm_HandSolder
R21: 10M; R_0402_1005Metric_Pad0.72x0.64mm_HandSolder
R22: 20M; L_0402_1005Metric_Pad0.77x0.64mm_HandSolder
R23, R24: 100K; R_0402_1005Metric_Pad0.72x0.64mm_HandSolder
R25: 10K; R_0402_1005Metric_Pad0.72x0.64mm_HandSolder
R26: 0; R_0402_1005Metric_Pad0.72x0.64mm_HandSolder
U2: LM27762; WSON-12-1EP_3x2mm_P0.5mm_EP1x2.65_ThermalVias
U3: SY6918QDC; SY6918
U4: SOT-23-5_HandSoldering
U5: LP5912-3.3DRV; WSON-6-1EP_2x2mm_P0.65mm_EP1x1.6mm_ThermalVias
USB1: USB_C_Plug_USB2.0; USB_C_Receptacle_GCT_USB4085

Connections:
1.8V: C15.1, U4.5 (OUT); also elsewhere on the board
3.3V: C17.1, Q1.3 (C), R26.1, U5.1 (OUT); also elsewhere on the board
5V: C4.1, C14.1, C16.1, J9.2, Q3.3 (D), U2.3 (VIN), U2.8 (EN-), U2.12 (EN+), U4.1 (VIN), U4.3 (CE), U5.4 (EN), U5.6 (IN); also elsewhere on the board
GND: C4.2, C6.1, C7.1, C8.1, C9.2, C10.2, C11.2, C12.2, C13.2, C14.2, C15.2, C16.2, C17.2, D1.1 (A1), D2.1 (A1), J6.1, J7.2, J8.1, J9.1, R8.1, R10.1, R12.1, R13.1, R14.1, R15.1, R17.1, R18.1, R21.1, R23.1, R24.1, U2.1 (PGOOD), U2.4 (GND), U2.13 (PAD), U3.12 (GND), U4.2 (GND), U5.5 (GND), U5.7 (EP), USB1.A1 (GND), USB1.A12 (GND), USB1.B1 (GND), USB1.B12 (GND), USB1.S1 (SHIELD); also elsewhere on the board
GPADC0: R21.2, R22.1; also elsewhere on the board
KEY_IN: J8.3; also elsewhere on the board
unnamed: C10.1, J7.1, L1.2, R20.2, R22.2, U3.5 (BAT)
unnamed: J8.2, Q2.3 (C), Q3.1 (G), R25.1
unnamed: Q1.1 (B), R18.2, R19.1
unnamed: Q1.2 (E), R16.2, R17.2
unnamed: Q2.2 (E), R24.2
unnamed: R5.2, USB1.A7 (D-), USB1.B7 (D-)
unnamed: R6.2, USB1.A6 (D+), USB1.B6 (D+)
unnamed: C5.2, U2.10 (C+)
unnamed: C5.1, U2.9 (C-)
unnamed: C6.2, U2.5 (CP)
unnamed: R7.2, R8.2, U2.2 (FB+)
unnamed: R9.2, R10.2, U2.7 (FB-)
unnamed: R14.2, U3.7 (ICHG)
unnamed: R13.2, U3.3 (IIN)
unnamed: R15.2, U3.9 (ISYS)
unnamed: R20.1, U3.16 (KEY)
unnamed: L1.1, U3.13 (LX)
unnamed: R11.1, R12.2, U3.4 (VDPM)
unnamed: R26.2, U5.3 (PG)
OP+: C7.2, R7.1, U2.11 (OUT+); also elsewhere on the board
OP-: C8.2, R9.1, U2.6 (OUT-); also elsewhere on the board
POWER_ON: Q2.1 (B), R23.2; also elsewhere on the board
POWER_TEST: R16.1; also elsewhere on the board
SYS: C11.1, C12.1, C13.1, Q3.2 (S), R25.2, U3.14 (SYS)
USB0_DM: D2.2 (A2), R5.1; also elsewhere on the board
USB0_DP: D1.2 (A2), R6.1; also elsewhere on the board
VCC: C9.1, J6.2, R11.2, R19.2, U3.15 (VIN), USB1.A4 (VBUS), USB1.A9 (VBUS), USB1.B4 (VBUS), USB1.B9 (VBUS)

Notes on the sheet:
USB_IN_TEST
POWER_SWITCH
LDO
BAT
USB-TypeC

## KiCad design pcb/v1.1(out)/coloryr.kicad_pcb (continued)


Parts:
C1, C2: 10uF; C_0402_1005Metric_Pad0.74x0.62mm_HandSolder
C3: 0.1uF; C_0402_1005Metric_Pad0.74x0.62mm_HandSolder
J1: Conn_01x09; PinHeader_1x09_P2.00mm_Vertical
J2, J3: Conn_01x02; PinHeader_1x02_P2.00mm_Vertical
J4: Conn_01x04; PinHeader_1x04_P2.00mm_Vertical
J5: Conn_01x03; PinHeader_1x03_P2.00mm_Vertical
R1, R4: 33R; C_0402_1005Metric_Pad0.74x0.62mm_HandSolder
R2: 33R; R_0402_1005Metric_Pad0.72x0.64mm_HandSolder
R3: 22R; R_0402_1005Metric_Pad0.72x0.64mm_HandSolder
U1: F133_CORE_V10

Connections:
5V: C1.1, C2.1, C3.1, U1.1 (VIN), U1.2 (VIN), U1.3 (VIN); also elsewhere on the board
BT_CTS: U1.8 (PG9/UART1-CTS/TWI1-SDA/RGMII-RXD3/UART3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); also elsewhere on the board
BT_HOST_WAKE: U1.32 (PE7/NCSI0-D3/UART5-RX/TWI3-SDA/OWA-OUT/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); also elsewhere on the board
BT_REG_ON: U1.33 (PE6/NCSI0-D2/UART5-TX/TWI3-SCK/OWA-IN/D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); also elsewhere on the board
BT_RST: U1.34 (PE5/NCSI0-D1/UART4-RX/TWI2-SDA/LEDC-DO/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); also elsewhere on the board
BT_RTS: U1.7 (PG8/UART1-RTS/TWI1-SCK/RGMII-RXD2/UART3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); also elsewhere on the board
BT_RXD: U1.6 (PG7/UART1-RX/TWI2-SDA/RGMII-TXD3/OWA-IN); also elsewhere on the board
BT_TXD: U1.5 (PG6/UART1-TX/TWI2-SCK/RGMII-TXD2/PWM1); also elsewhere on the board
DAC_LRCK: U1.93 (PG12/I2S1-LRCK/TWI0-SCK/RGMII-TXCTRL/RM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); also elsewhere on the board
DAC_SCL: U1.36 (PE0/NCSI0-HSYNC/UART2-RTS/TWI1-SCK/LCD0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); also elsewhere on the board
DAC_SCLK: U1.94 (PG13/I2S1-BCLK/TWI0-SDA/RGMII-CLKIN/RMI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); also elsewhere on the board
DAC_SDA: U1.37 (PE1/NCSI0-VSYNC/UART2-CTS/TWI1-SDA/LCD0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); also elsewhere on the board
DAC_SDIN: U1.96 (PG15/I2S1-DOUT0/TWI2-SDA/MDIO/I2S1-DIN1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); also elsewhere on the board
FEL: J3.1, U1.16 (FEL)
GND: C1.2, C2.2, C3.2, J2.2, J3.2, J4.4, J5.3, U1.4 (GND), U1.13 (GND), U1.47 (GND); also elsewhere on the board
GPADC0: U1.82 (GPADC0); also elsewhere on the board
KEY_DOWN: J4.3, U1.30 (PE9/NCSI0-D5/UART1-CTS/PWM3/UART3-RX/JT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); also elsewhere on the board
KEY_IN: U1.29 (PE10/NCSI0-D6/UART1-TX/PWM4/IR-RX/JTAG-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); also elsewhere on the board
KEY_LEFT: J4.1, U1.10 (PG11/I2S1-MCLK/TWI3-SDA/EPHY-25M/CLK-FA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); also elsewhere on the board
KEY_RIGHT: J4.2, U1.95 (PG14/I2S1-DIN0/TWI2-SCK/MDC/I2S1-DOUT1/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); also elsewhere on the board
LCD_CLK: R4.1; also elsewhere on the board
LCD_D0: U1.68 (PB2/LCD0-D0/I2S2-DOUT2/TWI0-SDA/I2S2-DI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); also elsewhere on the board
LCD_D1: U1.67 (PB3/LCD0-D1/I2S2-DOUT1/TWI0-SCK/I2S2-DI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); also elsewhere on the board
LCD_D2: U1.41 (PD0/LCD0-D2/LVDS0-V0P/DSI-D0P/TWI0-SCK); also elsewhere on the board
LCD_D3: U1.42 (PD1/LCD0-D3/LVDS0-V0N/DSI-D0N/UART2-TX); also elsewhere on the board
LCD_D4: U1.43 (PD2/LCD0-D4/LVDS0-V1P/DSI-D1P/UART2-RX); also elsewhere on the board
LCD_D5: U1.44 (PD3/LCD0-D5/LVDS0-V1N/DSI-D1N/UART2-RTS); also elsewhere on the board
LCD_D6: U1.45 (PD4/LCD0-D6/LVDS0-V2P/DSI-CKP/UART2-CTS); also elsewhere on the board
LCD_D7: U1.46 (PD5/LCD0-D7/LVDS0-V2N/DSI-CKN/UART5-TX); also elsewhere on the board
LCD_D8: U1.66 (PB4/LCD0-D8/I2S2-DOUT0/TWI1-SCK/I2S2-DI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); also elsewhere on the board
LCD_D9: U1.65 (PB5/LCD0-D9/I2S2-BCLK/TWI1-SDA/PWM0/LCD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); also elsewhere on the board
LCD_D10: U1.48 (PD6/LCD0-D10/LVDS0-CKP/DSI-D2P/UART5-RX); also elsewhere on the board
LCD_D11: U1.49 (PD7/LCD0-D11/LVDS0-CKN/DSI-D2N/UART4-TX); also elsewhere on the board
LCD_D12: U1.50 (PD8/LCD0-D12/LVDS0-V3P/DSI-D3P/UART4-RX); also elsewhere on the board
LCD_D13: U1.51 (PD9/LCD0-D13/LVDS0-V3N/DSI-D3N/PWM6); also elsewhere on the board
LCD_D14: U1.52 (PD10/LCD0-D14/LVDS1-V0P/SPI1-CS/DBI-CSX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); also elsewhere on the board
LCD_D15: U1.53 (PD11/LCD0-D15/LVDS1-V0N/SPI1-CLK/DBI-SC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); also elsewhere on the board
LCD_D16: U1.64 (PB6/LCD0-D16/I2S2-LRCK/TWI3-SCK/PWM1/LC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); also elsewhere on the board
LCD_D17: U1.63 (PB7/LCD0-D17/I2S2-MCLK/TWI3-SDA/IR-RX/L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); also elsewhere on the board
LCD_D18: U1.55 (PD12/LCD0-D18/LVDS1-V1P/SPI1-MOSI/DBI-S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); also elsewhere on the board
LCD_D19: U1.54 (PD13/LCD0-D19/LVDS1-V1N/SPI1-MISO/DBI-S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); also elsewhere on the board
LCD_D20: U1.56 (PD14/LCD0-D20/LVDS1-V2P/SPI1-HOLD/DBI-D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); also elsewhere on the board
LCD_D21: U1.57 (PD15/LCD0-D21/LVDS1-V2N/SPI1-WP/DBI-TE/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); also elsewhere on the board
LCD_D22: U1.58 (PD16/LCD0-D22/LVDS1-CKP/DMIC-DATA3/PWM0); also elsewhere on the board
LCD_D23: U1.59 (PD17/LCD0-D23/LVDS1-CKN/DMIC-DATA2/PWM1); also elsewhere on the board
LCD_DE: U1.61 (PD19/LCD0-DE/LVDS1-V3N/DMIC-DATA0/PWM3); also elsewhere on the board
LCD_HSYNC: U1.40 (PD20/LCD0-HSYNC/TWI2-SCK/DMIC-CLK/PWM4); also elsewhere on the board
LCD_LED: U1.31 (PE8/NCSI0-D4/UART1-RTS/PWM2/UART3-TX/JT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); also elsewhere on the board
LCD_VSYNC: U1.39 (PD21/LCD0-VSYNC/TWI2-SDA/UART1-TX/PWM5); also elsewhere on the board
LCD_X1: U1.76 (TP-X1); also elsewhere on the board
LCD_X2: U1.77 (TP-X2); also elsewhere on the board
LCD_Y1: U1.78 (TP-Y1); also elsewhere on the board
LCD_Y2: U1.79 (TP-Y2); also elsewhere on the board
unnamed: J1.1, U1.14 (FMINL)
unnamed: J1.2, U1.15 (FMINR)
unnamed: J1.3, U1.72 (MICIN_N)
unnamed: J1.4, U1.71 (MICIN_P)
unnamed: J1.5, U1.70 (LINEINL)
unnamed: J1.6, U1.69 (LINEINR)
unnamed: J1.7, U1.74 (HPOUTL)
unnamed: J1.8, U1.73 (HPOUTR)
unnamed: J1.9, U1.75 (HPOUTFB)
unnamed: R4.2, U1.60 (PD18/LCD0-CLK/LVDS1-V3P/DMIC-DATA1/PWM2)
unnamed: R2.1, U1.17 (PF2/SDC0-CLK/UART0-TX/TWI0-SCK/LEDC-DO/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)
unnamed: R3.1, U1.21 (PF6/OWA-OUT/IR-RX/I2S2-MCLK/PWM5)
unnamed: R1.2, U1.89 (PG0/SDC1-CLK/UART3-TX/RGMII-RXCTRL/RMII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)
POWER_ON: U1.38 (PD22/OWA-OUT/IR-RX/UART1-RX/PWM7); also elsewhere on the board
POWER_TEST: U1.28 (PE11/NCSI0-D7/UART1-RX/JTAG-CK/RGMII-TX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); also elsewhere on the board
RESET: J2.1, U1.23 (RESET); also elsewhere on the board
SDIO_CLK: R1.1; also elsewhere on the board
SDIO_CMD: U1.87 (PG1/SDC1-CMD/UART3-RX/RGMII-RXD0/RMII-R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); also elsewhere on the board
SDIO_D0: U1.88 (PG2/SDC1-D0/UART3-RTS/RGMII-RXD1/RMII-R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); also elsewhere on the board
SDIO_D1: U1.90 (PG3/SDC1-D1/UART3-CTS/RGMII-TXCK/RMII-T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); also elsewhere on the board
SDIO_D2: U1.92 (PG4/SDC1-D2/UART5-TX/RGMII-TXD0/RMII-TX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); also elsewhere on the board
SDIO_D3: U1.91 (PG5/SDC1-D3/UART5-RX/RGMII-TXD1/RMII-TX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); also elsewhere on the board
SD_CLK: R2.2; also elsewhere on the board
SD_CMD: U1.18 (PF3/SDC0-CMD/JTAG-DO/I2S2-BCLK); also elsewhere on the board
SD_D0: U1.11 (PF0/SDC0-D1/JTAG-MS/I2S2-DOUT1/I2S2-DIN0); also elsewhere on the board
SD_D1: U1.12 (PF1/SDC0-D0/JTAG-DI/I2S2-DOUT0/I2S2-DIN1); also elsewhere on the board
SD_D2: U1.20 (PF5/SDC0-D2/JTAG-CK/I2S2-LRCK); also elsewhere on the board
SD_D3: U1.19 (PF4/SDC0-D3/UART0-RX/TWI0-SDA/PWM6/IR-TX); also elsewhere on the board
SD_DET: R3.2; also elsewhere on the board
TP_SCL: U1.25 (PE12/TWI2-SCK/NCSI0-FIELD/RGMII-TXD3); also elsewhere on the board
TP_SDA: U1.24 (PE13/TWI2-SDA/PWM5/DMIC-DATA3/RGMII-RXD2); also elsewhere on the board
UART0_RXD: J5.2, U1.26 (PE3/NCSI0-MCLK/UART2-RX/TWI0-SDA/CLK-FA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)
UART0_TXD: J5.1, U1.27 (PE2/NCSI0-PCLK/UART2-TX/TWI0-SCK/CLK-FA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)
USB0_DM: U1.85 (USB0-DM); also elsewhere on the board
USB0_DP: U1.86 (USB0-DP); also elsewhere on the board
USB1_DM: U1.84 (USB1-DM); also elsewhere on the board
USB1_DP: U1.83 (USB1-DP); also elsewhere on the board
WIFI_HOST_WAKE: U1.9 (PG10/PWM3/TWI3-SCK/RGMII-RXCK/CLK-FANOU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); also elsewhere on the board
WIFI_REG_ON: U1.35 (PE4/NCSI0-D0/UART4-TX/TWI2-SCK/CLK-FANO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); also elsewhere on the board


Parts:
C40, C41, C42, C43: 10pF; C_0402_1005Metric_Pad0.74x0.62mm_HandSolder
C44, C45, C46, C47, C54, C61: 0.1uF; C_0402_1005Metric_Pad0.74x0.62mm_HandSolder
C48, C49, C50, C51, C52, C53, C58, C59, C60, C65, C66, C67, C68, C69, C70, C71: 2.2uF; C_0402_1005Metric_Pad0.74x0.62mm_HandSolder
C55, C62, C73, C77: 10uF; C_0402_1005Metric_Pad0.74x0.62mm_HandSolder
C56, C57, C63, C64: 15uF; C_0402_1005Metric_Pad0.74x0.62mm_HandSolder
C72, C76: 1.0uF; C_0402_1005Metric_Pad0.74x0.62mm_HandSolder
C74, C75: 4.7nf; C_0805_2012Metric_Pad1.18x1.45mm_HandSolder
CN1: AUDIO-TH_PJ-3136-B
CN2: AUDIO-TH_PJ-625G
R47, R48, R49, R50, R51, R52: 0; R_0402_1005Metric_Pad0.72x0.64mm_HandSolder
R53, R54, R55, R56: 50; R_0805_2012Metric_Pad1.20x1.40mm_HandSolder
R57, R59: 510; R_0805_2012Metric_Pad1.20x1.40mm_HandSolder
R58, R60: 71.5; R_0805_2012Metric_Pad1.20x1.40mm_HandSolder
R61, R62, R63, R64, R65, R66, R67: 0; R_1206_3216Metric_Pad1.30x1.75mm_HandSolder
R68, R69: 82; R_0805_2012Metric_Pad1.20x1.40mm_HandSolder
U9, U10: 1; QFN-40-1EP_5x5mm_P0.4mm_EP3.6x3.6mm_ThermalVias
U11: OPA1622; Texas_S-PVSON-N10
Y3, Y4: 24.576MHz; Crystal_SMD_3225-4Pin_3.2x2.5mm_HandSoldering
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

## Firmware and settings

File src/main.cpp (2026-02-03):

#include <stdio.h>
#include <stdlib.h>
#include <time.h>
#include <pthread.h>
#include <queue>
#include <semaphore.h>

#include "lvgl.h"
#include "lv_conf.h"

#include "display/lv_port_init.h"
#include "main.h"
#include "ui/ui.h"
#include "ui/info_view.h"
#include "ui/setting_view.h"
#include "ui/lang.h"
#include "sound/sound.h"
#include "sound/sound_fft.h"
#include "input/rime_input.h"
#include "net/http_connect.h"
#include "music/music_player.h"
#include "music/net_music.h"
#include "music/local_music.h"
#include "config/config.h"
#include "wireless/wifi.h"
#include "wireless/bt.h"
#include "io/event.h"
#include "io/gpio.h"
#include "io/wireless.h"
#include "usb/usb_audio.h"

#ifndef BUILD_ARM
#define SDL_MAIN_HANDLED /*To fix SDL's "undefined reference to WinMain" issue*/
#include <SDL2/SDL.h>
#endif

using namespace coloraudio::config;

static int quit = 0;
static pthread_t tid;
static pthread_t work_tid;
static sem_t work_sem;

static bool mode_change;
static main_mode_type now_mode = MAIN_MODE_NONE;
static std::queue<main_work *> work_queue;

static void sigterm_handler(int sig)
{
#ifdef BUILD_ARM
    set_amp_power(false);
#endif
    LV_LOG_USER("ColorAudio Exit %d\n", sig);

    exit(0);
}

static void *work_loop(void *arg)
{
    for (;;)
    {
        sem_wait(&work_sem);
        while (!work_queue.empty())
        {
#ifdef BUILD_ARM
            auto now_work = work_queue.front();
            if (now_work == NULL)
            {
                continue;
            }
            if (now_work->type == MAIN_WORK_USB)
            {
                usb_audio_exit();
            }
            else if (now_work->type == MAIN_WORK_WIFI_POWER)
            {
                if (Config::get_config_wifi_power())
                {
                    view_top_info_display(now_lang->setting_text7);
                    wifi_wait_ready();
                    view_top_info_close();
                }
                else
                {
                    view_top_info_display(now_lang->setting_text8);
                    wifi_wait_deactivate();
                    view_top_info_close();
                }
            }
            else if (now_work->type == MAIN_WORK_WIFI_ENABLE)
            {
                if (Config::get_config_wifi_enable())
                {
                    if (!wifi_have_device())
                    {
                        view_top_error_display(now_lang->setting_text11);
                    }
                    else
                    {
                        view_top_info_display(now_lang->setting_text9);
                        if (wifi_is_wpa_supplicant_running())
                        {
                            wifi_terminate_wpa_supplicant();
                        }
                        wifi_wpa_start();
                        view_top_info_close();
                    }
                }
                else
                {
                    view_top_info_display(now_lang->setting_text10);
                    wifi_terminate_wpa_supplicant();
                    view_top_info_close();
                }
            }
            else if (now_work->type == MAIN_WORK_WIFI_SCAN)
            {
                if (!wifi_have_device() || !wifi_is_wpa_supplicant_running())
                {
                    view_top_error_display(now_lang->setting_text12);
                }
                else
                {
                    std::vector<wifi_item_t> list;
                    if (wifi_scan(list))
                    {
                        view_setting_wifi_list(list);
                    }
                    else
                    {
                        view_top_error_display(now_lang->setting_text13);
                    }
                }
            }
            else if (now_work->type == MAIN_WORK_WIFI_CONNECT)
            {
                if (!wifi_have_device() || !wifi_is_wpa_supplicant_running())
                {
                    view_top_error_display(now_lang->setting_text12);
                }
                else
                {
                    wifi_connect_t *wifi = static_cast<wifi_connect_t *>(now_work->data);
                    std::string ssid = std::string(wifi->ssid);
                    std::string pwd = std::string(wifi->pwd);
                    delete wifi;
                    if (!wifi_connect(ssid, pwd))
                    {
                        view_top_error_display(now_lang->setting_text15);
                    }
                }
            }
            else if (now_work->type == MAIN_WORK_WIFI_DISCONNECT)
            {
                if (!wifi_have_device() || !wifi_is_wpa_supplicant_running())
                {
                    view_top_error_display(now_lang->setting_text12);
                }
                else
                {
                    if (!wifi_remove())
                    {
                        view_top_error_display(now_lang->setting_text19);
                    }
                }
            }
            work_queue.pop();
            delete now_work;
#endif
        }
    }
    return NULL;
}

static void *main_loop(void *arg)
{
    change_mode(Config::get_config_main_mode());

    for (;;)
    {
        usleep(100);
        if (mode_change)
        {
            continue;
        }
        if (now_mode == MAIN_MODE_MUSIC)
        {
            music_run_loop();
        }
        else if (now_mode == MAIN_MODE_BLE)
        {
            view_top_info_display("正在启用蓝牙");
#ifdef BUILD_ARM
            wifi_wait_ready();
#endif
            view_top_info_close();
            bt_run_loop();
        }
        else if (now_mode == MAIN_MODE_USB)
        {
            usb_audio_tick();
        }
    }

    return NULL;
}

main_mode_type get_mode()
{
    return now_mode;
}

void add_work(main_work_type work, void *data)
{
    main_work *item = new main_work();
    item->type = work;
    item->data = data;
    work_queue.push(item);
    sem_post(&work_sem);
}

void change_mode(main_mode_type mode)
{
    if (mode == now_mode)
    {
        return;
    }

    mode_change = true;

    if (now_mode == MAIN_MODE_MUSIC)
    {
        music_close();
    }
    else if (now_mode == MAIN_MODE_BLE)
    {
        bt_stop();
    }
    else if (now_mode == MAIN_MODE_USB)
    {
        add_work(MAIN_WORK_USB, NULL);
        usb_audio_stop();
    }

    if (mode == MAIN_MODE_MUSIC)
    {
        music_go_local();
    }
    else if (mode == MAIN_MODE_BLE)
    {
        bt_init();
    }
    else if (mode == MAIN_MODE_USB)
    {
        usb_audio_start();
    }

    now_mode = mode;
    Config::set_config_main_mode(now_mode);
    Config::save_config();

    mode_change = false;
}

int main(int argc, char **argv)
{
    signal(SIGINT, sigterm_handler);

    Config::load_config();

    alsa_init();
#ifdef BUILD_ARM
    set_amp_power(true);
#endif

    play_init();
    rime_init();
    lv_port_init();

    view_init();
    music_init();
    usb_audio_init();
#ifdef BUILD_ARM
    event_init();
#endif

    sem_init(&work_sem, 0, 0);

    pthread_create(&tid, NULL, main_loop, NULL);
    pthread_setname_np(tid, "main_loop");

    pthread_create(&work_tid, NULL, work_loop, NULL);
    pthread_setname_np(work_tid, "work_loop");

#ifdef BUILD_ARM
    struct timespec ts;
    clock_gettime(CLOCK_MONOTONIC, &ts);
    uint32_t lastTick = ts.tv_sec * 1000 + ts.tv_nsec / 1000000; // 转为毫秒
#else
    uint32_t lastTick = SDL_GetTicks();
#endif
    while (!quit)
    {
        uint32_t current;
#ifdef BUILD_ARM
        clock_gettime(CLOCK_MONOTONIC, &ts);
        current = ts.tv_sec * 1000 + ts.tv_nsec / 1000000; // 转为毫秒
#else
        SDL_Delay(5);
        current = SDL_GetTicks();
#endif
        view_tick();
        lv_tick_inc(current - lastTick); // Update the tick timer. Tick is new for LVGL 9
        lastTick = current;
        lv_task_handler();
    }

    return 0;
}

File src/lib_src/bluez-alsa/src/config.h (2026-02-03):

/* config.h.  Generated from config.h.in by configure.  */
/* config.h.in.  Generated from configure.ac by autoheader.  */

/* Directory for the storage files. */
#define BLUEALSA_STORAGE_DIR "/var/lib/bluealsa"

/* Define to 1 if the debugging is enabled. */
/* #undef DEBUG */

/* Define to 1 if the debug timing is enabled. */
/* #undef DEBUG_TIME */

/* Define to 1 if AAC is enabled. */
#define ENABLE_AAC 1

/* Define to 1 if apt-X is enabled. */
#define ENABLE_APTX 1

/* Define to 1 if apt-X HD is enabled. */
/* #undef ENABLE_APTX_HD */

/* Define to 1 if ASHA G.722 is enabled. */
/* #undef ENABLE_ASHA */

/* Define to 1 if FastStream is enabled. */
/* #undef ENABLE_FASTSTREAM */

/* Define to 1 if HFP codec selection is enabled. */
/* #undef ENABLE_HFP_CODEC_SELECTION */

/* Define to 1 if LC3plus is enabled. */
#define ENABLE_LC3PLUS 1

/* Define to 1 if LC3-SWB is enabled. */
/* #undef ENABLE_LC3_SWB */

/* Define to 1 if LDAC is enabled. */
#define ENABLE_LDAC 1

/* Define to 1 if LHDC is enabled. */
/* #undef ENABLE_LHDC */

/* Define to 1 if Bluetooth LE MIDI is enabled. */
/* #undef ENABLE_MIDI */

/* Define to 1 if MP3LAME is enabled. */
/* #undef ENABLE_MP3LAME */

/* Define to 1 if MPEG is enabled. */
/* #undef ENABLE_MPEG */

/* Define to 1 if MPG123 is enabled. */
/* #undef ENABLE_MPG123 */

/* Define to 1 if mSBC is enabled. */
/* #undef ENABLE_MSBC */

/* Define to 1 if oFono is enabled. */
/* #undef ENABLE_OFONO */

/* Define to 1 if Opus is enabled. */
#define ENABLE_OPUS 1

/* Define to 1 if PAYLOADCHECK is enabled. */
#define ENABLE_PAYLOADCHECK 1

/* Define to 1 if systemd is enabled. */
/* #undef ENABLE_SYSTEMD */

/* Define to 1 if UPower is enabled. */
/* #undef ENABLE_UPOWER */

/* Define to 1 if you have apt-X decode library. */
#define HAVE_APTX_DECODE 1

/* Define to 1 if you have apt-X HD decode library. */
/* #undef HAVE_APTX_HD_DECODE */

/* Define to 1 if you have the <dlfcn.h> header file. */
#define HAVE_DLFCN_H 1

/* Define to 1 if you have the `eventfd' function. */
#define HAVE_EVENTFD 1

/* Define to 1 if you have the <execinfo.h> header file. */
#define HAVE_EXECINFO_H 1

/* Define to 1 if you have the `gettid' function. */
/* #undef HAVE_GETTID */

/* Define to 1 if you have the <inttypes.h> header file. */
#define HAVE_INTTYPES_H 1

/* Define to 1 if you have the <lc3plus.h> header file. */
/* #undef HAVE_LC3PLUS_H */

/* Define to 1 if you have LDAC decode module. */
#define HAVE_LDAC_DECODE 1

/* Define to 1 if you have the libbsd library. */
/* #undef HAVE_LIBBSD */

/* Define to 1 if you have the `SegFault' library (-lSegFault). */
/* #undef HAVE_LIBSEGFAULT */

/* Define to 1 if you have the <minix/config.h> header file. */
/* #undef HAVE_MINIX_CONFIG_H */

/* Define to 1 if you have the `pipe2' function. */
#define HAVE_PIPE2 1

/* Define to 1 if you have the sndfile library. */
/* #undef HAVE_SNDFILE */

/* Define to 1 if you have the `splice' function. */
#define HAVE_SPLICE 1

/* Define to 1 if you have the <stdatomic.h> header file. */
#define HAVE_STDATOMIC_H 1

/* Define to 1 if you have the <stdint.h> header file. */
#define HAVE_STDINT_H 1

/* Define to 1 if you have the <stdio.h> header file. */
#define HAVE_STDIO_H 1

/* Define to 1 if you have the <stdlib.h> header file. */
#define HAVE_STDLIB_H 1

/* Define to 1 if you have the <strings.h> header file. */
#define HAVE_STRINGS_H 1

/* Define to 1 if you have the <string.h> header file. */
#define HAVE_STRING_H 1

/* Define to 1 if you have the <sys/stat.h> header file. */
#define HAVE_SYS_STAT_H 1

/* Define to 1 if you have the <sys/types.h> header file. */
#define HAVE_SYS_TYPES_H 1

/* Define to 1 if you have the <unistd.h> header file. */
#define HAVE_UNISTD_H 1

/* Define to 1 if you have the <wchar.h> header file. */
#define HAVE_WCHAR_H 1

/* Define to the sub-directory where libtool stores uninstalled libraries. */
#define LT_OBJDIR ".libs/"

/* Name of package */
#define PACKAGE "bluez-alsa"

/* Define to the address where bug reports for this package should be sent. */
#define PACKAGE_BUGREPORT "arkadiusz.bokowy@gmail.com"

/* Define to the full name of this package. */
#define PACKAGE_NAME "BlueALSA"

/* Define to the full name and version of this package. */
#define PACKAGE_STRING "BlueALSA v4.3.1-102-ge6c97c9"

/* Define to the one symbol short name of this package. */
#define PACKAGE_TARNAME "bluez-alsa"

/* Define to the home page for this package. */
#define PACKAGE_URL "https://github.com/arkq/bluez-alsa"

/* Define to the version of this package. */
#define PACKAGE_VERSION "v4.3.1-102-ge6c97c9"

/* Define to 1 if all of the C90 standard headers exist (not just the ones
   required in a freestanding environment). This macro is provided for
   backward compatibility; new code need not use it. */
#define STDC_HEADERS 1
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

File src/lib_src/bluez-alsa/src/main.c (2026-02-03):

/*
 * BlueALSA - main.c
 * SPDX-FileCopyrightText: 2016-2025 BlueALSA developers
 * SPDX-License-Identifier: MIT
 */

#if HAVE_CONFIG_H
#include <config.h>
#endif

#include <getopt.h>
#include <libgen.h>
#include <sched.h>
#include <signal.h>
#include <stdbool.h>
#include <stdint.h>
#include <stdio.h>
#include <stdlib.h>
#include <string.h>
#include <strings.h>
#include <syslog.h>
#include <time.h>
#include <unistd.h>

#include <gio/gio.h>
#include <glib-unix.h>
#include <glib.h>

#if ENABLE_LDAC
#include <ldacBT.h>
#endif

#include "a2dp.h"
#include "a2dp-sbc.h"
#include "audio.h"
#include "ba-config.h"
#include "bluez.h"
#include "codec-sbc.h"
#include "error.h"
#include "hfp.h"
#include "storage.h"
#include "shared/a2dp-codecs.h"
#include "shared/defs.h"
#include "shared/log.h"
#include "shared/nv.h"

/* If glib does not support immediate return in case of bus
 * name being owned by some other connection (glib < 2.54),
 * fall back to a default behavior - enter waiting queue. */
#ifndef G_BUS_NAME_OWNER_FLAGS_DO_NOT_QUEUE
#define G_BUS_NAME_OWNER_FLAGS_DO_NOT_QUEUE \
	G_BUS_NAME_OWNER_FLAGS_NONE
#endif

void bluez_alsa_start(GDBusConnection *conn)
{
	ba_config_init();

	srandom(time(NULL));

	a2dp_sbc_sink.enabled = true;
	config.hfp.codecs.cvsd = true;
	config.profile.a2dp_sink = true;
	config.profile.hfp_hf = true;
	config.dbus = conn;

	if (a2dp_seps_init() != ERROR_CODE_OK)
	{
		error("Couldn't initialize ad2p");
		return;
	}

	storage_init(BLUEALSA_STORAGE_DIR);

	bluez_init();
}

void bluez_alsa_close()
{
	bluez_destroy();

	storage_destroy();
}

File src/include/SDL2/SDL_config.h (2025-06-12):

/*
  Simple DirectMedia Layer
  Copyright (C) 1997-2023 Sam Lantinga <slouken@libsdl.org>

  This software is provided 'as-is', without any express or implied
  warranty.  In no event will the authors be held liable for any damages
  arising from the use of this software.

  Permission is granted to anyone to use this software for any purpose,
  including commercial applications, and to alter it and redistribute it
  freely, subject to the following restrictions:

  1. The origin of this software must not be misrepresented; you must not
     claim that you wrote the original software. If you use this software
     in a product, an acknowledgment in the product documentation would be
     appreciated but is not required.
  2. Altered source versions must be plainly marked as such, and must not be
     misrepresented as being the original software.
  3. This notice may not be removed or altered from any source distribution.
*/

#ifndef SDL_config_h_
#define SDL_config_h_

/**
 *  \file SDL_config.h.in
 *
 *  This is a set of defines to configure the SDL features
 */

/* General platform specific identifiers */
#include "SDL_platform.h"

/* C language features */
/* #undef const */
/* #undef inline */
/* #undef volatile */

/* C datatypes */
/* Define SIZEOF_VOIDP for 64/32 architectures */
#if defined(__LP64__) || defined(_LP64) || defined(_WIN64)
#define SIZEOF_VOIDP 8
#else
#define SIZEOF_VOIDP 4
#endif

#define HAVE_GCC_ATOMICS 1
/* #undef HAVE_GCC_SYNC_LOCK_TEST_AND_SET */

/* Comment this if you want to build without any C library requirements */
#define HAVE_LIBC 1
#if HAVE_LIBC

/* Useful headers */
#define STDC_HEADERS 1
#define HAVE_ALLOCA_H 1
#define HAVE_CTYPE_H 1
#define HAVE_FLOAT_H 1
#define HAVE_ICONV_H 1
#define HAVE_INTTYPES_H 1
#define HAVE_LIMITS_H 1
#define HAVE_MALLOC_H 1
#define HAVE_MATH_H 1
#define HAVE_MEMORY_H 1
#define HAVE_SIGNAL_H 1
#define HAVE_STDARG_H 1
#define HAVE_STDDEF_H 1
#define HAVE_STDINT_H 1
#define HAVE_STDIO_H 1
#define HAVE_STDLIB_H 1
#define HAVE_STRINGS_H 1
#define HAVE_STRING_H 1
#define HAVE_SYS_TYPES_H 1
#define HAVE_WCHAR_H 1
#define HAVE_LINUX_INPUT_H 1
/* #undef HAVE_PTHREAD_NP_H */
/* #undef HAVE_LIBUNWIND_H */

/* C library functions */
#define HAVE_DLOPEN 1
#define HAVE_MALLOC 1
#define HAVE_CALLOC 1
#define HAVE_REALLOC 1
#define HAVE_FREE 1
#define HAVE_ALLOCA 1
#ifndef __WIN32__ /* Don't use C runtime versions of these on Windows */
#define HAVE_GETENV 1
#define HAVE_SETENV 1
#define HAVE_PUTENV 1
#define HAVE_UNSETENV 1
#endif
#define HAVE_QSORT 1
#define HAVE_BSEARCH 1
#define HAVE_ABS 1
#define HAVE_BCOPY 1
#define HAVE_MEMSET 1
#define HAVE_MEMCPY 1
#define HAVE_MEMMOVE 1
#define HAVE_MEMCMP 1
#define HAVE_WCSLEN 1
#define HAVE_WCSLCPY 1
#define HAVE_WCSLCAT 1
/* #undef HAVE__WCSDUP */
#define HAVE_WCSDUP 1
#define HAVE_WCSSTR 1
#define HAVE_WCSCMP 1
#define HAVE_WCSNCMP 1
#define HAVE_WCSCASECMP 1
/* #undef HAVE__WCSICMP */
#define HAVE_WCSNCASECMP 1
/* #undef HAVE__WCSNICMP */
#define HAVE_STRLEN 1
#define HAVE_STRLCPY 1
#define HAVE_STRLCAT 1
/* #undef HAVE__STRREV */
/* #undef HAVE__STRUPR */
/* #undef HAVE__STRLWR */
#define HAVE_INDEX 1
#define HAVE_RINDEX 1
#define HAVE_STRCHR 1
#define HAVE_STRRCHR 1
#define HAVE_STRSTR 1
#define HAVE_STRTOK_R 1
/* #undef HAVE_ITOA */
/* #undef HAVE__LTOA */
/* #undef HAVE__UITOA */
/* #undef HAVE__ULTOA */
#define HAVE_STRTOL 1
#define HAVE_STRTOUL 1
/* #undef HAVE__I64TOA */
/* #undef HAVE__UI64TOA */
#define HAVE_STRTOLL 1
#define HAVE_STRTOULL 1
#define HAVE_STRTOD 1
#define HAVE_ATOI 1
#define HAVE_ATOF 1
#define HAVE_STRCMP 1
#define HAVE_STRNCMP 1
/* #undef HAVE__STRICMP */
#define HAVE_STRCASECMP 1
/* #undef HAVE__STRNICMP */
#define HAVE_STRNCASECMP 1
#define HAVE_STRCASESTR 1
#define HAVE_SSCANF 1
#define HAVE_VSSCANF 1
#define HAVE_VSNPRINTF 1
#define HAVE_M_PI 1
#define HAVE_ACOS 1
#define HAVE_ACOSF 1
#define HAVE_ASIN 1
#define HAVE_ASINF 1
#define HAVE_ATAN 1
#define HAVE_ATANF 1
#define HAVE_ATAN2 1
#define HAVE_ATAN2F 1
#define HAVE_CEIL 1
#define HAVE_CEILF 1
#define HAVE_COPYSIGN 1
#define HAVE_COPYSIGNF 1
#define HAVE_COS 1
#define HAVE_COSF 1
#define HAVE_EXP 1
#define HAVE_EXPF 1
#define HAVE_FABS 1
#define HAVE_FABSF 1
#define HAVE_FLOOR 1
#define HAVE_FLOORF 1
#define HAVE_FMOD 1
#define HAVE_FMODF 1
#define HAVE_LOG 1
#define HAVE_LOGF 1
#define HAVE_LOG10 1
#define HAVE_LOG10F 1
#define HAVE_LROUND 1
#define HAVE_LROUNDF 1
#define HAVE_POW 1
#define HAVE_POWF 1
#define HAVE_ROUND 1
#define HAVE_ROUNDF 1
#define HAVE_SCALBN 1
#define HAVE_SCALBNF 1
#define HAVE_SIN 1
#define HAVE_SINF 1
#define HAVE_SQRT 1
#define HAVE_SQRTF 1
#define HAVE_TAN 1
#define HAVE_TANF 1
#define HAVE_TRUNC 1
#define HAVE_TRUNCF 1
#define HAVE_FOPEN64 1
#define HAVE_FSEEKO 1
#define HAVE_FSEEKO64 1
#define HAVE_SIGACTION 1
#define HAVE_SA_SIGACTION 1
#define HAVE_SETJMP 1
#define HAVE_NANOSLEEP 1
#define HAVE_SYSCONF 1
/* #undef HAVE_SYSCTLBYNAME */
#define HAVE_CLOCK_GETTIME 1
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

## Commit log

2025-04-22 up dts
    [power.kicad_sch]
2025-05-26 up fix lcd pcb
    [coloryr.kicad_pcb, coloryr.kicad_sch, io.kicad_sch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]
2025-06-03 up pcb
    [coloryr.kicad_pcb, io.kicad_sch, wifi.kicad_sch]
2025-06-18 up v3
    [coloryr.kicad_pcb, coloryr.kicad_sch, dac.kicad_sch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]
2025-06-26 up pcb v3.2
    [coloryr.kicad_pcb, io.kicad_sch]
2025-06-26 up mipi ok
    [coloryr.kicad_pcb]
2025-06-27 up use new driver
    [coloryr.kicad_pcb, io.kicad_sch]
2025-07-20 up uac
    [coloryr.kicad_pcb, power.kicad_sch]
2026-01-27 up pcb 3.8
    [coloraudio-parameter-flash.txt, coloryr.kicad_pcb]
2026-02-03 pcb 3.9
    [coloryr.kicad_pcb, dac.kicad_sch, io.kicad_sch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]
